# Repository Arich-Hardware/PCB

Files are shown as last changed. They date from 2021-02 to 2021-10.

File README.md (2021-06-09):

# PCB

Emphatic ARICH project PCB designs:

```backplane``` -- Backplane prototype and 9x9 version

```readout_trenz``` -- Prototype readout board using Trenz FPGA module

```siPM_Board``` -- SiPM board accommodating 2x2 SiPM arrays

```sipm-breakout``` -- SiPM board test breakout board

Any other designs in the repo are obsolete.

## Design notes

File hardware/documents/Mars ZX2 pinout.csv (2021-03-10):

Mars ZX2 | Pin Numbers |  | Mars ZX2
Xilinx |  |  | Xilinx
Zynq-7000 |  |  | Zynq-7000
CLG400 |  |  | CLG400
R2 |  |  | R2
18 Aug 2016 |  |  | 18 Aug 2016
Signal Name | Top | Bottom | Signal Name
VCC_MOD | 1 | 2 | GND
VCC_MOD | 3 | 4 | IO_B34_L12_MRCC_U18_P
VCC_MOD | 5 | 6 | IO_B34_L12_MRCC_U19_N
VCC_MOD | 7 | 8 | GND
VCC_MOD | 9 | 10 | IO_B34_L11_SRCC_U14_P
VCC_MOD | 11 | 12 | IO_B34_L11_SRCC_U15_N
PWR_EN | 13 | 14 | GND
GND | 15 | 16 | IO_B34_L21_V17_P
IO_B34_L20_T17_P | 17 | 18 | IO_B34_L21_V18_N
IO_B34_L20_R18_N | 19 | 20 | GND
GND | 21 | 22 | IO_B34_L3_PUDC#_U13_P
IO_B34_L2_T12_P | 23 | 24 | IO_B34_L3_V13_N
IO_B34_L2_U12_N | 25 | 26 | GND
GND | 27 | 28 | IO_B34_L1_T11_P
IO_B34_L18_V16_P | 29 | 30 | IO_B34_L1_T10_N
IO_B34_L18_W16_N | 31 | 32 | GND
GND | 33 | 34 | IO_B34_L4_V12_P
IO_B34_L19_R16_P | 35 | 36 | IO_B34_L4_W13_N
IO_B34_L19_VREF_R17_N | 37 | 38 | GND
GND | 39 | 40 | PWR_GOOD
1.8V Key |  |  | 1.8V Key
VCC_1V35 | 41 | 42 | VCC_1V0_PS
IO_B34_L13_MRCC_N18_P | 43 | 44 | IO_B34_L8_W14_P
IO_B34_L13_MRCC_P19_N | 45 | 46 | IO_B34_L8_Y14_N
GND | 47 | 48 | IO_B34_L6_P14_P
IO_B34_L14_SRCC_N20_P | 49 | 50 | IO_B34_L6_VREF_R14_N
IO_B34_L14_SRCC_P20_N | 51 | 52 | GND
VCC_IO_B34 | 53 | 54 | IO_B34_L5_T14_P
IO_B34_L10_V15_P | 55 | 56 | IO_B34_L5_T15_N
IO_B34_L10_W15_N | 57 | 58 | IO_B34_L9_T16_P
IO_B34_L7_Y16_P | 59 | 60 | IO_B34_L9_U17_N
IO_B34_L7_Y17_N | 61 | 62 | VCC_IO_B34
GND | 63 | 64 | IO_B34_L24_P15_P
IO_B34_L17_Y18_P | 65 | 66 | IO_B34_L24_P16_N
IO_B34_L17_Y19_N | 67 | 68 | IO_B34_L23_N17_P
IO_B34_L22_W18_P | 69 | 70 | IO_B34_L23_P18_N
IO_B34_L22_W19_N | 71 | 72 | GND
VCC_IO_B34 | 73 | 74 | IO_B34_L16_V20_P
IO_B35_L21_AD14_N15_P | 75 | 76 | IO_B34_L16_W20_N
IO_B35_L21_AD14_N16_N | 77 | 78 | IO_B34_L15_T20_P
IO_B35_L7_AD2_M19_P | 79 | 80 | IO_B34_L15_U20_N
IO_B35_L7_AD2_M20_N | 81 | 82 | VCC_IO_B35
GND | 83 | 84 | IO_B35_L23_M14_P
IO_B35_L13_MRCC_H16_P | 85 | 86 | IO_B35_L23_M15_N
IO_B35_L13_MRCC_H17_N | 87 | 88 | GND
VCC_1V8_PS | 89 | 90 | IO_B35_L22_AD7_L14_P
IO_B35_L9_AD3_L19_P | 91 | 92 | IO_B35_L22_AD7_L15_N
IO_B35_L9_AD3_L20_N | 93 | 94 | VCC_1V8_PS
GND | 95 | 96 | IO_B35_L20_AD6_K14_P
IO_B35_L10_AD11_K19_P | 97 | 98 | IO_B35_L20_AD6_J14_N
IO_B35_L10_AD11_J19_N | 99 | 100 | GND
VCC_1V8_PS | 101 | 102 | IO_B35_L19_H15_P
IO_B35_L14_AD4_SRCC_J18_P | 103 | 104 | IO_B35_L19_VREF_G15_N
IO_B35_L14_AD4_SRCC_H18_N | 105 | 106 | VCC_1V8_PS
GND | 107 | 108 | IO_B35_L8_AD10_M17_P
IO_B35_L17_AD5_J20_P | 109 | 110 | IO_B35_L8_AD10_M18_N
IO_B35_L17_AD5_H20_N | 111 | 112 | IO_B35_L12_MRCC_K17_P
IO_B35_L18_AD13_G19_P | 113 | 114 | IO_B35_L12_MRCC_K18_N
IO_B35_L18_AD13_G20_N | 115 | 116 | GND
VCC_IO_B35 | 117 | 118 | IO_B35_L24_AD15_K16_P
IO_B35_L15_AD12_F19_P | 119 | 120 | IO_B35_L24_AD15_J16_N
IO_B35_L15_AD12_F20_N | 121 | 122 | IO_B35_L16_G17_P
IO_B35_L4_D19_P | 123 | 124 | IO_B35_L16_G18_N
IO_B35_L4_D20_N | 125 | 126 | VCC_IO_B35
GND | 127 | 128 | IO_B35_L11_SRCC_L16_P
IO_B35_L1_AD0_C20_P | 129 | 130 | IO_B35_L11_SRCC_L17_N
IO_B35_L1_AD0_B20_N | 131 | 132 | IO_B35_L6_F16_P
IO_B35_L2_AD8_B19_P | 133 | 134 | IO_B35_L6_VREF_F17_N
IO_B35_L2_AD8_A20_N | 135 | 136 | GND
VCC_CFG_MIO_B13 | 137 | 138 | IO_B35_L5_AD9_E18_P
IO_MIO40_B13_L16_W10 | 139 | 140 | IO_B35_L5_AD9_E19_N
IO_MIO41_B13_L16_W9 | 141 | 142 | IO_B35_L3_AD1_E17_P
IO_MIO42_B13_L18_W11 | 143 | 144 | IO_B35_L3_AD1_D18_N
IO_MIO43_B13_L18_Y11 | 145 | 146 | VCC_CFG_MIO_B13
GND | 147 | 148 | IO_MIO48_B13_L11_SRCC_U7
IO_MIO44_B13_L14_SRCC_Y9 | 149 | 150 | IO_MIO49_B13_L11_V7
IO_MIO45_B13_L14_Y8 | 151 | 152 | IO_MIO50_B13_L12_MRCC_T9
IO_MIO46_B13_L19_T5 | 153 | 154 | IO_MIO51_B13_L12_U10
IO_MIO47_B13_L19_U5 | 155 | 156 | GND
GND | 157 | 158 | JTAG_TCK
USB_D_P | 159 | 160 | JTAG_TDI
USB_D_N | 161 | 162 | JTAG_TMS
USB_VBUS | 163 | 164 | JTAG_TDO
USB_ID | 165 | 166 | USB_CPEN
GND | 167 | 168 | - (*6)
ETH_A_N | 169 | 170 | -
ETH_A_P | 171 | 172 | GND
ETH_LED1# | 173 | 174 | I2C_INT#
ETH_LED2# | 175 | 176 | I2C_SDA
ETH_B_N | 177 | 178 | I2C_SCL
ETH_B_P | 179 | 180 | GND
ETH_CTREF | 181 | 182 | FLASH_CLK
ETH_C_N | 183 | 184 | FLASH_DO
ETH_C_P | 185 | 186 | FLASH_DI
- | 187 | 188 | FLASH_CS#
- | 189 | 190 | BOOT_MODE
ETH_D_N | 191 | 192 | PS_SRST#
ETH_D_P | 193 | 194 | FPGA_DONE
GND | 195 | 196 | PS_POR#
VCC_3V3 | 197 | 198 | VMON_1V2
VCC_3V3 | 199 | 200 | VCC_BAT

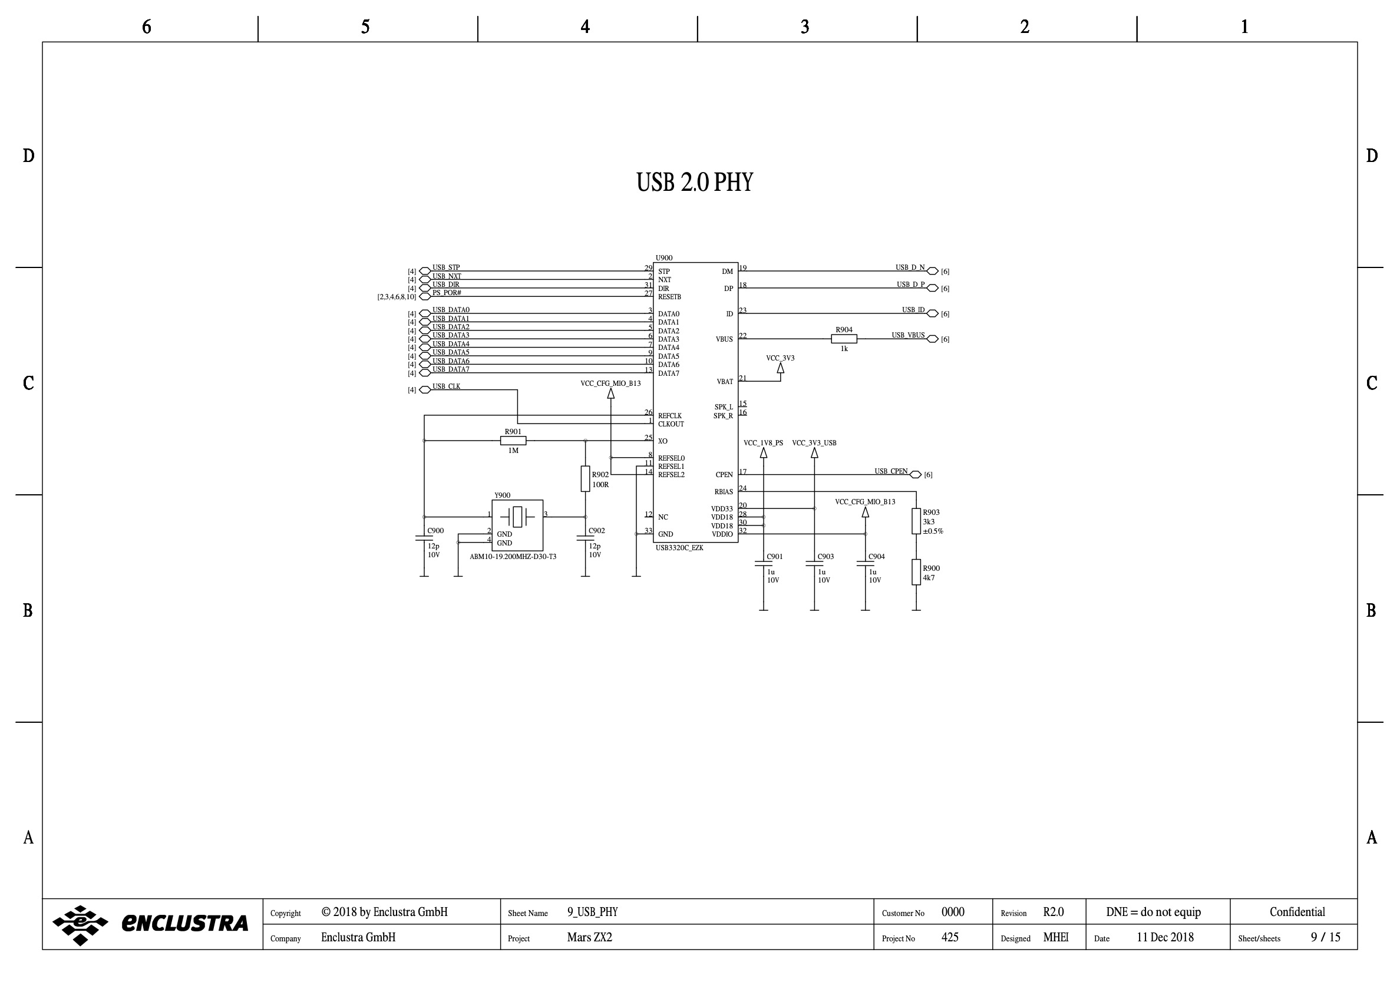
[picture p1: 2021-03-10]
hardware/documents/Mars_ZX2-R2-0_User_Schematics_V3.jpg

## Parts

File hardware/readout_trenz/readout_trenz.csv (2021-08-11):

Reference | Quantity | Value | Footprint | Datasheet | Item Cost | MFN | Manufacturer | Supplier | Supplier P/N
C101 | 1 | 47uF | Capacitor_SMD:C_0805_2012Metric_Pad1.15x1.40mm_HandSolder | https://www.we-online.de/katalog/datasheet/885012107006.pdf | $0.79 | 885012107006 | Würth Elektronik | Digi-Key | 732-7617-1-ND
C179 C181 C183 | 3 | 470uF | readout_trenz:EEE-0JA471UAP | https://industrial.panasonic.com/cdbs/www-data/pdf/RDE0000/ABA0000C1142.pdf | $0.74 | EEE-0JA471UAP | Panasonic Electronic Components | Digi-Key | PCE4564CT-ND
C180 C182 C184 | 3 | 100uF | readout_trenz:EEE-0JA101WR | https://media.digikey.com/pdf/Data%20Sheets/Panasonic%20Electronic%20Components/S_Series,Type_V_Rev2018.pdf | $0.35 | EEE-0JA101WR | Panasonic Electronic Components | Digi-Key | PCE3853CT-ND
C1 C2 C6 C20 C21 C22 C23 C24 C25 C26 C27 C28 C29 C30 C31 C32 C33 C34 C35 C36 C69 C70 C71 C72 C73 C74 C75 C76 C78 C81 C83 C84 C87 C88 C91 C92 C93 C94 C97 C98 C99 C100 C102 C106 C107 C108 C109 C110 C111 C112 C113 C114 C115 C116 C117 C118 C119 C120 C121 C122 C155 C156 C157 C158 C159 C160 C161 C162 C164 C167 C169 C170 C173 C174 C177 C178 | 76 | 0.1uF | Capacitor_SMD:C_0603_1608Metric_Pad1.05x0.95mm_HandSolder | https://www.we-online.de/katalog/datasheet/885012206046.pdf | $0.1 | 885012206046 | Würth Elektronik | Digi-Key | 732-7965-1-ND
C37 C38 C39 C40 C41 C42 C43 C44 C45 C46 C47 C48 C49 C50 C51 C52 C53 C54 C55 C56 C57 C58 C59 C60 C61 C62 C63 C64 C65 C66 C67 C68 C123 C124 C125 C126 C127 C128 C129 C130 C131 C132 C133 C134 C135 C136 C137 C138 C139 C140 C141 C142 C143 C144 C145 C146 C147 C148 C149 C150 C151 C152 C153 C154 | 64 | 0.1uF | Capacitor_SMD:C_0402_1005Metric | https://www.we-online.de/katalog/datasheet/885012205037.pdf | $0.1 | 885012205037 | Würth Elektronik | Digi-Key | 732-7532-1-ND
C4 | 1 | 10nF | Capacitor_SMD:C_0603_1608Metric_Pad1.05x0.95mm_HandSolder | https://www.we-online.de/katalog/datasheet/885342206006.pdf | $0.1 | 885342206006 | Würth Elektronik | Digi-Key | 732-12168-1-ND
C5 | 1 | 2.2uF | Capacitor_SMD:C_0603_1608Metric_Pad1.05x0.95mm_HandSolder | https://www.we-online.de/katalog/datasheet/885012106011.pdf | $0.16 | 885012106011 | Würth Elektronik | Digi-Key | 732-7908-1-ND
C3 C7 C8 C12 C13 C17 C18 C19 C103 C104 C105 | 11 | 1uF | Capacitor_SMD:C_0603_1608Metric_Pad1.05x0.95mm_HandSolder | https://www.we-online.de/katalog/datasheet/885012106010.pdf | $0.15 | 885012106010 | Würth Elektronik | Digi-Key | 732-7907-1-ND
C77 C79 C80 C82 C85 C86 C163 C165 C166 C168 C171 C172 | 12 | 150pF | Capacitor_SMD:C_0603_1608Metric_Pad1.05x0.95mm_HandSolder | https://www.we-online.de/katalog/datasheet/885012206103.pdf | $0.1 | 885012206103 | Würth Elektronik | Digi-Key | 732-12236-1-ND
C9 C10 C11 C14 C15 C16 C89 C90 C175 C176 | 10 | 10uF | Capacitor_SMD:C_0805_2012Metric_Pad1.15x1.40mm_HandSolder | https://www.we-online.de/katalog/datasheet/885012107010.pdf | $0.18 | 885012107010 | Würth Elektronik | Digi-Key | 732-7620-1-ND
C95 C96 | 2 | 22uF | Capacitor_SMD:C_0805_2012Metric_Pad1.15x1.40mm_HandSolder | https://www.we-online.de/katalog/datasheet/885012107011.pdf | $0.59 | 885012107011 | Würth Elektronik | Digi-Key | 732-7621-1-ND
D1 D2 D3 D4 D5 D6 D7 D8 D9 D12 | 10 | Red_LED | LED_THT:LED_D3.0mm | https://www.we-online.de/katalog/datasheet/151031SS06000.pdf | $0.17 | 151031SS06000 | Würth Elektronik | Digi-Key | 732-5006-ND
D10 | 1 | Yellow_LED | LED_THT:LED_D3.0mm | https://www.we-online.de/katalog/datasheet/151031YS05900.pdf | $0.17 | 151031YS05900 | Würth Elektronik | Digi-Key | 732-5009-ND
D11 | 1 | Blue_LED | LED_THT:LED_D3.0mm | https://www.ttelectronics.com/TTElectronics/media/ProductFiles/Optoelectronics/Datasheets/OVLBx4C7.pdf | $0.37 | OVLBB4C7 | TT Electronics/Optek Technology | Digi-Key | 365-1173-ND
D13 | 1 | Green_LED | LED_THT:LED_D3.0mm | https://www.we-online.de/katalog/datasheet/151031VS06000.pdf | $0.16 | 151031VS06000 | Würth Elektronik | Digi-Key | 732-5008-ND
GND1 GND2 GND3 GND4 GND5 GND6 GND7 GND8 | 8 | TestPoint | TestPoint:TestPoint_Keystone_5000-5004_Miniature | https://www.keyelco.com/userAssets/file/M65p56.pdf | $0.42 | 5001 | Keystone Electronics | Digi-Key | 36-5001-ND
H1 H2 | 2 | MountingHole | readout_trenz:MountingHole_0.11'' | ~
J7 J8 J9 J10 J11 J12 | 6 | ERM8-060-05.0-L-DV | readout_trenz:ERM8-060-XX-X-D-RA | http://suddendocs.samtec.com/prints/erm8-xxx-xx-x-d-ra-xx-footprint.pdf | $13.11 | ERM8-060-01-L-D-RA-K-TR | Samtec | Digi-Key | SAM13809CT-ND
J13 | 1 | Digilent JTAG header | readout_trenz:87832-1420 | https://media.digikey.com/pdf/Data%20Sheets/Molex%20PDFs/87832-300_Pkg_Spec.pdf | $2.04 | 0878321420 | Molex | Digi-Key | WM18641-ND
J14 | 1 | SparkfunFT232RL | readout_trenz:Sparkfun-FT232RL | https://cdn.sparkfun.com/datasheets/BreakoutBoards/DS_FT232R.pdf | $15.95 | BOB-12731 | SparkFun Electronics | Digi-Key | 1568-1195-ND
J15 | 1 | TrenzSFP+cage | Connector:Connector_SFP_and_Cage | https://www.te.com/commerce/DocumentDelivery/DDEController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 | $2.65 | 2227023-1, 1888247-1 | TE Connectivity AMP Connectors | Digi-Key | A120615-ND, A97943CT-ND
J16 | 1 | Conn_01x03 | Connector_PinHeader_2.54mm:PinHeader_1x03_P2.54mm_Vertical | https://app.adam-tech.com/products/download/data_sheet/201605/ph1-xx-ua-data-sheet.pdf | $0.1 | PH1-01-UA | Adam Tech | Digi-Key | 2057-PH1-01-UA-ND
J17 | 1 | Trenz_Module | readout_trenz:Trenz_Module | http://suddendocs.samtec.com/catalog_english/lshm_dv.pdf | $10.37 | LSHM-150-04.0-F-DV-A-S-K-TR | Samtec Inc. | Digi-Key | SAM14152CT-ND
J18 | 1 | Conn_02x05_Odd_Even | readout_trenz:10129383-910002ALF | https://cdn.amphenol-icc.com/media/wysiwyg/files/drawing/10129383.pdf | $0.26 | 10129383-910002ALF | Amphenol ICC (FCI) | Digi-Key | 609-10129383-910002ALFCT-ND
J1 J2 J6 J19 | 4 | DNP | readout_trenz:lemo-EPB.00.250.NTN | https://www.lemo.com/pdf/EPB.00.250.NTN.pdf | $20.34 | EPB.00.250.NTN | LEMO | Digi-Key | 1124-1424-ND
J3 | 1 | Conn_Coaxial_Power | Connector_BarrelJack:BarrelJack_Wuerth_6941xx301002 | https://www.we-online.de/katalog/datasheet/6941xx301002.pdf | $0.96 | 694106301002 | Würth Elektronik | Digi-Key | 732-5930-ND
J4 | 1 | Conn_02x05_Odd_Even | Connector_PinHeader_2.54mm:PinHeader_2x04_P2.54mm_Vertical | https://cdn.amphenol-icc.com/media/wysiwyg/files/drawing/10129383.pdf | $0.26 | 10129383-910002ALF | Amphenol ICC (FCI) | Digi-Key | 609-10129383-910002ALFCT-ND
J5 | 1 | DC_TO_DC | readout_trenz:DC_TO_DC | https://media.digikey.com/pdf/Data%20Sheets/Sullins%20PDFs/Female_Headers.100_DS.pdf | $0.71 | PPPC052LFBN-RC | Sullins Connector Solutions | Digi-Key | S7108-ND
JP1 JP2 | 2 | Jumper | Connector_PinHeader_2.54mm:PinHeader_1x02_P2.54mm_Vertical | https://cdn.harwin.com/pdfs/C001XX_M20_Series_Connectors.pdf | $0.19 | M20-9990345 | Harwin Inc. | Digi-Key | 952-2263-ND
L1 L2 | 2 | 4.7uH | readout_trenz:A914BYW-4R7M=P3 | https://search.murata.co.jp/Ceramy/image/img/P02/J(E)TE243B-0045_D52LC_reference.pdf | $0.98 | #A914BYW-4R7M=P3 | Murata Electronics | Digi-Key | 490-#A914BYW-4R7M=P3CT-ND
Q1 Q2 Q3 Q4 Q5 Q6 Q7 | 7 | N-MOSFET | Package_TO_SOT_SMD:SOT-416 | https://fscdn.rohm.com/en/products/databook/datasheet/discrete/transistor/mosfet/re1c002untcl-e.pdf | $0.21 | RE1C002UNTCL | Rohm Semiconductor | Digi-Key | RE1C002UNTCLCT-ND
R11 R58 R59 R60 R66 R67 R68 R69 R70 R119 R120 R121 | 12 | 4.7k | Resistor_SMD:R_1206_3216Metric_Pad1.42x1.75mm_HandSolder | http://www.passivecomponent.com/wp-content/uploads/chipR/ASC_WR.pdf | $0.1 | WR12X4701FTL | Walsin Technology Corporation | Digi-Key | 1292-WR12X4701FTLCT-ND
R12 R13 R14 R71 R72 R74 R75 | 7 | 56 | Resistor_SMD:R_0603_1608Metric_Pad1.05x0.95mm_HandSolder | https://www.yageo.com/upload/media/product/productsearch/datasheet/rchip/PYu-RT_1-to-0.01_RoHS_L_12.pdf | $0.1 | RT0603FRE0756RL | Yageo | Digi-Key | 13-RT0603FRE0756RLCT-ND
R10 R15 R16 | 3 | 80 | Resistor_SMD:R_0603_1608Metric_Pad1.05x0.95mm_HandSolder | https://industrial.panasonic.com/cdbs/www-data/pdf/RDA0000/AOA0000C304.pdf | $0.1 | ERJ-3EKF82R0V | Panasonic Electronic Components | Digi-Key | P82.0HCT-ND
R1 R2 R17 R18 R19 R20 R21 R22 R23 R24 R25 R26 R27 R28 R29 R30 R31 R32 R33 R34 R35 R36 R37 R38 R39 R40 R41 R42 R43 R44 R45 R46 R47 R48 R78 R79 R80 R81 R82 R83 R84 R85 R86 R87 R88 R89 R90 R91 R92 R93 R94 R95 R96 R97 R98 R99 R100 R101 R102 R103 R104 R105 R106 R107 R108 R109 | 66 | 49.9 | Resistor_SMD:R_0402_1005Metric | https://www.yageo.com/upload/media/product/productsearch/datasheet/rchip/PYu-AF_51_RoHS_L_6.pdf | $0.1 | AF0402FR-0749R9L | Yageo | Digi-Key | 13-AF0402FR-0749R9LCT-ND
R3 R4 R56 R57 R117 R118 | 6 | 100 | Resistor_SMD:R_0603_1608Metric_Pad1.05x0.95mm_HandSolder | https://www.bourns.com/docs/product-datasheets/crxxxxa.pdf | $0.01 | CR0603AFX-1000ELF | Bourns Inc. | Digi-Key | 118-CR0603AFX-1000ELFCT-ND
R49 R50 R51 R52 R53 R54 R55 R110 R111 R112 R113 R114 R115 R116 | 14 | 1k | Resistor_SMD:R_0603_1608Metric_Pad1.05x0.95mm_HandSolder | https://www.yageo.com/upload/media/product/productsearch/datasheet/rchip/PYu-RC_Group_51_RoHS_L_11.pdf | $0.1 | RC0603JR-071KL | Yageo | Digi-Key | 311-1.0KGRCT-ND
R5 | 1 | 470 | Resistor_SMD:R_0805_2012Metric_Pad1.15x1.40mm_HandSolder | https://industrial.panasonic.com/cdbs/www-data/pdf/RDM0000/AOA0000C307.pdf | $0.1 | ERA-6AED471V | Panasonic Electronic Components | Digi-Key | P123851CT-ND
R6 | 1 | 140 | Resistor_SMD:R_0603_1608Metric_Pad1.05x0.95mm_HandSolder | https://www.yageo.com/upload/media/product/productsearch/datasheet/rchip/PYu-RC_Group_51_RoHS_L_11.pdf | $0.1 | RC0603FR-07140RL | Yageo | Digi-Key | 311-140HRCT-ND
R61 R62 | 2 | 10k | Resistor_SMD:R_1206_3216Metric_Pad1.42x1.75mm_HandSolder | https://www.vishay.com/docs/28773/crcwce3.pdf | $0.1 | CRCW120610K0FKEAC | Vishay Dale | Digi-Key | 541-3983-1-ND
R63 | 1 | 0.1 | Resistor_SMD:R_0603_1608Metric_Pad1.05x0.95mm_HandSolder | https://industrial.panasonic.com/cdbs/www-data/pdf/RDN0000/AOA0000C313.pdf | $0.23 | ERJ-3RSJR10V | Panasonic Electronic Components | Digi-Key | P.10AHCT-ND
R64 R65 | 2 | 0.5 | Resistor_SMD:R_0603_1608Metric_Pad1.05x0.95mm_HandSolder | https://www.yageo.com/upload/media/product/productsearch/datasheet/rchip/PYu-RL_Group_521_RoHS_L_2.pdf | $0.25 | RL0603JR-070R5L | Yageo | Digi-Key | 13-RL0603JR-070R5LCT-ND
R7 | 1 | 470k | Resistor_SMD:R_1206_3216Metric_Pad1.42x1.75mm_HandSolder | https://www.yageo.com/upload/media/product/productsearch/datasheet/rchip/PYu-RC_Group_51_RoHS_L_11.pdf | $0.1 | RC1206FR-07470KL | Yageo | Digi-Key | 311-470KFRCT-ND
R73 | 1 | 33 | Resistor_SMD:R_0603_1608Metric_Pad1.05x0.95mm_HandSolder | https://www.vishay.com/docs/20035/dcrcwe3.pdf | $0.1 | CRCW060333R0JNEA | Vishay Dale | Digi-Key | 541-33GCT-ND
R76 | 1 | DNP | Resistor_SMD:R_0603_1608Metric_Pad1.05x0.95mm_HandSolder | ~
R77 | 1 | 0 | Resistor_SMD:R_0603_1608Metric_Pad1.05x0.95mm_HandSolder | https://www.yageo.com/upload/media/product/productsearch/datasheet/rchip/PYu-RC_Group_51_RoHS_L_11.pdf | $0.1 | AC0603JR-130RL | Yageo | Digi-Key | 13-AC0603JR-130RLCT-ND
R8 | 1 | 1k | Resistor_SMD:R_0805_2012Metric_Pad1.15x1.40mm_HandSolder | https://www.yageo.com/upload/media/product/productsearch/datasheet/rchip/PYu-RC_Group_51_RoHS_L_11.pdf | $0.1 | RC0805FR-071KL | Yageo | Digi-Key | 311-1.00KCRCT-ND
R9 | 1 | 900 | Resistor_SMD:R_1206_3216Metric_Pad1.42x1.75mm_HandSolder | https://www.vishay.com/docs/60024/pat.pdf | $0.94 | PAT1206E9000BST1 | Vishay Dale Thin Film | Digi-Key | PAT900CCT-ND
RV1 | 1 | 10k | Potentiometer_THT:Potentiometer_ACP_CA6-H2,5_Horizontal | https://www.bourns.com/docs/product-datasheets/3296.pdf | $2.41 | 3296Z-1-103LF | Bourns Inc. | Digi-Key | 3296Z-103LF-ND
TP1 TP2 TP3 TP4 TP5 TP6 TP7 TP8 TP9 TP10 TP11 TP12 TP14 TP15 TP16 TP17 TP18 TP19 TP20 TP21 TP22 TP23 TP24 TP25 | 24 | TestPoint | readout_trenz:TestPoint_Pad_30x30mils | ~
TP13 TP26 | 2 | probe | TestPoint:TestPoint_2Pads_Pitch2.54mm_Drill0.8mm | ~
U1 U10 U15 U18 U23 | 5 | SN74AXC2T45DCTR | Package_SO:SSOP-8_2.95x2.8mm_P0.65mm | https://www.ti.com/lit/ds/symlink/sn74axc2t45.pdf?ts=1624298260694 | $0.66 | SN74AXC2T45DCTR | Texas Instruments | Digi-Key | 296-SN74AXC2T45DCCT-ND
U11 U12 U19 U20 | 4 | NLSV8T244 | Package_SO:TSSOP-20_4.4x6.5mm_P0.65mm | https://www.onsemi.com/pdf/datasheet/nlsv8t244-d.pdf | $1.52 | NLSV8T244DTR2G | ON Semiconductors | Digi-Key | NLSV8T244DTR2GOSCT-ND
U13 U21 | 2 | DS90LV027A | Package_SO:SOIC-8_3.9x4.9mm_P1.27mm | https://www.ti.com/lit/ds/symlink/ds90lv027a.pdf?ts=1624298607733 | $1.92 | DS90LV027ATM/NOPB | Texas Instruments | Digi-Key | DS90LV027ATM/NOPB-ND
U14 U22 | 2 | ADS7955 | Package_SO:TSSOP-30_4.4x7.8mm_P0.5mm | https://www.ti.com/lit/ds/symlink/ads7950.pdf?HQS=dis-dk-null-digikeymode-dsf-pf-null-wwe&ts=1617477435304 | $6.74 | ADS7955SDBT | Texas Instruments | Digi-Key | 296-23507-5-ND
U16 | 1 | NTB0102-Q100 | Package_SO:TSSOP-8_3x3mm_P0.65mm | https://www.nxp.com/docs/en/data-sheet/NTB0102_Q100.pdf | $1.04 | NTB0102DP-Q100H | NXP USA Inc. | Digi-Key | 568-12374-1-ND
U2 | 1 | LP2985-5.0 | Package_TO_SOT_SMD:SOT-23-5_HandSoldering | http://www.ti.com/lit/ds/symlink/lp2985.pdf | $0.66 | LP2985A-50DBVT | Texas Instruments | Digi-Key | 296-32159-1-ND
U3 | 1 | REF5025 | Package_SO:SOIC-8_3.9x4.9mm_P1.27mm | https://www.ti.com/lit/ds/symlink/ref5025-ep.pdf?HQS=dis-dk-null-digikeymode-dsf-pf-null-wwe&ts=1617653432745 | $4.05 | REF5025AID | Texas Instruments | Digi-Key | 296-22203-5-ND
U4 U5 | 2 | NCP718xSN180 | Package_TO_SOT_SMD:TSOT-23-5_HandSoldering | https://www.onsemi.com/pub/Collateral/NCP718-D.PDF | $0.53 | NCP718ASN180T1G | ON Semiconductor | Digi-Key | NCP718ASN180T1GOSCT-ND
U6 U7 U8 | 3 | LT1963AxQ-3.3 | Package_TO_SOT_SMD:TO-263-5_TabPin3 | https://www.analog.com/media/en/technical-documentation/data-sheets/1963aff.pdf | $6.69 | LT1963AEQ-3.3#PBF | Analog Devices Inc. | Digi-Key | LT1963AEQ-3.3#PBF-ND
U9 U17 | 2 | CITIROC1A | readout_trenz:QFP-160_26x26_Pitch0.65mm | http://gauss.bu.edu/svn/emphatic-doco/Docs/CITIROC1A%20-%20Datasheet%20V2.5.pdf |  |  | Weeroc
X1 | 1 | ASA2-25.000MHZ | readout_trenz:ASA2-25.000MHZ | https://abracon.com/Oscillators/ASCO.pdf | $2.27 | ASA2-25.000MHZ-L-T | Abracon LLC | Digi-Key | 535-11704-1-ND

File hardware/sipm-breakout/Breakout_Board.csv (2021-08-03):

Reference | Quantity | Value | Footprint | Datasheet | Item Cost | MFN | Supplier | Supplier P/N | CatNo
H1 H2 H3 H4 | 4 | MountingHole_Pad | MountingHole:MountingHole_4.3mm_M4_Pad | ~ |  |  |  |  | DNP
J1 J2 | 2 | Conn_02x34_Odd_Even | Readout_Board_Parts:SAMTEC_CLM-134-02-F-D | http://suddendocs.samtec.com/catalog_english/clm_sm.pdf | $9.02 | CLM-134-02-F-D | Digi-Key | CLM-134-02-F-D-ND
J14 | 1 | DNP | Breakout_Board_Parts:lemo-EPB.00.250.NTN | ~
J15 J16 | 2 | Conn_01x01_Female | generic-test-pcb:Banana_Pomona_73099 | ~ |  | 73099-0 | Digi-Key | 501-73099-0-ND
J3 J4 | 2 | Conn_02x32_Odd_Even | Connector_PinHeader_2.00mm:PinHeader_2x32_P2.00mm_Vertical_SMD | ~ |  | TMM-132-01-T-D-SM | Digi-Key | SAM1171-32-ND
J5 | 1 | Conn_02x04_Odd_Even | Connector_PinSocket_2.54mm:PinSocket_2x04_P2.54mm_Vertical | ~ |  | PH2-08-UA | Digi-Key | 2057-PH2-08-UA-ND
J6 | 1 | Conn_01x04 | Connector_PinHeader_2.54mm:PinHeader_1x04_P2.54mm_Vertical |  | $0.10 | PH1-04-UA | Digi-Key | 2057-PH1-04-UA-ND
J7 J8 J9 J10 J11 J12 J13 J17 J18 J19 J20 J21 J22 J23 J24 | 15 | DNP | Readout_Board_Parts:lemo-EPB.00.250.NTN | ~
RN1 RN2 RN3 RN4 RN5 RN6 RN7 RN8 | 8 | R_Network08_US | Breakout_Board_Parts:RPKG-9 | http://www.vishay.com/docs/31509/csc.pdf |  |  | Digi_key | 752091103GP-ND

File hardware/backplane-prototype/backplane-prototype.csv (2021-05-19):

Source: | /Users/tejasva/PCB/hardware/backplane-prototype/backplane-prototype.sch
Date: | Wednesday, May 12, 2021 at 02:38:03 PM
Tool: | Eeschema (5.1.9-0-10_14)
Component Count: | 3
Ref | Value | Manufacturer | MFN | Supplier | Supplier P/N | Quantity | Unit Price
J1 | Conn_02x34_Odd_Even | Samtec | CLM-134-02-F-D | Samtec | CLM-134-02-F-D | 5 | $8.49
J2 | ERF8-060-05.0-L-DV | Samtec | ERF8-060-05.0-L-DV-L-K-TR | Samtec | ERF8-060-05.0-L-DV-L-K-TR | 5 | $8.16
J3 | Conn_02x34_Odd_Even | Samtec | CLM-134-02-F-D | Samtec | CLM-134-02-F-D | 5 | $8.49

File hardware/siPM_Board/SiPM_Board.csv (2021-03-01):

Source | /home/hazen/work/ARICH/PCB/hardware/siPM_Board/trunk/SiPM_Board.sch
Kicad Rev | Eeschema 5.1.9-73d0e3b20d~88~ubuntu20.04.1
Generated Date | Mon 01 Mar 2021 10:09:39 AM EST
Title | SiPM Schematic
Company | Electronics Design Facility
Revision | Not Set
Date Issue | 2021-02-24
Comment | Final Draft
Reference | Value | Item Cost | MFN | Supplier | Supplier P/N | Library | Library Ref
J1 | Conn_02x34_Odd_Even | $0 | MW-34-03-G-D-245-065-ES | Samtec | MW-34-03-G-D-245-065-ES | Connector_Generic | Conn_02x34_Odd_Even
U5 | S14161-6050HS-04 | Arich_SiPM_Board_Parts | S14161-6050HS-04
J2 | Conn_02x34_Odd_Even | $0 | MW-34-03-G-D-245-065-ES | Samtec | MW-34-03-G-D-245-065-ES | Connector_Generic | Conn_02x34_Odd_Even
U2 | S14161-6050HS-04 | Arich_SiPM_Board_Parts | S14161-6050HS-04
U3 | S14161-6050HS-04 | Arich_SiPM_Board_Parts | S14161-6050HS-04
C16 | 100nF | $0.12 | 0603B104K101CT | Digi-Key | 1292-1392-1-ND | Device | C
C14 | 100nF | $0.12 | 0603B104K101CT | Digi-Key | 1292-1392-1-ND | Device | C
U4 | S14161-6050HS-04 | Arich_SiPM_Board_Parts | S14161-6050HS-04
C8 | 100nF | $0.12 | 0603B104K101CT | Digi-Key | 1292-1392-1-ND | Device | C
C6 | 100nF | $0.12 | 0603B104K101CT | Digi-Key | 1292-1392-1-ND | Device | C
C17 | 100nF | $0.12 | 0603B104K101CT | Digi-Key | 1292-1392-1-ND | Device | C
C15 | 100nF | $0.12 | 0603B104K101CT | Digi-Key | 1292-1392-1-ND | Device | C
C9 | 100nF | $0.12 | 0603B104K101CT | Digi-Key | 1292-1392-1-ND | Device | C
U1 | LM94021 | $1.28 | LM94021BIMG/NOPB | Digi-Key | LM94021BIMG/NOPBCT-ND | Arich_SiPM_Board_Parts | LM94021
C3 | 100nF | $0.12 | 0603B104K101CT | Digi-Key | 1292-1392-1-ND | Device | C
C1 | 100nF | $0.12 | 0603B104K101CT | Digi-Key | 1292-1392-1-ND | Device | C
C4 | 100nF | $0.12 | 0603B104K101CT | Digi-Key | 1292-1392-1-ND | Device | C
C2 | 100nF | $0.12 | 0603B104K101CT | Digi-Key | 1292-1392-1-ND | Device | C
C13 | 100nF | $0.12 | 0603B104K101CT | Digi-Key | 1292-1392-1-ND | Device | C
C11 | 100nF | $0.12 | 0603B104K101CT | Digi-Key | 1292-1392-1-ND | Device | C
C12 | 100nF | $0.12 | 0603B104K101CT | Digi-Key | 1292-1392-1-ND | Device | C
C10 | 100nF | $0.12 | 0603B104K101CT | Digi-Key | 1292-1392-1-ND | Device | C
C5 | 100nF | $0.12 | 0603B104K101CT | Digi-Key | 1292-1392-1-ND | Device | C
C7 | 100nF | $0.12 | 0603B104K101CT | Digi-Key | 1292-1392-1-ND | Device | C

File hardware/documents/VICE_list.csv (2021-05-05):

Reference | Value | Footprint | Datasheet | Supplier | Supplier P/N | notes | Supplier Part | Supplier S/N
U3 | SI590B | mod:Si590
C6 | 10nF | mod:C_0402
R8 | DNP | mod:C_0603_HandSoldering
R9 | DNP | mod:C_0603_HandSoldering
R2 | DNP | mod:C_0805_HandSoldering
R3 | DNP | mod:C_0805_HandSoldering
P2 | CONN_01X02
P1 | PINS_1x4 | mod:Molex-1723102204
R34 | 0 | mod:SMD-1210_Pol |  | Digikey | RMCF1210ZT0R00CT-ND
J2 | ERNI-154765 | mod:ERNI-154765
R11 | DNP | mod:C_0603_HandSoldering
R10 | DNP | mod:C_0603_HandSoldering
J1 | ERNI-154742 | mod:ERNI-154742
R31 | DNP | mod:C_0805_HandSoldering
R26 | DNP | mod:C_0603_HandSoldering
J3 | ERNI-154742 | mod:ERNI-154742
J4 | ERNI-154765 | mod:ERNI-154765
U1 | XC7A50T-FGH484 | mod:XC7A-FGG484
U6 | SI590B | mod:Si590
C11 | 10nF | mod:C_0201
R13 | DNP | mod:C_0603_HandSoldering
R14 | DNP | mod:C_0603_HandSoldering
R12 | 100 | mod:C_0201 |  | 1%
C8 | 0.1uF | mod:C_0402
C9 | 0.1uF | mod:C_0402
U20 | Stitch | mod:Stitch
U21 | Stitch | mod:Stitch
U22 | Stitch | mod:Stitch
U23 | Stitch | mod:Stitch
U24 | Stitch | mod:Stitch
U25 | Stitch | mod:Stitch
C14 | 47uF | mod:SM1210 |  | Digi-key | 490-6542-1-ND
C32 | 0.47uF | mod:C_0603_HandSoldering |  | Digi-key | 490-6416-1-ND
C17 | 4.7uF | mod:C_0805_HandSoldering |  | Digi-key | 490-6479-1-ND
C20 | 4.7uF | mod:C_0805_HandSoldering |  | Digi-key | 490-6479-1-ND
C23 | 0.47uF | mod:C_0603_HandSoldering |  | Digi-key | 490-6416-1-ND
C26 | 0.47uF | mod:C_0603_HandSoldering |  | Digi-key | 490-6416-1-ND
C29 | 0.47uF | mod:C_0603_HandSoldering |  | Digi-key | 490-6416-1-ND
C12 | 47uF | mod:SM1210 |  | Digi-key | 490-6542-1-ND
C30 | 0.47uF | mod:C_0603_HandSoldering |  | Digi-key | 490-6416-1-ND
C15 | 4.7uF | mod:C_0805_HandSoldering |  | Digi-key | 490-6479-1-ND
C18 | 4.7uF | mod:C_0805_HandSoldering |  | Digi-key | 490-6479-1-ND
C21 | 0.47uF | mod:C_0603_HandSoldering |  | Digi-key | 490-6416-1-ND
C24 | 0.47uF | mod:C_0603_HandSoldering |  | Digi-key | 490-6416-1-ND
C27 | 0.47uF | mod:C_0603_HandSoldering |  | Digi-key | 490-6416-1-ND
C33 | 47uF | mod:C_0805_HandSoldering |  | Digi-key | 490-6542-1-ND
C45 | 0.47uF | mod:C_0805_HandSoldering |  | Digi-key | 490-6416-1-ND
C35 | 4.7uF | mod:C_0805_HandSoldering |  | Digi-key | 490-6479-1-ND
C37 | 4.7uF | mod:C_0805_HandSoldering |  | Digi-key | 490-6479-1-ND
C39 | 0.47uF | mod:C_0805_HandSoldering |  | Digi-key | 490-6416-1-ND
C41 | 0.47uF | mod:C_0805_HandSoldering |  | Digi-key | 490-6416-1-ND
C43 | 0.47uF | mod:C_0805_HandSoldering |  | Digi-key | 490-6416-1-ND
C13 | 47uF | mod:SM1210 |  | Digi-key | 490-6542-1-ND
C31 | 0.47uF | mod:C_0603_HandSoldering |  | Digi-key | 490-6416-1-ND
C16 | 4.7uF | mod:C_0805_HandSoldering |  | Digi-key | 490-6479-1-ND
C19 | 4.7uF | mod:C_0805_HandSoldering |  | Digi-key | 490-6479-1-ND
C22 | 0.47uF | mod:C_0603_HandSoldering |  | Digi-key | 490-6416-1-ND
C25 | 0.47uF | mod:C_0603_HandSoldering |  | Digi-key | 490-6416-1-ND
C28 | 0.47uF | mod:C_0603_HandSoldering |  | Digi-key | 490-6416-1-ND
C34 | 47uF | mod:C_0805_HandSoldering |  | Digi-key | 490-6542-1-ND
C46 | 0.47uF | mod:C_0805_HandSoldering |  | Digi-key | 490-6416-1-ND
C36 | 4.7uF | mod:C_0805_HandSoldering |  | Digi-key | 490-6479-1-ND
C38 | 4.7uF | mod:C_0805_HandSoldering |  | Digi-key | 490-6479-1-ND
C40 | 0.47uF | mod:C_0805_HandSoldering |  | Digi-key | 490-6416-1-ND
C42 | 0.47uF | mod:C_0805_HandSoldering |  | Digi-key | 490-6416-1-ND
C44 | 0.47uF | mod:C_0805_HandSoldering |  | Digi-key | 490-6416-1-ND
U2 | SFP+ | mod:A97943DKR-ND
J5 | SFP_CAGE | mod:SFP_CAGE
C2 | 0.1uF | mod:C_0402
C3 | 10uF | mod:C_0402
C1 | 0.1uF | mod:C_0402
L1 | 1uH | mod:C_0402
L2 | 1uH | mod:C_0402
C4 | 0.1uF | mod:C_0402
C5 | 10uF | mod:C_0402
R15 | 4.7k | mod:C_0402
R16 | 4.7k | mod:C_0402
R17 | 4.7k | mod:C_0402
R35 | 4.7k | mod:C_0402
R36 | 4.7k | mod:C_0402
U5 | PINS_14X2 | mod:87832-1420
R4 | 4.7k | mod:C_0201
R6 | 2.4k | mod:C_0201
R5 | 330 | mod:C_0201
R7 | 4.7k | mod:C_0201
U8 | M25P32 | mod:SO8W
C48 | 0.1uF | mod:C_0402
R19 | 10k | mod:C_0402
R20 | 8k | mod:C_0402
C47 | 0.47uF | mod:C_0402
U7 | ST715MR | mod:SOT-223-5 |  | Digikey | 497-6832-1-ND
C49 | 47uF | mod:SM1210 |  | Digi-key | 490-6542-1-ND
R21 | 0 | mod:C_0201
C50 | 330uF |  |  | Digi-key | 399-4105-1-ND
C51 | 4.7uF | mod:C_0805_HandSoldering |  | Digi-key | 490-6479-1-ND
C54 | 0.47uF | mod:C_0603_HandSoldering |  | Digi-key | 490-6416-1-ND
C52 | 4.7uF | mod:C_0805_HandSoldering |  | Digi-key | 490-6479-1-ND
C53 | 4.7uF | mod:C_0805_HandSoldering |  | Digi-key | 490-6479-1-ND
C55 | 0.47uF | mod:C_0603_HandSoldering |  | Digi-key | 490-6416-1-ND
C56 | 0.47uF | mod:C_0603_HandSoldering |  | Digi-key | 490-6416-1-ND
C57 | 0.47uF | mod:C_0603_HandSoldering |  | Digi-key | 490-6416-1-ND
C58 | 0.47uF | mod:C_0603_HandSoldering |  | Digi-key | 490-6416-1-ND
C59 | 100uF | mod:SM1210 |  | Digi-key | 490-3390-1-ND
C60 | 0.47uF | mod:C_0603_HandSoldering |  | Digi-key | 490-6416-1-ND
C61 | 47uF | mod:SM1210 |  | Digi-key | 490-6542-1-ND
C63 | 0.47uF | mod:C_0603_HandSoldering |  | Digi-key | 490-6416-1-ND
C62 | 4.7uF | mod:C_0805_HandSoldering |  | Digi-key | 490-6479-1-ND
C64 | 4.7uF | mod:C_0805_HandSoldering
C65 | 0.1uF | mod:C_0201
C66 | 0.1uF | mod:C_0201
C67 | 4.7uF | mod:C_0805_HandSoldering
C68 | 0.1uF | mod:C_0201
C69 | 0.1uF | mod:C_0201
U9 | TPS72010DRVT | mod:TPS720 |  | Digi-key | 296-25806-1-ND
U14 | TPS72012DRVT | mod:TPS720 |  | Digi-key | 296-25807-1-ND
U10 | BD10KA5WF | mod:SOP8 |  | Digi-key | BD10KA5WF-E2CT-ND
U17 | MCP1825T-3302E | mod:MCP1825 |  | Digi-key | MCP1825T-3302E/DCCT-ND
C76 | 1uF | mod:C_0402
C74 | 1uF | mod:C_0402 |  | Digikey | 445-5138-1-ND
C70 | 0.1uF | mod:C_0402
C77 | 1uF | mod:C_0603_HandSoldering |  | Digikey | 445-4835-1-ND
C75 | 2.2uF | mod:C_0402
C82 | 1uF | mod:C_0402
C84 | 1uF | mod:C_0402
C79 | 1uF | mod:C_0402
C85 | 2.2uF | mod:C_0402
C89 | 68uF | mod:SMD-1206_Pol |  | Digikey | 445-14746-1-ND
C87 | 4.7uF | mod:C_0603_HandSoldering
C83 | 2.2uF | mod:C_0402
R27 | 10k | mod:C_0201
U15 | LM3880 | mod:SOT-23-6 |  | Digi-key | 296-43886-1-ND
R28 | 10k | mod:C_0201
R29 | 10k | mod:C_0201
C88 | 33uF | mod:SMD-1210_Pol |  | Digikey | 478-1692-1-ND
U16 | LP3962 | mod:TO-263-5 |  | Digikey | LP3962ES-2.5/NOPB-ND
C86 | 1uF | mod:C_0603_HandSoldering
R30 | 10k | mod:C_0402
U13 | LD39080 | mod:TO-252-5 |  | Digi-key | 497-6016-1-ND
R24 | 250k | mod:C_0201
R22 | 10K | mod:C_0201
C72 | 10uF | mod:C_0402
C73 | 47uF | mod:C_0805_HandSoldering |  | Digi-key | 587-1779-1-ND
C71 | 330uF | mod:SM1210 |  | Digi-key | 399-4105-1-ND
U11 | LTM4622 | mod:LGA25
R18 | 22k | mod:C_0201
R25 | 12k | mod:C_0201
C7 | 47uF | mod:C_0805_HandSoldering |  | Digi-key | 587-1779-1-ND
C78 | 0.1uF | mod:C_0201
C10 | 0.1uF | mod:C_0201
D1 | LED | mod:LED_402 |  | Digkey | 1497-1174-1-ND
R1 | 20 | mod:C_0402
D2 | LED | mod:LED_402 |  | Digkey | 1497-1174-1-ND
R23 | 20 | mod:C_0402
D3 | LED | mod:LED_402 |  | Digkey | 1497-1174-1-ND
R32 | 20 | mod:C_0402
D4 | LED | mod:LED_402 |  | Digkey | 1497-1174-1-ND
R33 | 20 | mod:C_0402
P3 | CONN_01X06 | mod:WM17449-ND |  | Digikey | WM17449-ND

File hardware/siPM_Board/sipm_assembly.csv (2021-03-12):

Source | /home/hazen/work/ARICH/PCB/hardware/siPM_Board/trunk/SiPM_Board.sch
Kicad Rev | Eeschema 5.1.9-73d0e3b20d~88~ubuntu20.04.1
Generated Date | Mon 01 Mar 2021 10:09:39 AM EST
Title | SiPM Schematic
Company | Electronics Design Facility
Revision | Not Set
Date Issue | 2021-02-24
Comment | Final Draft
Reference | Value | Manufacturer | MFN | Supplier | Supplier P/N | Qty
J1 | Conn_02x34_Odd_Even | Samtec | MW-34-03-G-D-245-065-ES | Samtec | MW-34-03-G-D-245-065-ES | 1
U5 | S14161-6050HS-04 | Hamamatsu | S14161-6050HS-04 | Hamamatsu | S14161-6050HS-04 | 1
J2 | Conn_02x34_Odd_Even | Samtec | MW-34-03-G-D-245-065-ES | Samtec | MW-34-03-G-D-245-065-ES | 1
U2 | S14161-6050HS-04 | Hamamatsu | S14161-6050HS-04 | Hamamatsu | S14161-6050HS-04 | 1
U3 | S14161-6050HS-04 | Hamamatsu | S14161-6050HS-04 | Hamamatsu | S14161-6050HS-04 | 1
C16 | 100nF | Walsin Technology Corporation | 0603B104K101CT | Digi-Key | 1292-1392-1-ND | 1
C14 | 100nF | Walsin Technology Corporation | 0603B104K101CT | Digi-Key | 1292-1392-1-ND | 1
U4 | S14161-6050HS-04 | Hamamatsu | S14161-6050HS-04 | Hamamatsu | S14161-6050HS-04 | 1
C8 | 100nF | Walsin Technology Corporation | 0603B104K101CT | Digi-Key | 1292-1392-1-ND | 1
C6 | 100nF | Walsin Technology Corporation | 0603B104K101CT | Digi-Key | 1292-1392-1-ND | 1
C17 | 100nF | Walsin Technology Corporation | 0603B104K101CT | Digi-Key | 1292-1392-1-ND | 1
C15 | 100nF | Walsin Technology Corporation | 0603B104K101CT | Digi-Key | 1292-1392-1-ND | 1
C9 | 100nF | Walsin Technology Corporation | 0603B104K101CT | Digi-Key | 1292-1392-1-ND | 1
U1 | LM94021 | Texas Instruments | LM94021BIMG/NOPB | Digi-Key | LM94021BIMG/NOPBCT-ND | 1
C3 | 100nF | Walsin Technology Corporation | 0603B104K101CT | Digi-Key | 1292-1392-1-ND | 1
C1 | 100nF | Walsin Technology Corporation | 0603B104K101CT | Digi-Key | 1292-1392-1-ND | 1
C4 | 100nF | Walsin Technology Corporation | 0603B104K101CT | Digi-Key | 1292-1392-1-ND | 1
C2 | 100nF | Walsin Technology Corporation | 0603B104K101CT | Digi-Key | 1292-1392-1-ND | 1
C13 | 100nF | Walsin Technology Corporation | 0603B104K101CT | Digi-Key | 1292-1392-1-ND | 1
C11 | 100nF | Walsin Technology Corporation | 0603B104K101CT | Digi-Key | 1292-1392-1-ND | 1
C12 | 100nF | Walsin Technology Corporation | 0603B104K101CT | Digi-Key | 1292-1392-1-ND | 1
C10 | 100nF | Walsin Technology Corporation | 0603B104K101CT | Digi-Key | 1292-1392-1-ND | 1
C5 | 100nF | Walsin Technology Corporation | 0603B104K101CT | Digi-Key | 1292-1392-1-ND | 1
C7 | 100nF | Walsin Technology Corporation | 0603B104K101CT | Digi-Key | 1292-1392-1-ND | 1

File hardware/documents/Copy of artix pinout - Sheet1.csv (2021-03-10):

#Top: ios Floorplan: io_1 Part: xc7a35tfgg484-1
#Generated by: kremerme on: Mon Mar 8 10:36:28 2021
#Build: Vivado v2020.2 by: xbuild on: Wed Nov 18 09:12:47 MST 2020
#Package Version: FINAL 2013-11-27
#Package Pin Delay Version: VERS. 2.0 2013-11-27 |  |  |  |  | down 100
 |  |  |  | maybe | maybe
IO Bank | LEAD | Pin Name | Pin Number | X, pos | Y, Pos | const | U,D,L,R | const | const | sheet? | const | type
0 | X | VN_0 | M9 | 500 | 0 | 100 | D | 50 | 50 | 2 | 0 | W
0 | X | VP_0 | L10 | 500 | -100 | 100 | D | 50 | 50 | 2 | 0 | W
0 | X | DONE_0 | G11 | 500 | -200 | 100 | L | 50 | 50 | 2 | 0 | O
0 | X | DXP_0 | N10 | 500 | -300 | 100 | L | 50 | 50 | 2 | 0 | I
0 | X | GNDADC_0 | K9 | 500 | -400 | 100 | U | 50 | 50 | 2 | 0 | W
0 | X | VCCADC_0 | K10 | 500 | -500 | 100 | D | 50 | 50 | 2 | 0 | W
0 | X | VREFP_0 | M10 | 500 | -600 | 100 | L | 50 | 50 | 2 | 0 | I
0 | X | VCCBATT_0 | E12 | 500 | -700 | 100 | D | 50 | 50 | 2 | 0 | W
0 | X | TCK_0 | V12 | 500 | -800 | 100 | L | 50 | 50 | 2 | 0 | I
0 | X | DXN_0 | N9 | 500 | -900 | 100 | L | 50 | 50 | 2 | 0 | I
0 | X | VREFN_0 | L9 | 500 | -1000 | 100 | D | 50 | 50 | 2 | 0 | W
0 | X | CCLK_0 | L12 | 500 | -1100 | 100 | L | 50 | 50 | 2 | 0 | I
0 | X | 0 | U11 | 500 | -1200 | 100 | L | 50 | 50 | 2 | 0 | I
0 | X | M1_0 | U10 | 500 | -1300 | 100 | L | 50 | 50 | 2 | 0 | I
0 | X | INIT_B_0 | U12 | 500 | -1400 | 100 | L | 50 | 50 | 2 | 0 | I
0 | X | TDI_0 | R13 | 500 | -1500 | 100 | L | 50 | 50 | 2 | 0 | I
0 | X | TDO_0 | U13 | 500 | -1600 | 100 | L | 50 | 50 | 2 | 0 | I
0 | X | M2_0 | U9 | 500 | -1700 | 100 | L | 50 | 50 | 2 | 0 | I
0 | X | CFGBVS_0 | U8 | 500 | -1800 | 100 | L | 50 | 50 | 2 | 0 | I
0 | X | PROGRAM_B_0 | N12 | 500 | -1900 | 100 | L | 50 | 50 | 2 | 0 | I
0 | X | TMS_0 | T13 | 500 | -2000 | 100 | L | 50 | 50 | 2 | 0 | I
0 | X | VCCO_0 | F12 | 500 | -2100 | 100 | D | 50 | 50 | 2 | 0 | W
0 | X | VCCO_0 | T12 | 500 | -2200 | 100 | D | 50 | 50 | 2 | 0 | W
13 | X | VCCO_13 | AA17 | 500 | 0 | 100 | D | 50 | 50 | 3 | 0 | W
13 | X | VCCO_13 | AB14 | 500 | -100 | 100 | D | 50 | 50 | 3 | 0 | W
13 | X | VCCO_13 | V16 | 500 | -200 | 100 | D | 50 | 50 | 3 | 0 | W
13 | X | VCCO_13 | W13 | 500 | -300 | 100 | D | 50 | 50 | 3 | 0 | W
13 | X | VCCO_13 | Y10 | 500 | -400 | 100 | D | 50 | 50 | 3 | 0 | W
14 | X | IO_0_14 | P20 | 500 | 0 | 100 | L | 50 | 50 | 4 | 0 | I
14 | X | IO_L1P_T0_D00_MOSI_14 | P22 | 500 | -100 | 100 | L | 50 | 50 | 4 | 0 | I
14 | X | IO_L1N_T0_D01_DIN_14 | R22 | 500 | -200 | 100 | L | 50 | 50 | 4 | 0 | I
14 | X | IO_L2P_T0_D02_14 | P21 | 500 | -300 | 100 | L | 50 | 50 | 4 | 0 | I
14 | X | IO_L2N_T0_D03_14 | R21 | 500 | -400 | 100 | L | 50 | 50 | 4 | 0 | I
14 | X | IO_L3P_T0_DQS_PUDC_B_14 | U22 | 500 | -500 | 100 | L | 50 | 50 | 4 | 0 | I
14 | X | IO_L3N_T0_DQS_EMCCLK_14 | V22 | 500 | -600 | 100 | L | 50 | 50 | 4 | 0 | I
14 | X | IO_L4P_T0_D04_14 | T21 | 500 | -700 | 100 | L | 50 | 50 | 4 | 0 | I
14 | X | IO_L4N_T0_D05_14 | U21 | 500 | -800 | 100 | L | 50 | 50 | 4 | 0 | I
14 | X | IO_L5P_T0_D06_14 | P19 | 500 | -900 | 100 | L | 50 | 50 | 4 | 0 | I
14 | X | IO_L5N_T0_D07_14 | R19 | 500 | -1000 | 100 | L | 50 | 50 | 4 | 0 | I
14 | X | IO_L6P_T0_FCS_B_14 | T19 | 500 | -1100 | 100 | L | 50 | 50 | 4 | 0 | I
14 | X | IO_L6N_T0_D08_VREF_14 | T20 | 500 | -1200 | 100 | L | 50 | 50 | 4 | 0 | I
14 | X | IO_L7P_T1_D09_14 | W21 | 500 | -1300 | 100 | L | 50 | 50 | 4 | 0 | I
14 | X | IO_L7N_T1_D10_14 | W22 | 500 | -1400 | 100 | L | 50 | 50 | 4 | 0 | I
14 | X | IO_L8P_T1_D11_14 | AA20 | 500 | -1500 | 100 | L | 50 | 50 | 4 | 0 | I
14 | X | IO_L8N_T1_D12_14 | AA21 | 500 | -1600 | 100 | L | 50 | 50 | 4 | 0 | I
14 | X | IO_L9P_T1_DQS_14 | Y21 | 500 | -1700 | 100 | L | 50 | 50 | 4 | 0 | I
14 | X | IO_L9N_T1_DQS_D13_14 | Y22 | 500 | -1800 | 100 | L | 50 | 50 | 4 | 0 | I
14 | X | IO_L10P_T1_D14_14 | AB21 | 500 | -1900 | 100 | L | 50 | 50 | 4 | 0 | I
14 | X | IO_L10N_T1_D15_14 | AB22 | 500 | -2000 | 100 | L | 50 | 50 | 4 | 0 | I
14 | X | IO_L11P_T1_SRCC_14 | U20 | 500 | -2100 | 100 | L | 50 | 50 | 4 | 0 | I
14 | X | IO_L11N_T1_SRCC_14 | V20 | 500 | -2200 | 100 | L | 50 | 50 | 4 | 0 | I
14 | X | IO_L12P_T1_MRCC_14 | W19 | 500 | -2300 | 100 | L | 50 | 50 | 4 | 0 | I
14 | X | IO_L12N_T1_MRCC_14 | W20 | 500 | -2400 | 100 | L | 50 | 50 | 4 | 0 | I
14 | X | IO_L13P_T2_MRCC_14 | Y18 | 500 | -2500 | 100 | L | 50 | 50 | 4 | 0 | I
14 | X | IO_L13N_T2_MRCC_14 | Y19 | 500 | -2600 | 100 | L | 50 | 50 | 4 | 0 | I
14 | X | IO_L14P_T2_SRCC_14 | V18 | 500 | -2700 | 100 | L | 50 | 50 | 4 | 0 | I
14 | X | IO_L14N_T2_SRCC_14 | V19 | 500 | -2800 | 100 | L | 50 | 50 | 4 | 0 | I
14 | X | IO_L15P_T2_DQS_RDWR_B_14 | AA19 | 500 | -2900 | 100 | L | 50 | 50 | 4 | 0 | I
14 | X | IO_L15N_T2_DQS_DOUT_CSO_B_14 | AB20 | 500 | -3000 | 100 | L | 50 | 50 | 4 | 0 | I
14 | X | IO_L16P_T2_CSI_B_14 | V17 | 500 | -3100 | 100 | L | 50 | 50 | 4 | 0 | I
14 | X | IO_L16N_T2_A15_D31_14 | W17 | 500 | -3200 | 100 | L | 50 | 50 | 4 | 0 | I
14 | X | IO_L17P_T2_A14_D30_14 | AA18 | 500 | -3300 | 100 | L | 50 | 50 | 4 | 0 | I
14 | X | IO_L17N_T2_A13_D29_14 | AB18 | 500 | -3400 | 100 | L | 50 | 50 | 4 | 0 | I
14 | X | IO_L18P_T2_A12_D28_14 | U17 | 500 | -3500 | 100 | L | 50 | 50 | 4 | 0 | I
14 | X | IO_L18N_T2_A11_D27_14 | U18 | 500 | -3600 | 100 | L | 50 | 50 | 4 | 0 | I
14 | X | IO_L19P_T3_A10_D26_14 | P14 | 500 | -3700 | 100 | L | 50 | 50 | 4 | 0 | I
14 | X | IO_L19N_T3_A09_D25_VREF_14 | R14 | 500 | -3800 | 100 | L | 50 | 50 | 4 | 0 | I
14 | X | IO_L20P_T3_A08_D24_14 | R18 | 500 | -3900 | 100 | L | 50 | 50 | 4 | 0 | I
14 | X | IO_L20N_T3_A07_D23_14 | T18 | 500 | -4000 | 100 | L | 50 | 50 | 4 | 0 | I
14 | X | IO_L21P_T3_DQS_14 | N17 | 500 | -4100 | 100 | L | 50 | 50 | 4 | 0 | I
14 | X | IO_L21N_T3_DQS_A06_D22_14 | P17 | 500 | -4200 | 100 | L | 50 | 50 | 4 | 0 | I
14 | X | IO_L22P_T3_A05_D21_14 | P15 | 500 | -4300 | 100 | L | 50 | 50 | 4 | 0 | I
14 | X | IO_L22N_T3_A04_D20_14 | R16 | 500 | -4400 | 100 | L | 50 | 50 | 4 | 0 | I
14 | X | IO_L23P_T3_A03_D19_14 | N13 | 500 | -4500 | 100 | L | 50 | 50 | 4 | 0 | I
14 | X | IO_L23N_T3_A02_D18_14 | N14 | 500 | -4600 | 100 | L | 50 | 50 | 4 | 0 | I
14 | X | IO_L24P_T3_A01_D17_14 | P16 | 500 | -4700 | 100 | L | 50 | 50 | 4 | 0 | I
14 | X | IO_L24N_T3_A00_D16_14 | R17 | 500 | -4800 | 100 | L | 50 | 50 | 4 | 0 | I
14 | X | IO_25_14 | N15 | 500 | -4900 | 100 | L | 50 | 50 | 4 | 0 | I
14 | X | VCCO_14 | M14 | 500 | -5000 | 100 | D | 50 | 50 | 4 | 0 | W
14 | X | VCCO_14 | P18 | 500 | -5100 | 100 | D | 50 | 50 | 4 | 0 | W
14 | X | VCCO_14 | R15 | 500 | -5200 | 100 | D | 50 | 50 | 4 | 0 | W
14 | X | VCCO_14 | T22 | 500 | -5300 | 100 | D | 50 | 50 | 4 | 0 | W
14 | X | VCCO_14 | U19 | 500 | -5400 | 100 | D | 50 | 50 | 4 | 0 | W
14 | X | VCCO_14 | Y20 | 500 | -5500 | 100 | D | 50 | 50 | 4 | 0 | W
15 | X | IO_0_15 | J16 | 500 | 0 | 100 | L | 50 | 50 | 5 | 0 | I
15 | X | IO_L1P_T0_AD0P_15 | H13 | 500 | -100 | 100 | L | 50 | 50 | 5 | 0 | I
15 | X | IO_L1N_T0_AD0N_15 | G13 | 500 | -200 | 100 | L | 50 | 50 | 5 | 0 | I
15 | X | IO_L2P_T0_AD8P_15 | G15 | 500 | -300 | 100 | L | 50 | 50 | 5 | 0 | I
15 | X | IO_L2N_T0_AD8N_15 | G16 | 500 | -400 | 100 | L | 50 | 50 | 5 | 0 | I
15 | X | IO_L3P_T0_DQS_AD1P_15 | J14 | 500 | -500 | 100 | L | 50 | 50 | 5 | 0 | I
15 | X | IO_L3N_T0_DQS_AD1N_15 | H14 | 500 | -600 | 100 | L | 50 | 50 | 5 | 0 | I
15 | X | IO_L4P_T0_15 | G17 | 500 | -700 | 100 | L | 50 | 50 | 5 | 0 | I
15 | X | IO_L4N_T0_15 | G18 | 500 | -800 | 100 | L | 50 | 50 | 5 | 0 | I
15 | X | IO_L5P_T0_AD9P_15 | J15 | 500 | -900 | 100 | L | 50 | 50 | 5 | 0 | I
15 | X | IO_L5N_T0_AD9N_15 | H15 | 500 | -1000 | 100 | L | 50 | 50 | 5 | 0 | I
15 | X | IO_L6P_T0_15 | H17 | 500 | -1100 | 100 | L | 50 | 50 | 5 | 0 | I
15 | X | IO_L6N_T0_VREF_15 | H18 | 500 | -1200 | 100 | L | 50 | 50 | 5 | 0 | I
15 | X | IO_L7P_T1_AD2P_15 | J22 | 500 | -1300 | 100 | L | 50 | 50 | 5 | 0 | I
15 | X | IO_L7N_T1_AD2N_15 | H22 | 500 | -1400 | 100 | L | 50 | 50 | 5 | 0 | I
15 | X | IO_L8P_T1_AD10P_15 | H20 | 500 | -1500 | 100 | L | 50 | 50 | 5 | 0 | I
15 | X | IO_L8N_T1_AD10N_15 | G20 | 500 | -1600 | 100 | L | 50 | 50 | 5 | 0 | I
15 | X | IO_L9P_T1_DQS_AD3P_15 | K21 | 500 | -1700 | 100 | L | 50 | 50 | 5 | 0 | I
15 | X | IO_L9N_T1_DQS_AD3N_15 | K22 | 500 | -1800 | 100 | L | 50 | 50 | 5 | 0 | I
15 | X | IO_L10P_T1_AD11P_15 | M21 | 500 | -1900 | 100 | L | 50 | 50 | 5 | 0 | I
15 | X | IO_L10N_T1_AD11N_15 | L21 | 500 | -2000 | 100 | L | 50 | 50 | 5 | 0 | I
15 | X | IO_L11P_T1_SRCC_15 | J20 | 500 | -2100 | 100 | L | 50 | 50 | 5 | 0 | I
15 | X | IO_L11N_T1_SRCC_15 | J21 | 500 | -2200 | 100 | L | 50 | 50 | 5 | 0 | I
15 | X | IO_L12P_T1_MRCC_15 | J19 | 500 | -2300 | 100 | L | 50 | 50 | 5 | 0 | I
15 | X | IO_L12N_T1_MRCC_15 | H19 | 500 | -2400 | 100 | L | 50 | 50 | 5 | 0 | I
15 | X | IO_L13P_T2_MRCC_15 | K18 | 500 | -2500 | 100 | L | 50 | 50 | 5 | 0 | I
15 | X | IO_L13N_T2_MRCC_15 | K19 | 500 | -2600 | 100 | L | 50 | 50 | 5 | 0 | I
15 | X | IO_L14P_T2_SRCC_15 | L19 | 500 | -2700 | 100 | L | 50 | 50 | 5 | 0 | I
15 | X | IO_L14N_T2_SRCC_15 | L20 | 500 | -2800 | 100 | L | 50 | 50 | 5 | 0 | I
15 | X | IO_L15P_T2_DQS_15 | N22 | 500 | -2900 | 100 | L | 50 | 50 | 5 | 0 | I
15 | X | IO_L15N_T2_DQS_ADV_B_15 | M22 | 500 | -3000 | 100 | L | 50 | 50 | 5 | 0 | I
15 | X | IO_L16P_T2_A28_15 | M18 | 500 | -3100 | 100 | L | 50 | 50 | 5 | 0 | I
15 | X | IO_L16N_T2_A27_15 | L18 | 500 | -3200 | 100 | L | 50 | 50 | 5 | 0 | I
15 | X | IO_L17P_T2_A26_15 | N18 | 500 | -3300 | 100 | L | 50 | 50 | 5 | 0 | I
15 | X | IO_L17N_T2_A25_15 | N19 | 500 | -3400 | 100 | L | 50 | 50 | 5 | 0 | I
15 | X | IO_L18P_T2_A24_15 | N20 | 500 | -3500 | 100 | L | 50 | 50 | 5 | 0 | I
15 | X | IO_L18N_T2_A23_15 | M20 | 500 | -3600 | 100 | L | 50 | 50 | 5 | 0 | I
15 | X | IO_L19P_T3_A22_15 | K13 | 500 | -3700 | 100 | L | 50 | 50 | 5 | 0 | I
15 | X | IO_L19N_T3_A21_VREF_15 | K14 | 500 | -3800 | 100 | L | 50 | 50 | 5 | 0 | I
15 | X | IO_L20P_T3_A20_15 | M13 | 500 | -3900 | 100 | L | 50 | 50 | 5 | 0 | I
15 | X | IO_L20N_T3_A19_15 | L13 | 500 | -4000 | 100 | L | 50 | 50 | 5 | 0 | I
15 | X | IO_L21P_T3_DQS_15 | K17 | 500 | -4100 | 100 | L | 50 | 50 | 5 | 0 | I
15 | X | IO_L21N_T3_DQS_A18_15 | J17 | 500 | -4200 | 100 | L | 50 | 50 | 5 | 0 | I
15 | X | IO_L22P_T3_A17_15 | L14 | 500 | -4300 | 100 | L | 50 | 50 | 5 | 0 | I
15 | X | IO_L22N_T3_A16_15 | L15 | 500 | -4400 | 100 | L | 50 | 50 | 5 | 0 | I
15 | X | IO_L23P_T3_FOE_B_15 | L16 | 500 | -4500 | 100 | L | 50 | 50 | 5 | 0 | I
15 | X | IO_L23N_T3_FWE_B_15 | K16 | 500 | -4600 | 100 | L | 50 | 50 | 5 | 0 | I
15 | X | IO_L24P_T3_RS1_15 | M15 | 500 | -4700 | 100 | L | 50 | 50 | 5 | 0 | I
15 | X | IO_L24N_T3_RS0_15 | M16 | 500 | -4800 | 100 | L | 50 | 50 | 5 | 0 | I
15 | X | IO_25_15 | M17 | 500 | -4900 | 100 | L | 50 | 50 | 5 | 0 | I
15 | X | VCCO_15 | G19 | 500 | -5000 | 100 | D | 50 | 50 | 5 | 0 | W
15 | X | VCCO_15 | H16 | 500 | -5100 | 100 | D | 50 | 50 | 5 | 0 | W
15 | X | VCCO_15 | J13 | 500 | -5200 | 100 | D | 50 | 50 | 5 | 0 | W
15 | X | VCCO_15 | K20 | 500 | -5300 | 100 | D | 50 | 50 | 5 | 0 | W
15 | X | VCCO_15 | L17 | 500 | -5400 | 100 | D | 50 | 50 | 5 | 0 | W
15 | X | VCCO_15 | N21 | 500 | -5500 | 100 | D | 50 | 50 | 5 | 0 | W
16 | X | IO_0_16 | F15 | 500 | 0 | 100 | L | 50 | 50 | 6 | 0 | I
16 | X | IO_L1P_T0_16 | F13 | 500 | -100 | 100 | L | 50 | 50 | 6 | 0 | I
16 | X | IO_L1N_T0_16 | F14 | 500 | -200 | 100 | L | 50 | 50 | 6 | 0 | I
16 | X | IO_L2P_T0_16 | F16 | 500 | -300 | 100 | L | 50 | 50 | 6 | 0 | I
16 | X | IO_L2N_T0_16 | E17 | 500 | -400 | 100 | L | 50 | 50 | 6 | 0 | I
16 | X | IO_L3P_T0_DQS_16 | C14 | 500 | -500 | 100 | L | 50 | 50 | 6 | 0 | I
16 | X | IO_L3N_T0_DQS_16 | C15 | 500 | -600 | 100 | L | 50 | 50 | 6 | 0 | I
16 | X | IO_L4P_T0_16 | E13 | 500 | -700 | 100 | L | 50 | 50 | 6 | 0 | I
16 | X | IO_L4N_T0_16 | E14 | 500 | -800 | 100 | L | 50 | 50 | 6 | 0 | I
16 | X | IO_L5P_T0_16 | E16 | 500 | -900 | 100 | L | 50 | 50 | 6 | 0 | I
16 | X | IO_L5N_T0_16 | D16 | 500 | -1000 | 100 | L | 50 | 50 | 6 | 0 | I
16 | X | IO_L6P_T0_16 | D14 | 500 | -1100 | 100 | L | 50 | 50 | 6 | 0 | I
16 | X | IO_L6N_T0_VREF_16 | D15 | 500 | -1200 | 100 | L | 50 | 50 | 6 | 0 | I
16 | X | IO_L7P_T1_16 | B15 | 500 | -1300 | 100 | L | 50 | 50 | 6 | 0 | I
16 | X | IO_L7N_T1_16 | B16 | 500 | -1400 | 100 | L | 50 | 50 | 6 | 0 | I
16 | X | IO_L8P_T1_16 | C13 | 500 | -1500 | 100 | L | 50 | 50 | 6 | 0 | I
16 | X | IO_L8N_T1_16 | B13 | 500 | -1600 | 100 | L | 50 | 50 | 6 | 0 | I
16 | X | IO_L9P_T1_DQS_16 | A15 | 500 | -1700 | 100 | L | 50 | 50 | 6 | 0 | I
16 | X | IO_L9N_T1_DQS_16 | A16 | 500 | -1800 | 100 | L | 50 | 50 | 6 | 0 | I
16 | X | IO_L10P_T1_16 | A13 | 500 | -1900 | 100 | L | 50 | 50 | 6 | 0 | I
16 | X | IO_L10N_T1_16 | A14 | 500 | -2000 | 100 | L | 50 | 50 | 6 | 0 | I
16 | X | IO_L11P_T1_SRCC_16 | B17 | 500 | -2100 | 100 | L | 50 | 50 | 6 | 0 | I
16 | X | IO_L11N_T1_SRCC_16 | B18 | 500 | -2200 | 100 | L | 50 | 50 | 6 | 0 | I
16 | X | IO_L12P_T1_MRCC_16 | D17 | 500 | -2300 | 100 | L | 50 | 50 | 6 | 0 | I
16 | X | IO_L12N_T1_MRCC_16 | C17 | 500 | -2400 | 100 | L | 50 | 50 | 6 | 0 | I
16 | X | IO_L13P_T2_MRCC_16 | C18 | 500 | -2500 | 100 | L | 50 | 50 | 6 | 0 | I
16 | X | IO_L13N_T2_MRCC_16 | C19 | 500 | -2600 | 100 | L | 50 | 50 | 6 | 0 | I
16 | X | IO_L14P_T2_SRCC_16 | E19 | 500 | -2700 | 100 | L | 50 | 50 | 6 | 0 | I
16 | X | IO_L14N_T2_SRCC_16 | D19 | 500 | -2800 | 100 | L | 50 | 50 | 6 | 0 | I
16 | X | IO_L15P_T2_DQS_16 | F18 | 500 | -2900 | 100 | L | 50 | 50 | 6 | 0 | I
16 | X | IO_L15N_T2_DQS_16 | E18 | 500 | -3000 | 100 | L | 50 | 50 | 6 | 0 | I
16 | X | IO_L16P_T2_16 | B20 | 500 | -3100 | 100 | L | 50 | 50 | 6 | 0 | I
16 | X | IO_L16N_T2_16 | A20 | 500 | -3200 | 100 | L | 50 | 50 | 6 | 0 | I
16 | X | IO_L17P_T2_16 | A18 | 500 | -3300 | 100 | L | 50 | 50 | 6 | 0 | I
16 | X | IO_L17N_T2_16 | A19 | 500 | -3400 | 100 | L | 50 | 50 | 6 | 0 | I
16 | X | IO_L18P_T2_16 | F19 | 500 | -3500 | 100 | L | 50 | 50 | 6 | 0 | I
16 | X | IO_L18N_T2_16 | F20 | 500 | -3600 | 100 | L | 50 | 50 | 6 | 0 | I
16 | X | IO_L19P_T3_16 | D20 | 500 | -3700 | 100 | L | 50 | 50 | 6 | 0 | I
16 | X | IO_L19N_T3_VREF_16 | C20 | 500 | -3800 | 100 | L | 50 | 50 | 6 | 0 | I
16 | X | IO_L20P_T3_16 | C22 | 500 | -3900 | 100 | L | 50 | 50 | 6 | 0 | I
16 | X | IO_L20N_T3_16 | B22 | 500 | -4000 | 100 | L | 50 | 50 | 6 | 0 | I
16 | X | IO_L21P_T3_DQS_16 | B21 | 500 | -4100 | 100 | L | 50 | 50 | 6 | 0 | I
16 | X | IO_L21N_T3_DQS_16 | A21 | 500 | -4200 | 100 | L | 50 | 50 | 6 | 0 | I
16 | X | IO_L22P_T3_16 | E22 | 500 | -4300 | 100 | L | 50 | 50 | 6 | 0 | I
16 | X | IO_L22N_T3_16 | D22 | 500 | -4400 | 100 | L | 50 | 50 | 6 | 0 | I
16 | X | IO_L23P_T3_16 | E21 | 500 | -4500 | 100 | L | 50 | 50 | 6 | 0 | I
16 | X | IO_L23N_T3_16 | D21 | 500 | -4600 | 100 | L | 50 | 50 | 6 | 0 | I
16 | X | IO_L24P_T3_16 | G21 | 500 | -4700 | 100 | L | 50 | 50 | 6 | 0 | I
16 | X | IO_L24N_T3_16 | G22 | 500 | -4800 | 100 | L | 50 | 50 | 6 | 0 | I
16 | X | IO_25_16 | F21 | 500 | -4900 | 100 | L | 50 | 50 | 6 | 0 | I
16 | X | VCCO_16 | A17 | 500 | -5000 | 100 | D | 50 | 50 | 6 | 0 | W
16 | X | VCCO_16 | B14 | 500 | -5100 | 100 | D | 50 | 50 | 6 | 0 | W
16 | X | VCCO_16 | C21 | 500 | -5200 | 100 | D | 50 | 50 | 6 | 0 | W
16 | X | VCCO_16 | D18 | 500 | -5300 | 100 | D | 50 | 50 | 6 | 0 | W
16 | X | VCCO_16 | E15 | 500 | -5400 | 100 | D | 50 | 50 | 6 | 0 | W
16 | X | VCCO_16 | F22 | 500 | -5500 | 100 | D | 50 | 50 | 6 | 0 | W
34 | X | IO_0_34 | T3 | 500 | 0 | 100 | L | 50 | 50 | 7 | 0 | I
34 | X | IO_L1P_T0_34 | T1 | 500 | -100 | 100 | L | 50 | 50 | 7 | 0 | I
34 | X | IO_L1N_T0_34 | U1 | 500 | -200 | 100 | L | 50 | 50 | 7 | 0 | I
34 | X | IO_L2P_T0_34 | U2 | 500 | -300 | 100 | L | 50 | 50 | 7 | 0 | I
34 | X | IO_L2N_T0_34 | V2 | 500 | -400 | 100 | L | 50 | 50 | 7 | 0 | I
34 | X | IO_L3P_T0_DQS_34 | R3 | 500 | -500 | 100 | L | 50 | 50 | 7 | 0 | I
34 | X | IO_L3N_T0_DQS_34 | R2 | 500 | -600 | 100 | L | 50 | 50 | 7 | 0 | I
34 | X | IO_L4P_T0_34 | W2 | 500 | -700 | 100 | L | 50 | 50 | 7 | 0 | I
34 | X | IO_L4N_T0_34 | Y2 | 500 | -800 | 100 | L | 50 | 50 | 7 | 0 | I
34 | X | IO_L5P_T0_34 | W1 | 500 | -900 | 100 | L | 50 | 50 | 7 | 0 | I
34 | X | IO_L5N_T0_34 | Y1 | 500 | -1000 | 100 | L | 50 | 50 | 7 | 0 | I
34 | X | IO_L6P_T0_34 | U3 | 500 | -1100 | 100 | L | 50 | 50 | 7 | 0 | I
34 | X | IO_L6N_T0_VREF_34 | V3 | 500 | -1200 | 100 | L | 50 | 50 | 7 | 0 | I
34 | X | IO_L7P_T1_34 | AA1 | 500 | -1300 | 100 | L | 50 | 50 | 7 | 0 | I
34 | X | IO_L7N_T1_34 | AB1 | 500 | -1400 | 100 | L | 50 | 50 | 7 | 0 | I
34 | X | IO_L8P_T1_34 | AB3 | 500 | -1500 | 100 | L | 50 | 50 | 7 | 0 | I
34 | X | IO_L8N_T1_34 | AB2 | 500 | -1600 | 100 | L | 50 | 50 | 7 | 0 | I
34 | X | IO_L9P_T1_DQS_34 | Y3 | 500 | -1700 | 100 | L | 50 | 50 | 7 | 0 | I
34 | X | IO_L9N_T1_DQS_34 | AA3 | 500 | -1800 | 100 | L | 50 | 50 | 7 | 0 | I
34 | X | IO_L10P_T1_34 | AA5 | 500 | -1900 | 100 | L | 50 | 50 | 7 | 0 | I
34 | X | IO_L10N_T1_34 | AB5 | 500 | -2000 | 100 | L | 50 | 50 | 7 | 0 | I
34 | X | IO_L11P_T1_SRCC_34 | Y4 | 500 | -2100 | 100 | L | 50 | 50 | 7 | 0 | I
34 | X | IO_L11N_T1_SRCC_34 | AA4 | 500 | -2200 | 100 | L | 50 | 50 | 7 | 0 | I
34 | X | IO_L12P_T1_MRCC_34 | V4 | 500 | -2300 | 100 | L | 50 | 50 | 7 | 0 | I
34 | X | IO_L12N_T1_MRCC_34 | W4 | 500 | -2400 | 100 | L | 50 | 50 | 7 | 0 | I
34 | X | IO_L13P_T2_MRCC_34 | R4 | 500 | -2500 | 100 | L | 50 | 50 | 7 | 0 | I
34 | X | IO_L13N_T2_MRCC_34 | T4 | 500 | -2600 | 100 | L | 50 | 50 | 7 | 0 | I
34 | X | IO_L14P_T2_SRCC_34 | T5 | 500 | -2700 | 100 | L | 50 | 50 | 7 | 0 | I
34 | X | IO_L14N_T2_SRCC_34 | U5 | 500 | -2800 | 100 | L | 50 | 50 | 7 | 0 | I
34 | X | IO_L15P_T2_DQS_34 | W6 | 500 | -2900 | 100 | L | 50 | 50 | 7 | 0 | I
34 | X | IO_L15N_T2_DQS_34 | W5 | 500 | -3000 | 100 | L | 50 | 50 | 7 | 0 | I
34 | X | IO_L16P_T2_34 | U6 | 500 | -3100 | 100 | L | 50 | 50 | 7 | 0 | I
34 | X | IO_L16N_T2_34 | V5 | 500 | -3200 | 100 | L | 50 | 50 | 7 | 0 | I
34 | X | IO_L17P_T2_34 | R6 | 500 | -3300 | 100 | L | 50 | 50 | 7 | 0 | I
34 | X | IO_L17N_T2_34 | T6 | 500 | -3400 | 100 | L | 50 | 50 | 7 | 0 | I
34 | X | IO_L18P_T2_34 | Y6 | 500 | -3500 | 100 | L | 50 | 50 | 7 | 0 | I
34 | X | IO_L18N_T2_34 | AA6 | 500 | -3600 | 100 | L | 50 | 50 | 7 | 0 | I
34 | X | IO_L19P_T3_34 | V7 | 500 | -3700 | 100 | L | 50 | 50 | 7 | 0 | I
34 | X | IO_L19N_T3_VREF_34 | W7 | 500 | -3800 | 100 | L | 50 | 50 | 7 | 0 | I
34 | X | IO_L20P_T3_34 | AB7 | 500 | -3900 | 100 | L | 50 | 50 | 7 | 0 | I
34 | X | IO_L20N_T3_34 | AB6 | 500 | -4000 | 100 | L | 50 | 50 | 7 | 0 | I
34 | X | IO_L21P_T3_DQS_34 | V9 | 500 | -4100 | 100 | L | 50 | 50 | 7 | 0 | I
34 | X | IO_L21N_T3_DQS_34 | V8 | 500 | -4200 | 100 | L | 50 | 50 | 7 | 0 | I
34 | X | IO_L22P_T3_34 | AA8 | 500 | -4300 | 100 | L | 50 | 50 | 7 | 0 | I
34 | X | IO_L22N_T3_34 | AB8 | 500 | -4400 | 100 | L | 50 | 50 | 7 | 0 | I
34 | X | IO_L23P_T3_34 | Y8 | 500 | -4500 | 100 | L | 50 | 50 | 7 | 0 | I
34 | X | IO_L23N_T3_34 | Y7 | 500 | -4600 | 100 | L | 50 | 50 | 7 | 0 | I
34 | X | IO_L24P_T3_34 | W9 | 500 | -4700 | 100 | L | 50 | 50 | 7 | 0 | I
34 | X | IO_L24N_T3_34 | Y9 | 500 | -4800 | 100 | L | 50 | 50 | 7 | 0 | I
34 | X | IO_25_34 | U7 | 500 | -4900 | 100 | L | 50 | 50 | 7 | 0 | I
34 | X | VCCO_34 | AA7 | 500 | -5000 | 100 | D | 50 | 50 | 7 | 0 | W
34 | X | VCCO_34 | AB4 | 500 | -5100 | 100 | D | 50 | 50 | 7 | 0 | W
34 | X | VCCO_34 | R5 | 500 | -5200 | 100 | D | 50 | 50 | 7 | 0 | W
34 | X | VCCO_34 | T2 | 500 | -5300 | 100 | D | 50 | 50 | 7 | 0 | W
34 | X | VCCO_34 | V6 | 500 | -5400 | 100 | D | 50 | 50 | 7 | 0 | W
34 | X | VCCO_34 | W3 | 500 | -5500 | 100 | D | 50 | 50 | 7 | 0 | W
35 | X | IO_0_35 | F4 | 500 | 0 | 100 | L | 50 | 50 | 8 | 0 | I
35 | X | IO_L1P_T0_AD4P_35 | B1 | 500 | -100 | 100 | L | 50 | 50 | 8 | 0 | I
35 | X | IO_L1N_T0_AD4N_35 | A1 | 500 | -200 | 100 | L | 50 | 50 | 8 | 0 | I
35 | X | IO_L2P_T0_AD12P_35 | C2 | 500 | -300 | 100 | L | 50 | 50 | 8 | 0 | I
35 | X | IO_L2N_T0_AD12N_35 | B2 | 500 | -400 | 100 | L | 50 | 50 | 8 | 0 | I
35 | X | IO_L3P_T0_DQS_AD5P_35 | E1 | 500 | -500 | 100 | L | 50 | 50 | 8 | 0 | I
35 | X | IO_L3N_T0_DQS_AD5N_35 | D1 | 500 | -600 | 100 | L | 50 | 50 | 8 | 0 | I
35 | X | IO_L4P_T0_35 | E2 | 500 | -700 | 100 | L | 50 | 50 | 8 | 0 | I
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

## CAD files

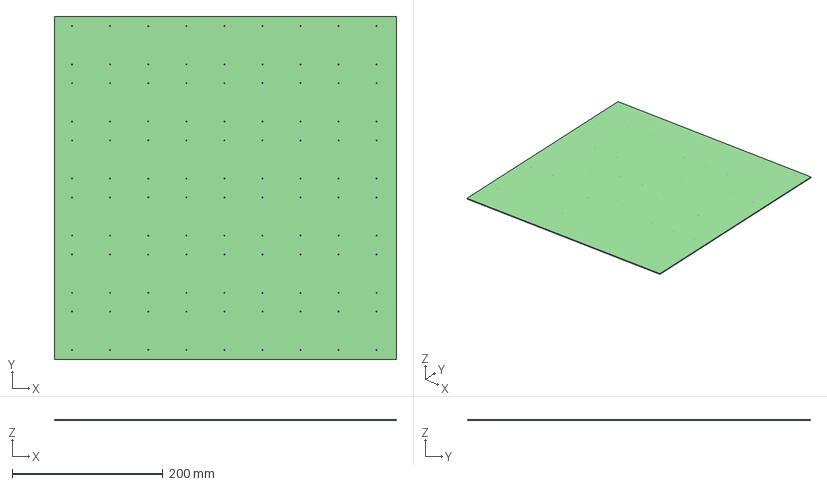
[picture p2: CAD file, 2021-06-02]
hardware/backplane/9x9backplane.step
454.0 x 455.0 x 1.60 mm

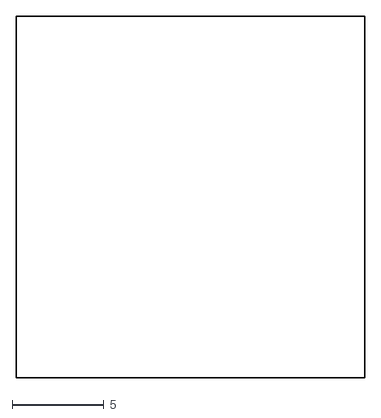
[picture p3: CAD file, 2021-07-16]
hardware/backplane/DXF/9x9backplane-Edge_Cuts.dxf
19.0 x 19.7

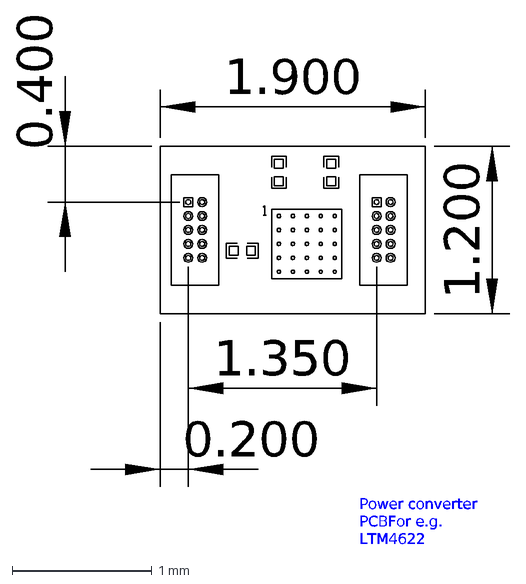
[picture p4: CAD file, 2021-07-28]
hardware/PowerConverter/Example_4622.dxf
1.900
1.200
1.350
0.400
0.200
Power converter PCB For e.g. LTM4622

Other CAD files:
hardware/backplane/DXF/9x9backplane-F_Mask.dxf

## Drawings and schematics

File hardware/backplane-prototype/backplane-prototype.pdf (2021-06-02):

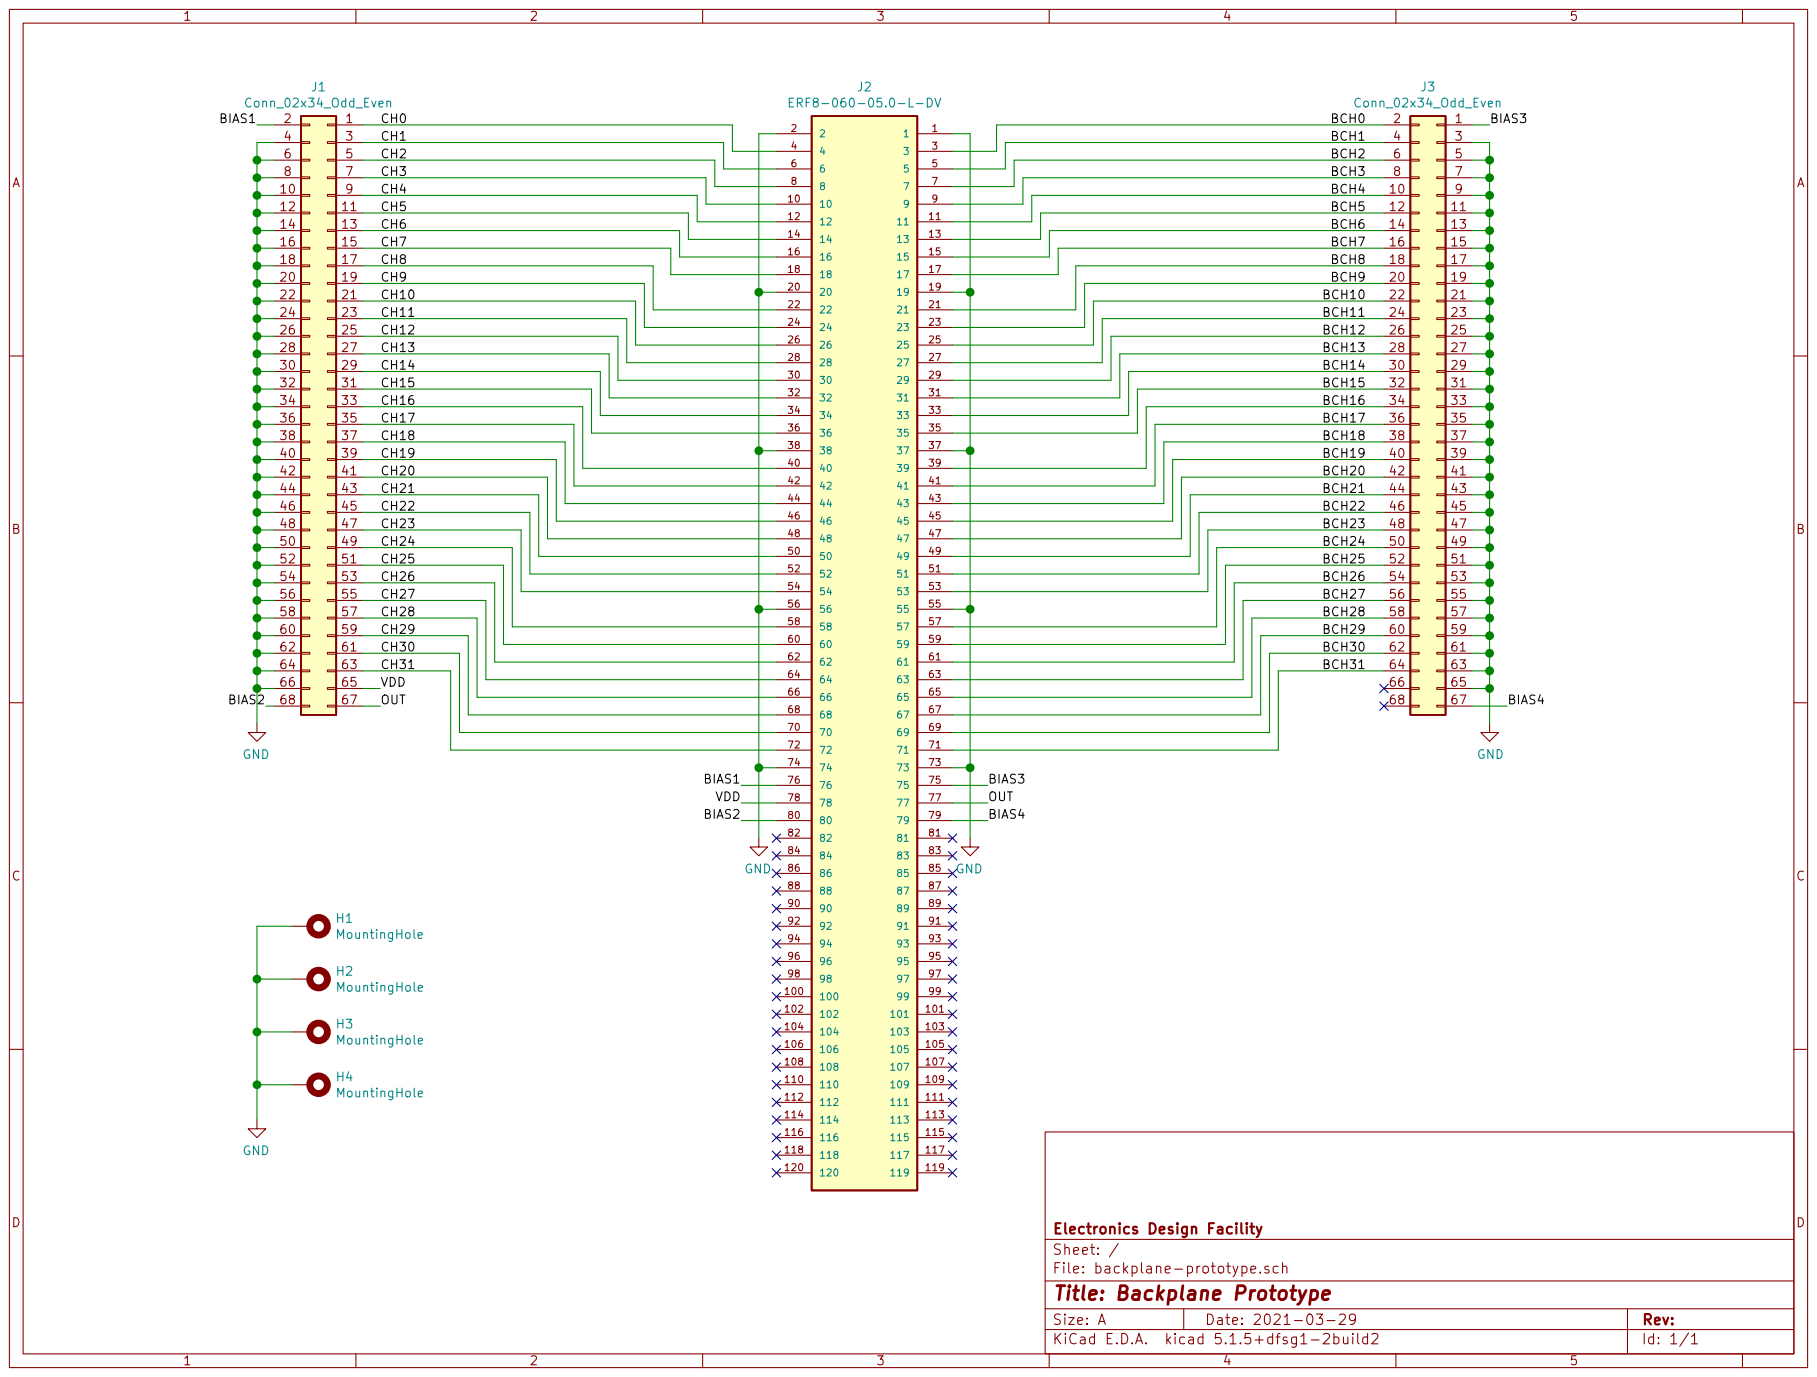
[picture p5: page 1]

30 | | 30
32 | 31 | 32 | 31

50 | | 50
52 | 51 | 52 | 51

Id: 1/1 Title: Backplane Prototype

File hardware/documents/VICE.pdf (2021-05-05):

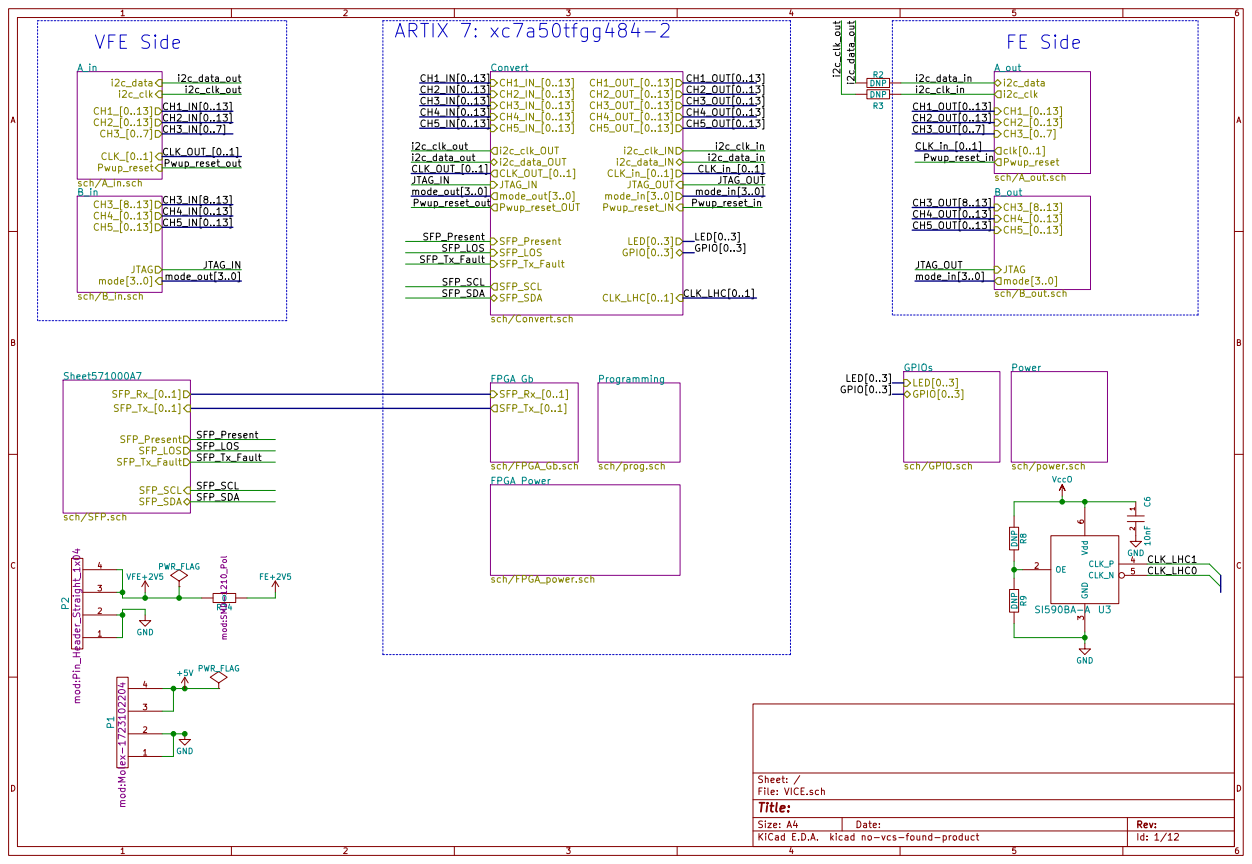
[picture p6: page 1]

1 2 C6 10nF GND GND R8 DNP R9 DNP Power sch/power.sch

SFP_Present
SFP_LOS
SFP_Tx_Fault

Id: 1/12 Title: File: VICE.sch Sheet: /

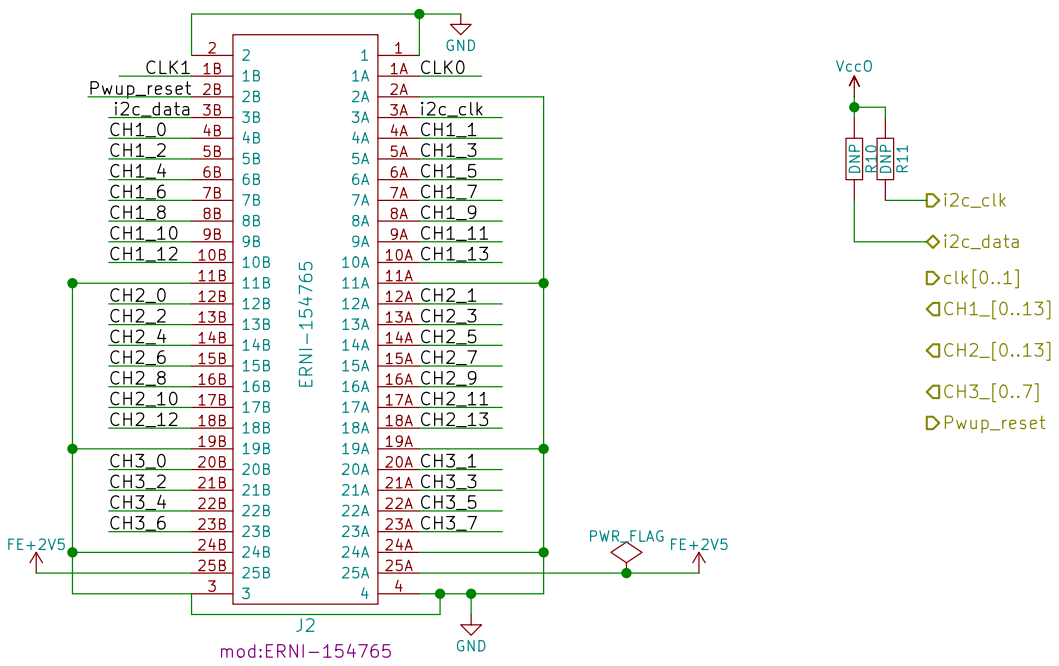
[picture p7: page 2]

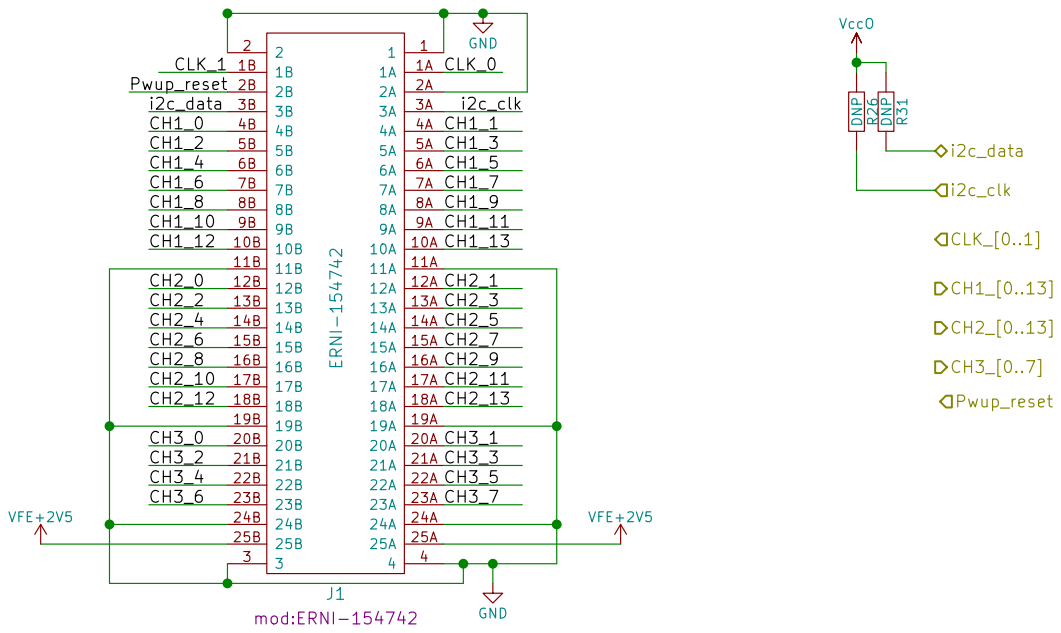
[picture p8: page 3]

4B 4B | CH1_1
5B 5B | CH1_3
6B 6B | CH1_5
7B 7B | CH1_7

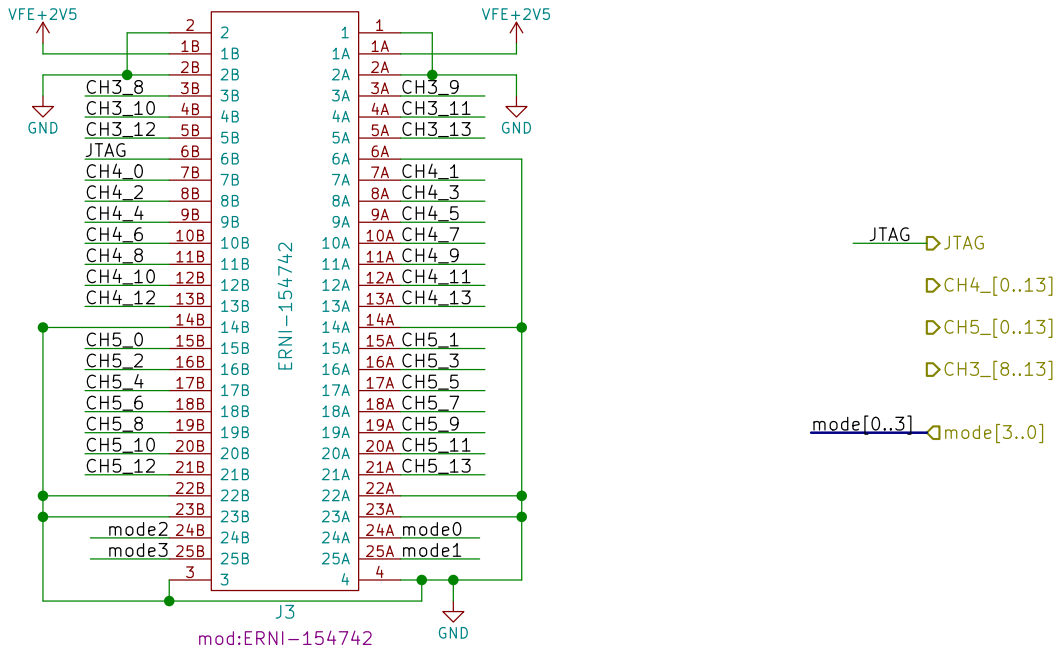
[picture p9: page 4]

7B 7B | CH4_1
8B 8B | CH4_3
9B 9B | CH4_5
10B | CH4_7
11B | CH4_9
12B | CH4_11
13B | CH4_13

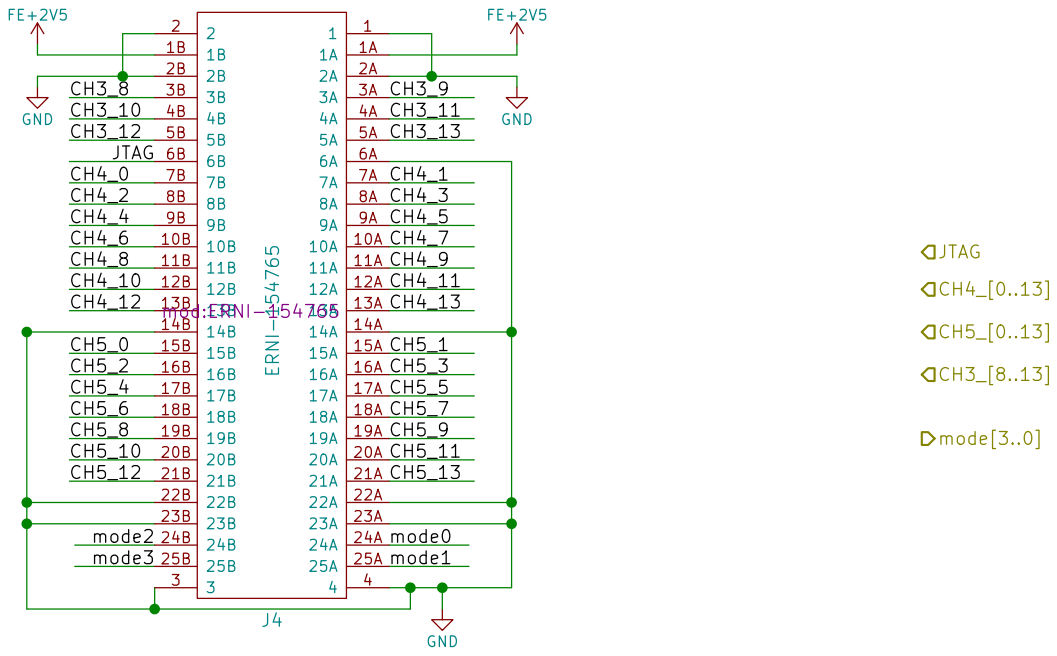
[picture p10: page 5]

7B 7B | CH4_1
8B 8B | CH4_3
9B 9B | CH4_5
10B | CH4_7
11B | CH4_9
12B | CH4_11

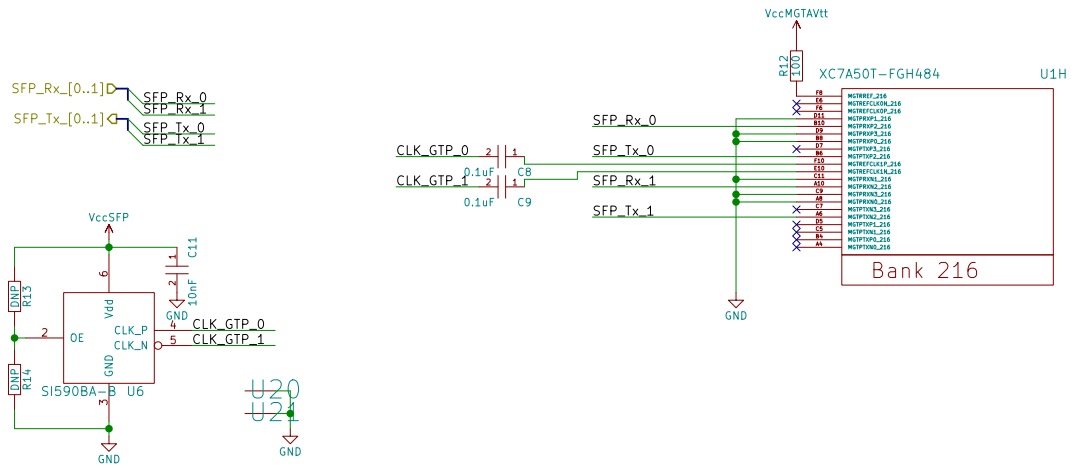
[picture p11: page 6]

1 2 C11 10nF GND GND DNP R13 DNP R14 VccSFP R12 100 VccMGTAVtt GND

File: FPGA_Gb.sch Sheet: /FPGA Gb/
Id: 6/12 Title:

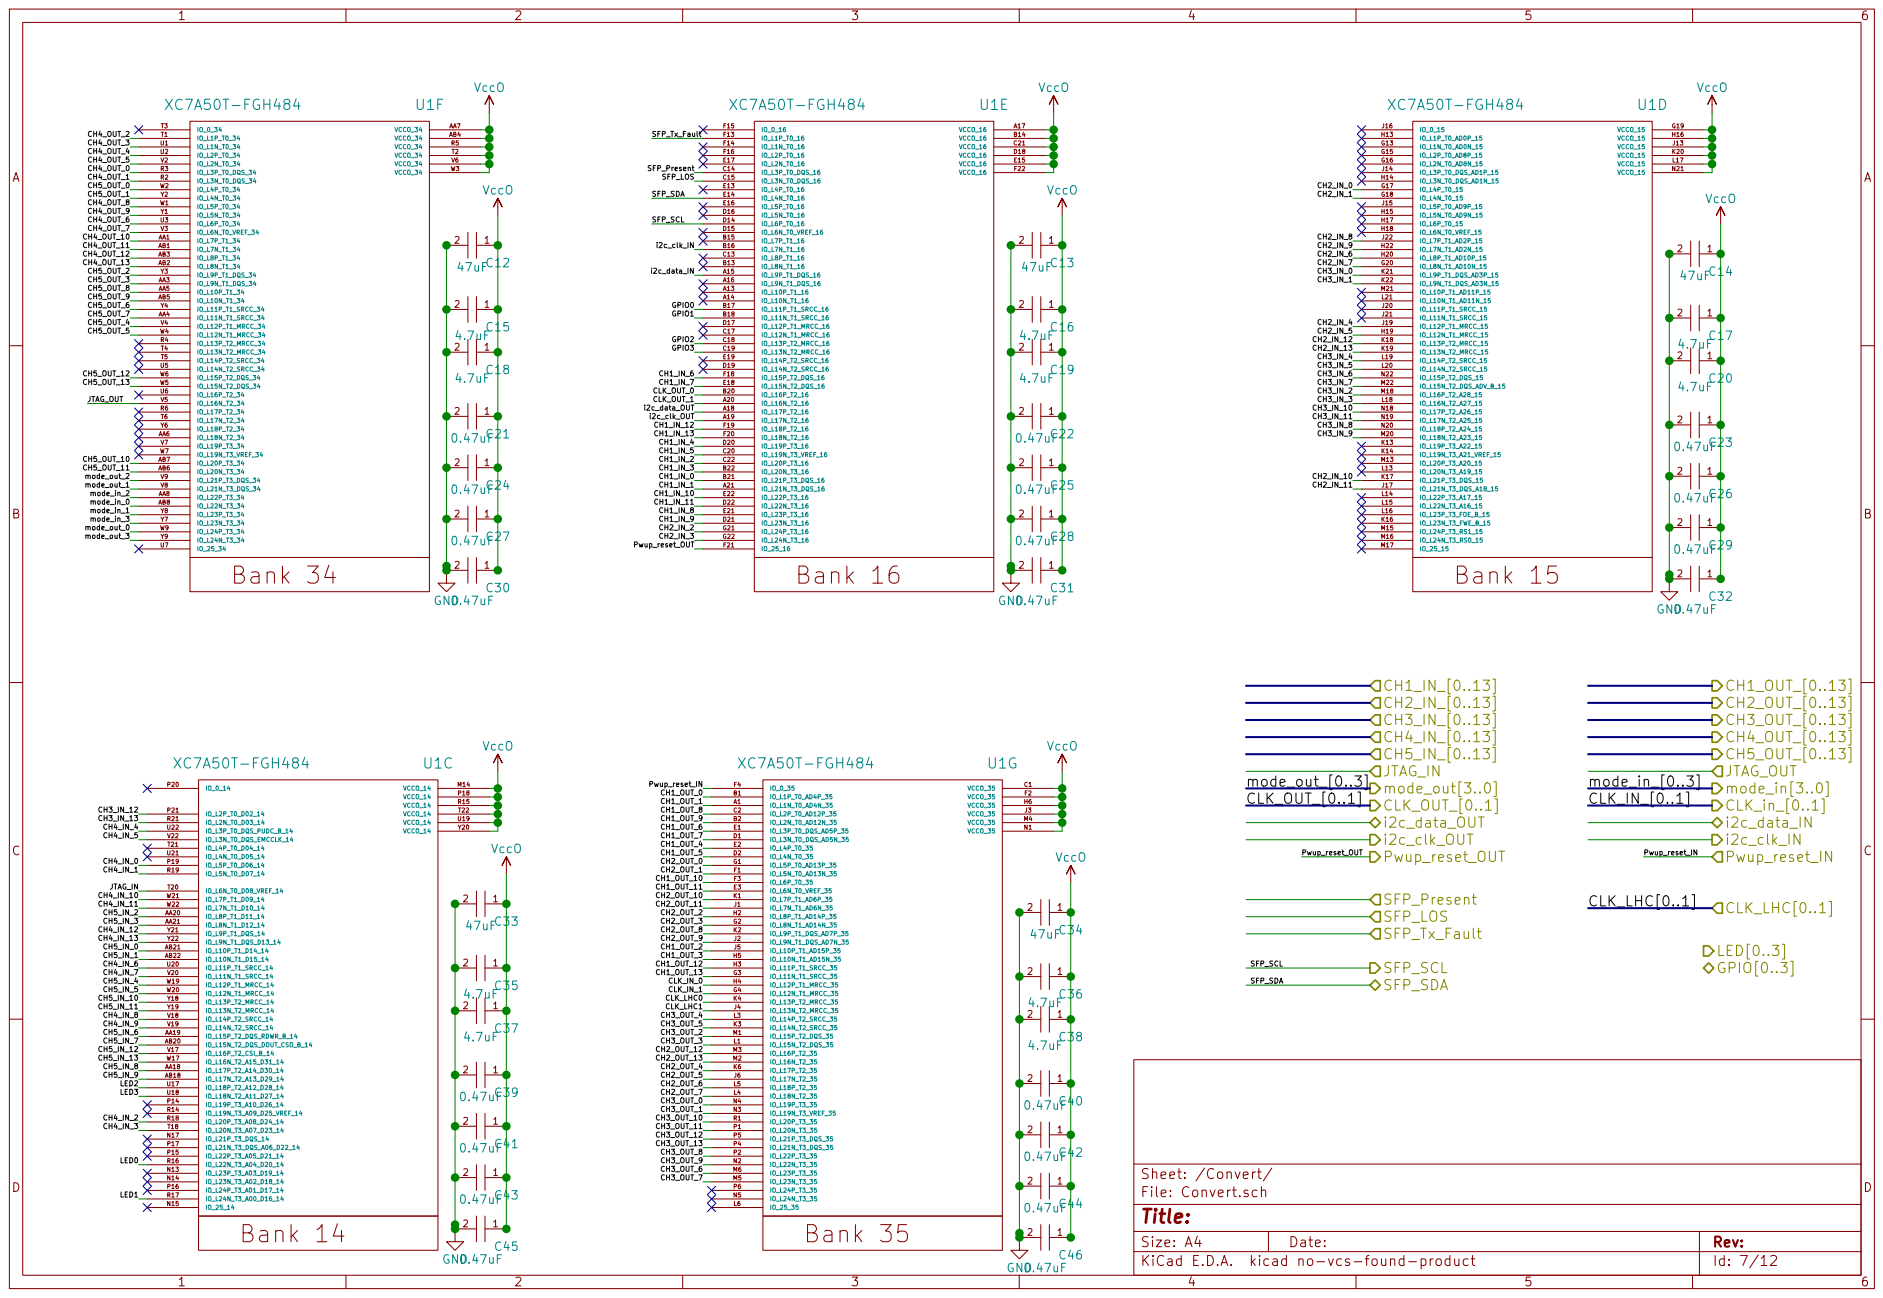
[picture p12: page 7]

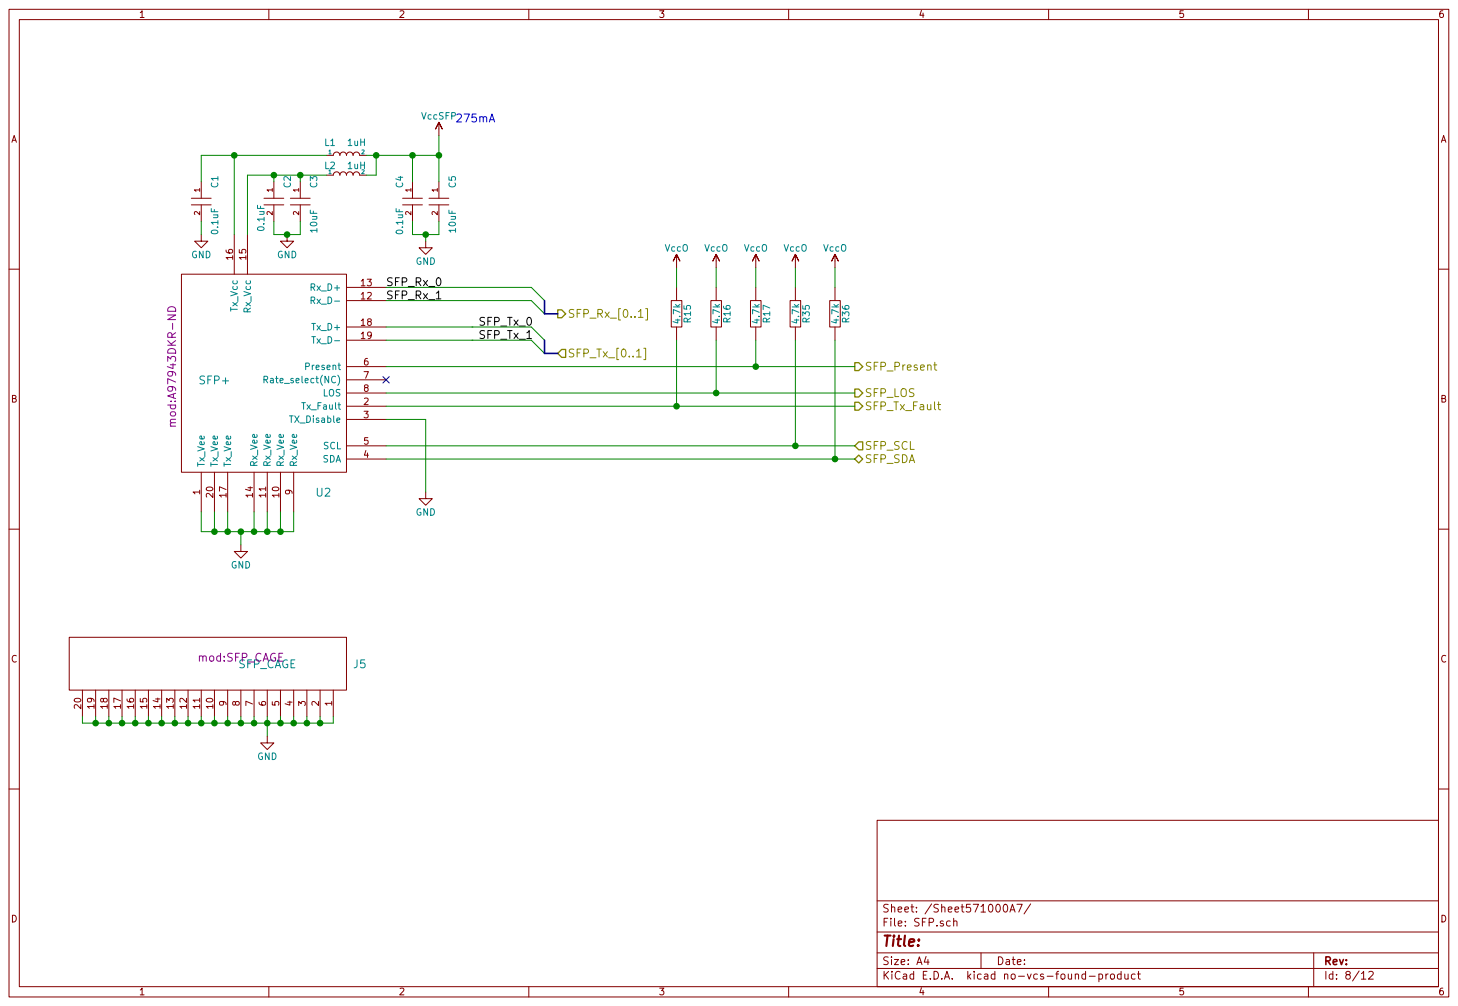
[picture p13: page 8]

1 Tx_Fault 2 TX_Disable 3 SDA 4 SCL 5 Present 6 Rate_select(NC) 7

Id: 8/12 Title: File: SFP.sch Sheet: /Sheet571000A7/ Tx_Vee

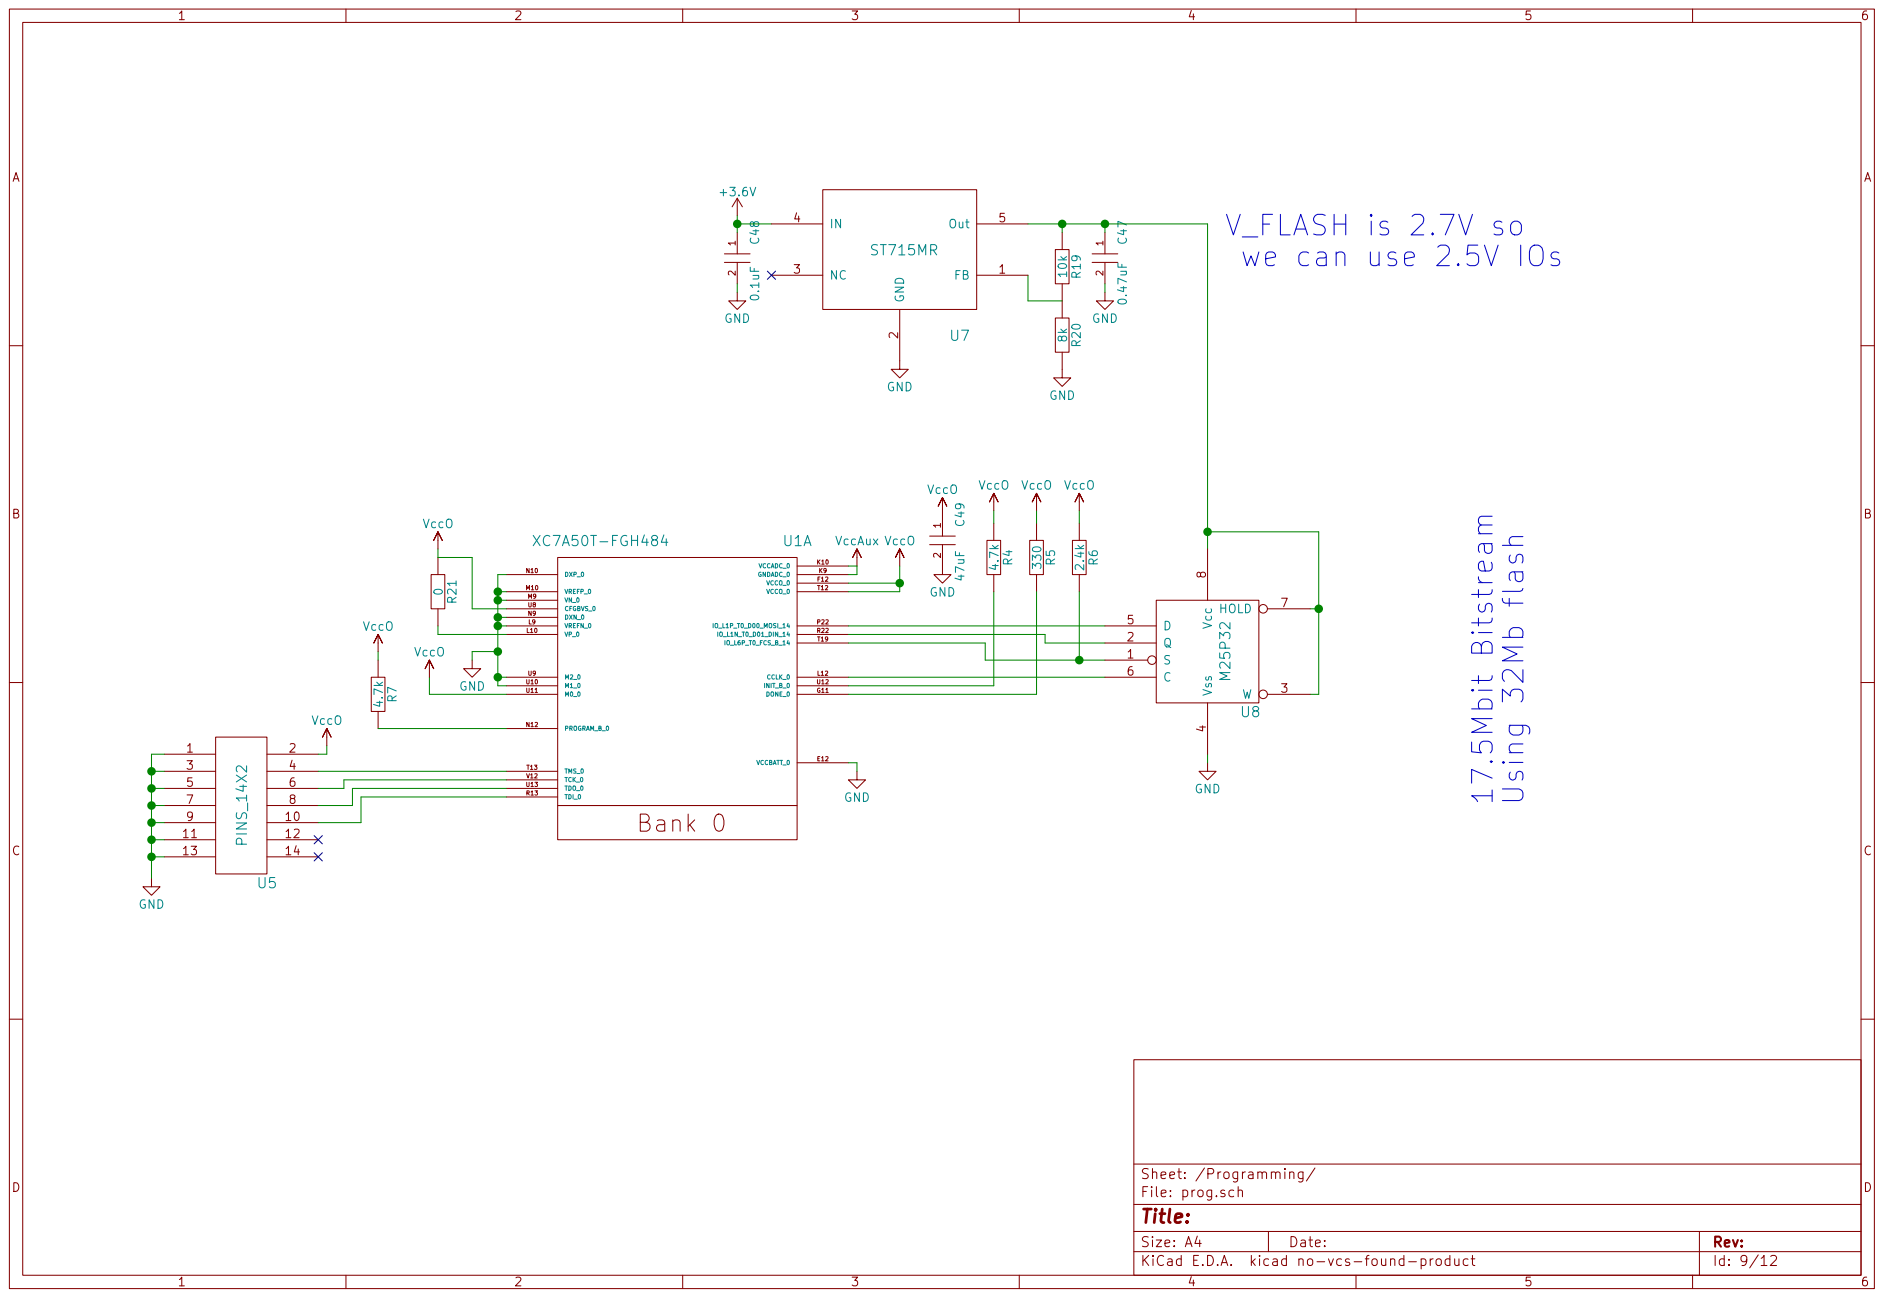
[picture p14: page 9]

V_FLASH is 2.7V so
we can use 2.5V IOs

9 | 10 | Bank 0

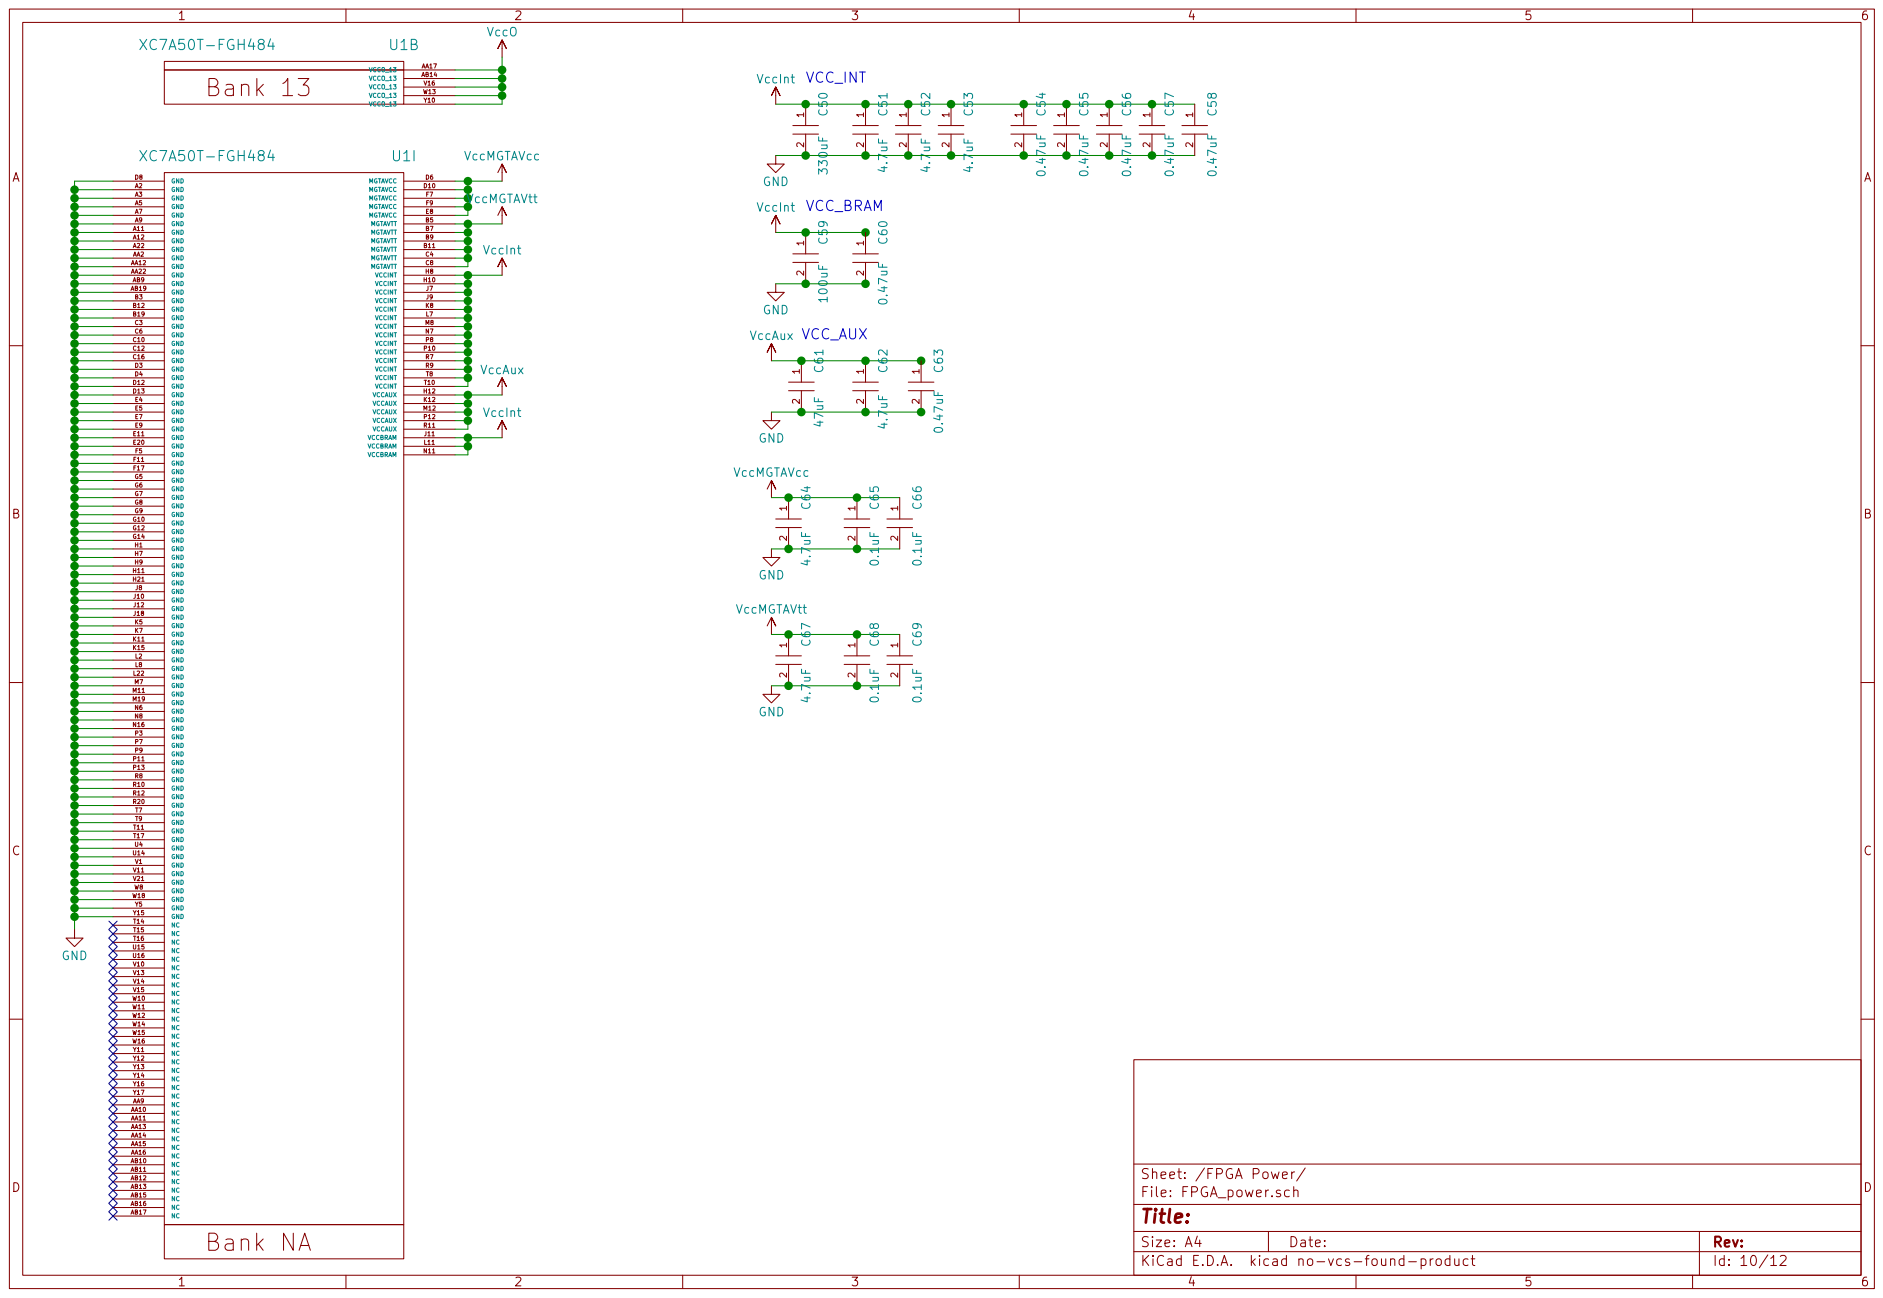
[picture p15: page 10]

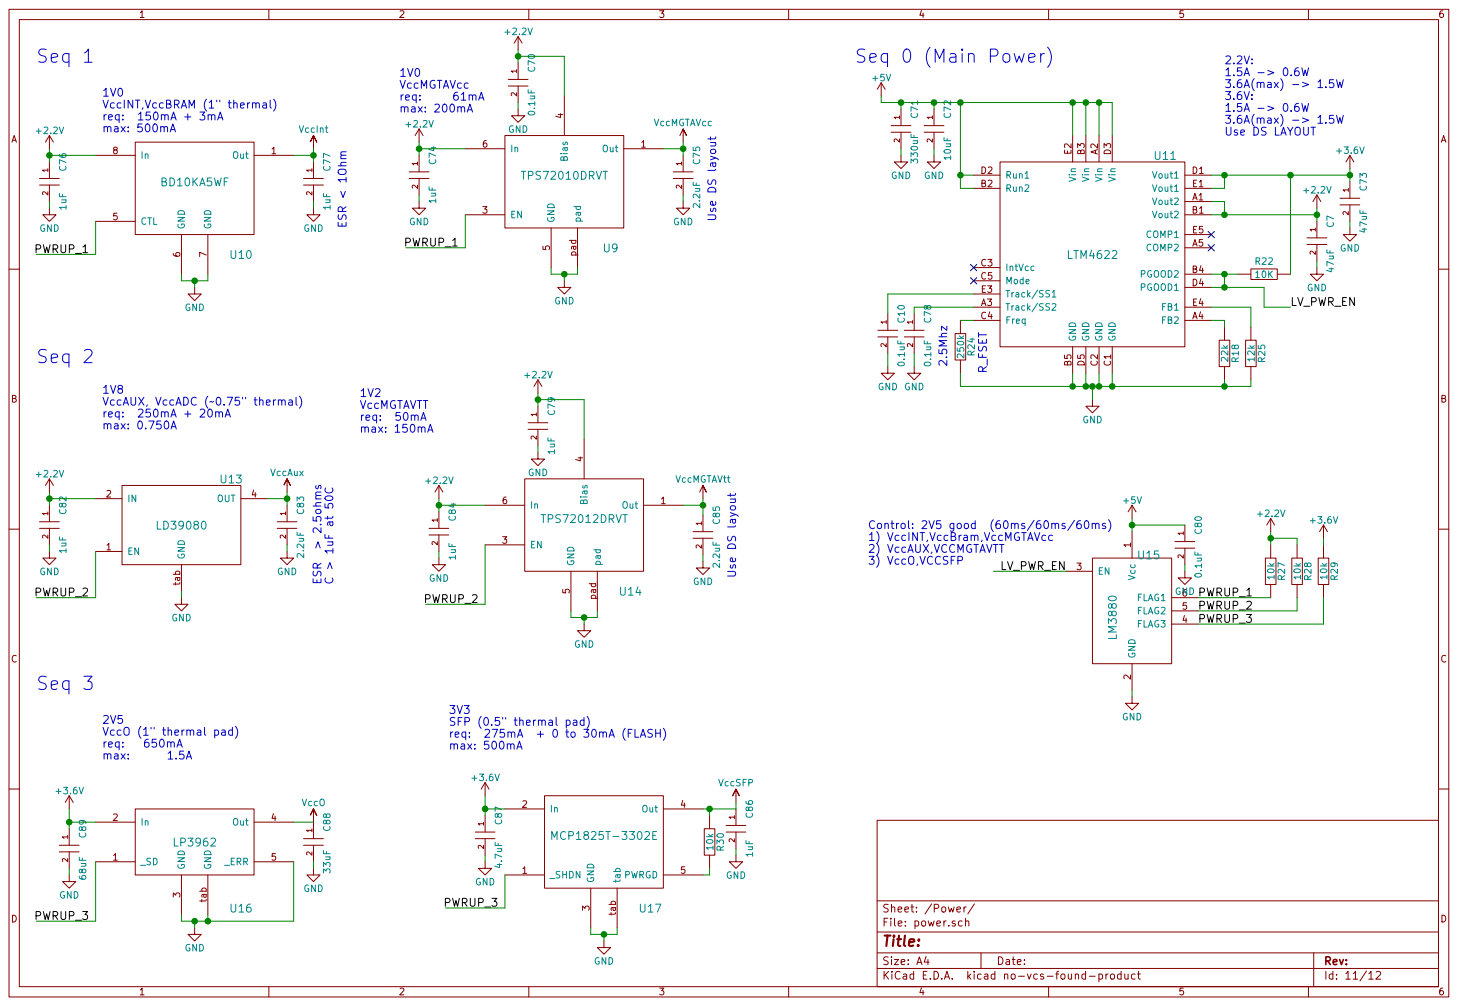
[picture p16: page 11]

1 2 C73 47uF GND
File: power.sch Sheet: /Power/ Control: 2V5 good (60ms/60ms/60ms)
1) VccINT,VccBram,VccMGTAVcc

3V3 SFP (0.5" thermal pad)
req: 275mA + 0 to 30mA (FLASH) max: 500mA


Id: 12/12 Title: File: GPIO.sch Sheet: /GPIOs/










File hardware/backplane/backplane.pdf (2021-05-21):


File: backplane.sch Sheet: / BU EDF


63 | 64
61 | 62

10 | | | 60
12 | 11 | 57 | 58

30 | | | 40
32 | 31 | 37 | 38

50 | | | 20
52 | 51 | 17 | 18

62 | 61
64 | 63

52 | J201 Conn_02x34_Odd_Even-Connector_Generic | 51 | | 1 17 | 18

10 | | | 100 | | | 60
12 | 11 CH37 | | | | 57 | 58
14 | 13 CH38 | | | | 55 | 56
16 | 15 | | | | 53 | 54
18 | 17 | | | | 51 | 52
20 | | | 110 | | | 50
22 | 21 | | | | 47 | 48
24 | 23 | | | | 45 | 46
26 | 25 | | | | 43 | 44
28 | 27 | | | | 41 | 42
30 | | | 120 | | | 40
32 | 31 | | | | 37 | 38
34 | 33 | J302 ERF8-060-05.0-L-DV | | 35 | 36

42 | | 41 | | 27 | 28
44 | | 43 | | 25 | 26
46 | | 45 | | 23 | 24
48 | | 47 | 10 10 | 21 | 22
50 | | | 12 12 | | 20

58 | 57 | 20 20 | 11 | 12
60 | | | | 10

20 | | | 50
22 | 21 | 47 | 48

40 | | | 30
42 | 41 | 27 | 28

60 | | 10


63 | 64
61 | 62

10 | | | 60
12 | 11 | 57 | 58

30 | | | 40
32 | 31 | 37 | 38

50 | | | 20
52 | 51 | 17 | 18

62 | 61
64 | 63

52 | J501 Conn_02x34_Odd_Even-Connector_Generic | 51 | | 1 17 | 18

10 | | | 100 | | | 60
12 | 11 CH37 | | | | 57 | 58
14 | 13 CH38 | | | | 55 | 56
16 | 15 | | | | 53 | 54
18 | 17 | | | | 51 | 52
20 | | | 110 | | | 50
22 | 21 | | | | 47 | 48
24 | 23 | | | | 45 | 46
26 | 25 | | | | 43 | 44
28 | 27 | | | | 41 | 42
30 | | | 120 | | | 40
32 | 31 | | | | 37 | 38
34 | 33 | J602 ERF8-060-05.0-L-DV | | 35 | 36

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

58 | 57 | 20 20 | 11 | 12
60 | | | | 10

20 | | | 50
22 | 21 | 47 | 48

40 | | | 30
42 | 41 | 27 | 28

60 | | 10


63 | 64
61 | 62

10 | | | 60
12 | 11 | 57 | 58

30 | | | 40
32 | 31 | 37 | 38

50 | | | 20
52 | 51 | 17 | 18

62 | 61
64 | 63

52 | J801 Conn_02x34_Odd_Even-Connector_Generic | 51 | | 1 17 | 18

10 | | | 100 | | | 60
12 | 11 CH37 | | | | 57 | 58
14 | 13 CH38 | | | | 55 | 56
16 | 15 | | | | 53 | 54
18 | 17 | | | | 51 | 52
20 | | | 110 | | | 50
22 | 21 | | | | 47 | 48
24 | 23 | | | | 45 | 46
26 | 25 | | | | 43 | 44
28 | 27 | | | | 41 | 42
30 | | | 120 | | | 40
32 | 31 | | | | 37 | 38
34 | 33 | J902 ERF8-060-05.0-L-DV | | 35 | 36

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

58 | 57 | 20 20 | 11 | 12
60 | | | | 10

20 | | | 50
22 | 21 | 47 | 48

40 | | | 30
42 | 41 | 27 | 28

60 | | 10

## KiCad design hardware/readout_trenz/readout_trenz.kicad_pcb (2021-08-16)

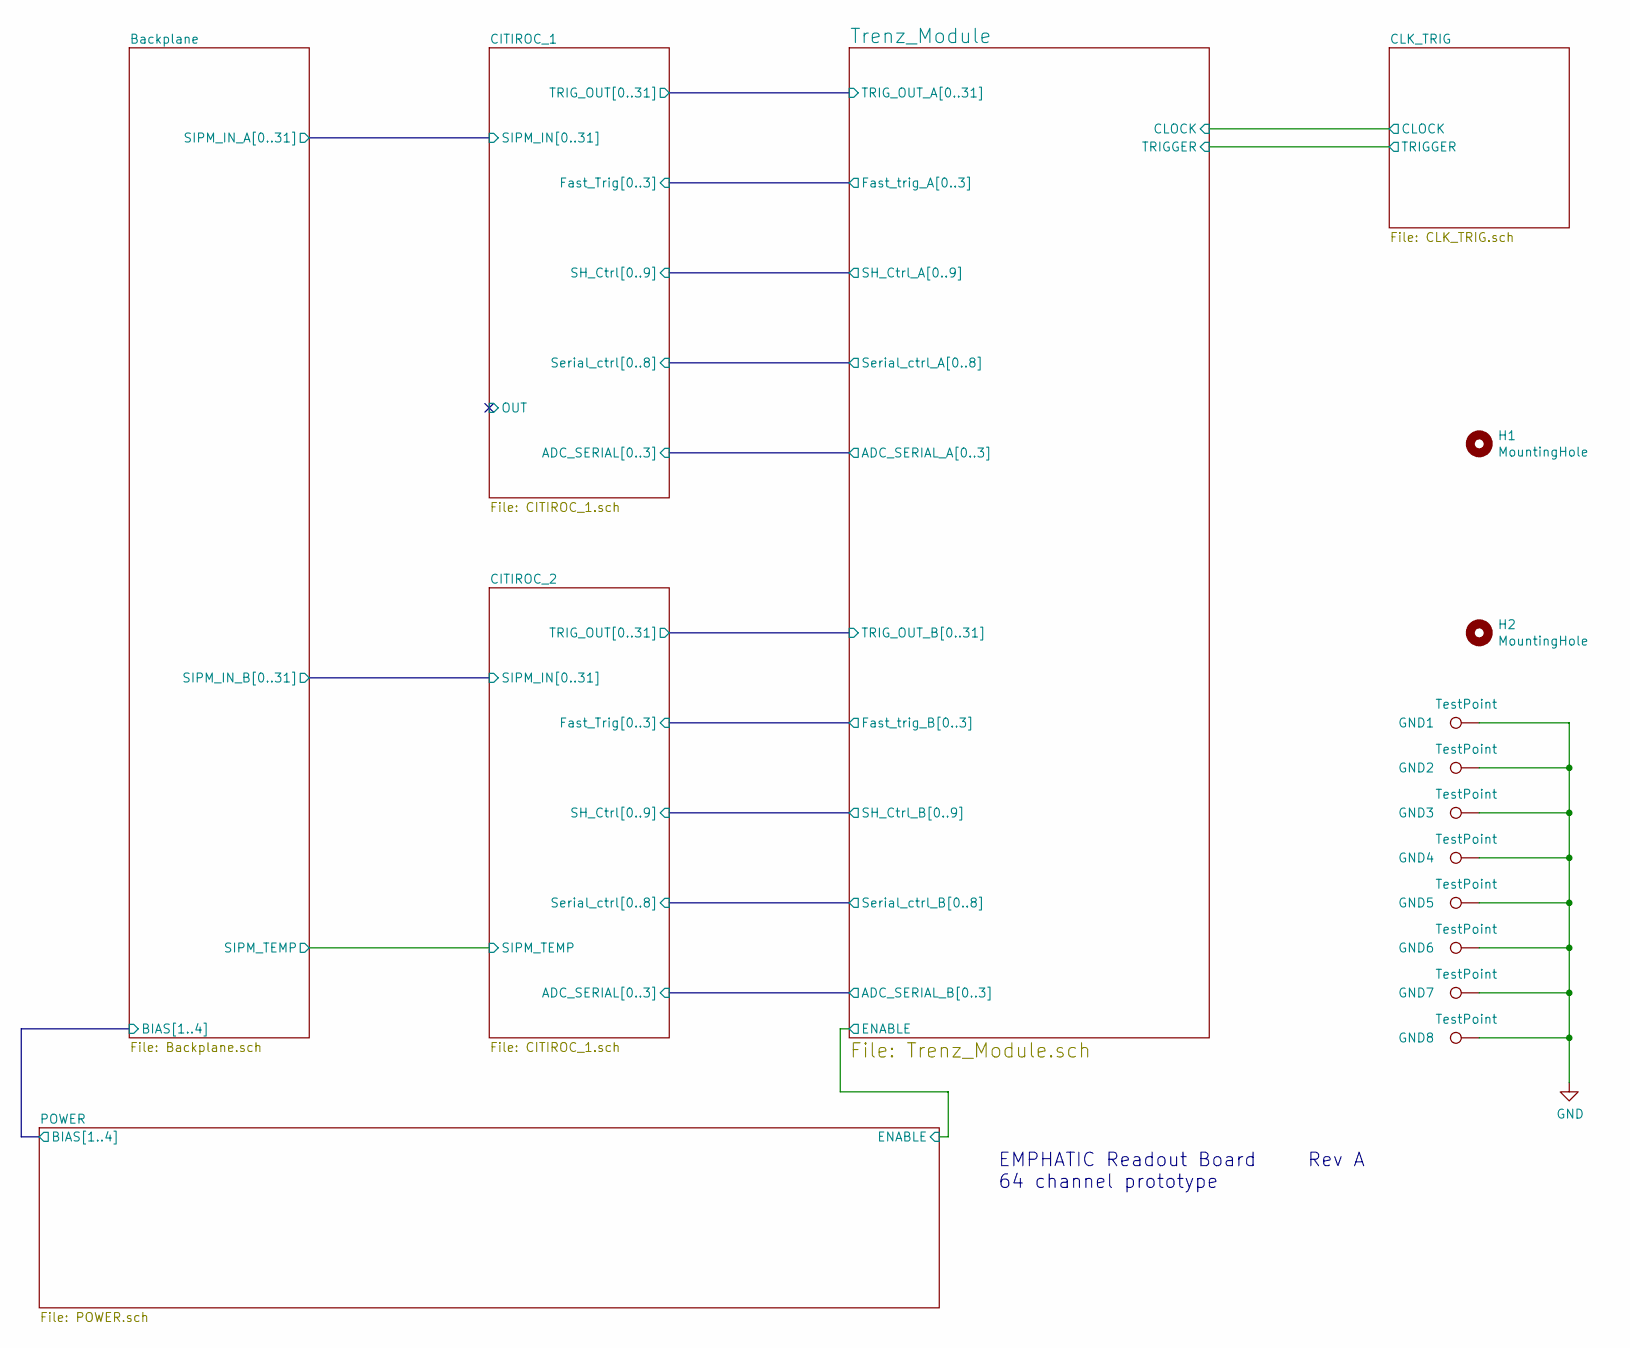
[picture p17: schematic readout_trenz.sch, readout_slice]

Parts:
GND1, GND2, GND3, GND4, GND5, GND6, GND7, GND8: TestPoint; TestPoint_Keystone_5000-5004_Miniature
H1, H2: MountingHole; MountingHole_0.11''

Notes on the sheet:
EMPHATIC Readout Board Rev A 64 channel prototype

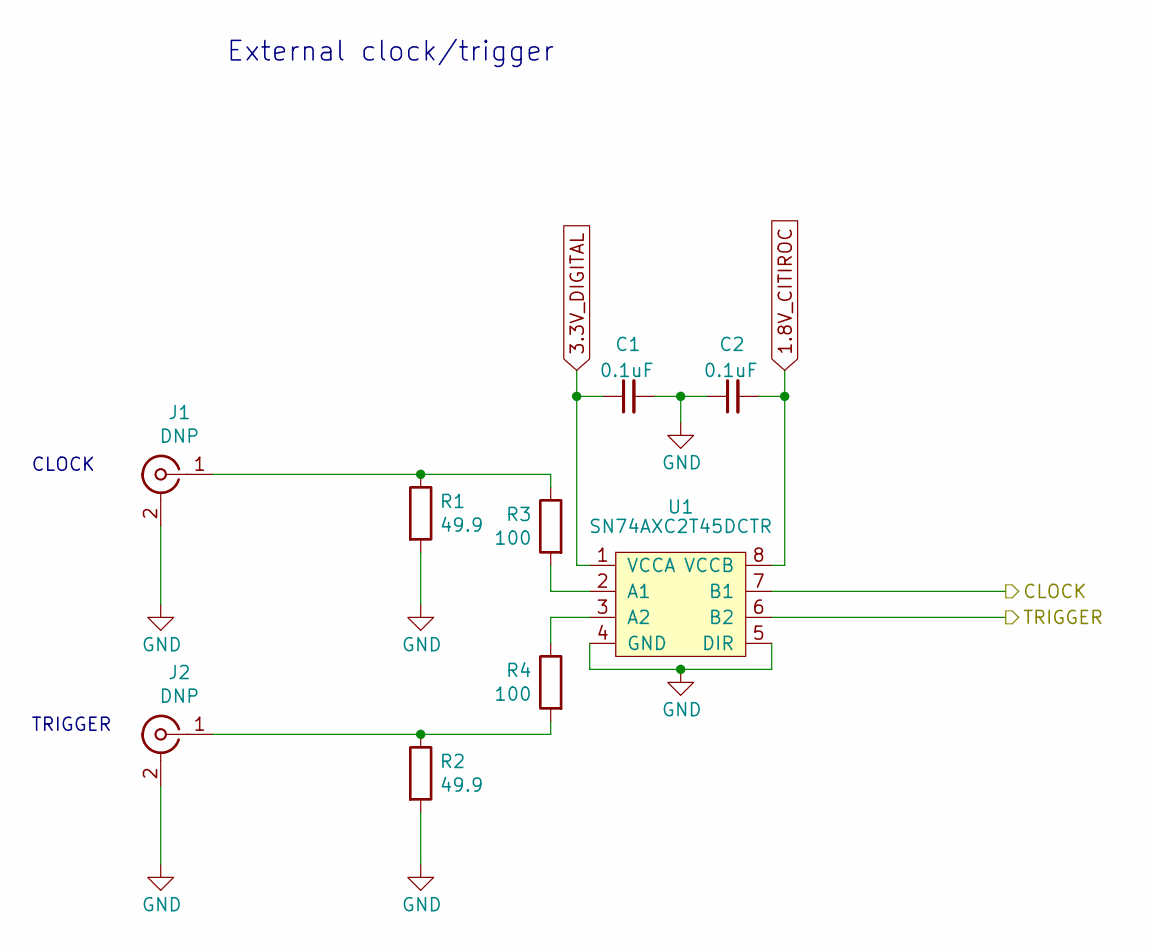
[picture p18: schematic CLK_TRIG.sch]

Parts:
C1, C2: 0.1uF; C_0603_1608Metric_Pad1.05x0.95mm_HandSolder
J1, J2: DNP; lemo-EPB.00.250.NTN
R1, R2: 49.9; R_0402_1005Metric
R3, R4: 100; R_0603_1608Metric_Pad1.05x0.95mm_HandSolder
U1: SN74AXC2T45DCTR; SSOP-8_2.95x2.8mm_P0.65mm

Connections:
1.8V_CITIROC: C2.2, U1.8 (VCCB); also elsewhere on the board
3.3V_DIGITAL: C1.1, U1.1 (VCCA); also elsewhere on the board
/CLK_TRIG/CLOCK: U1.7 (B1); also elsewhere on the board
/CLK_TRIG/TRIGGER: U1.6 (B2); also elsewhere on the board
unnamed: J1.1 (In), R1.1, R3.1
unnamed: J2.1 (In), R2.1, R4.2
unnamed: R3.2, U1.2 (A1)
unnamed: R4.1, U1.3 (A2)

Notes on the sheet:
CLOCK
TRIGGER
External clock/trigger

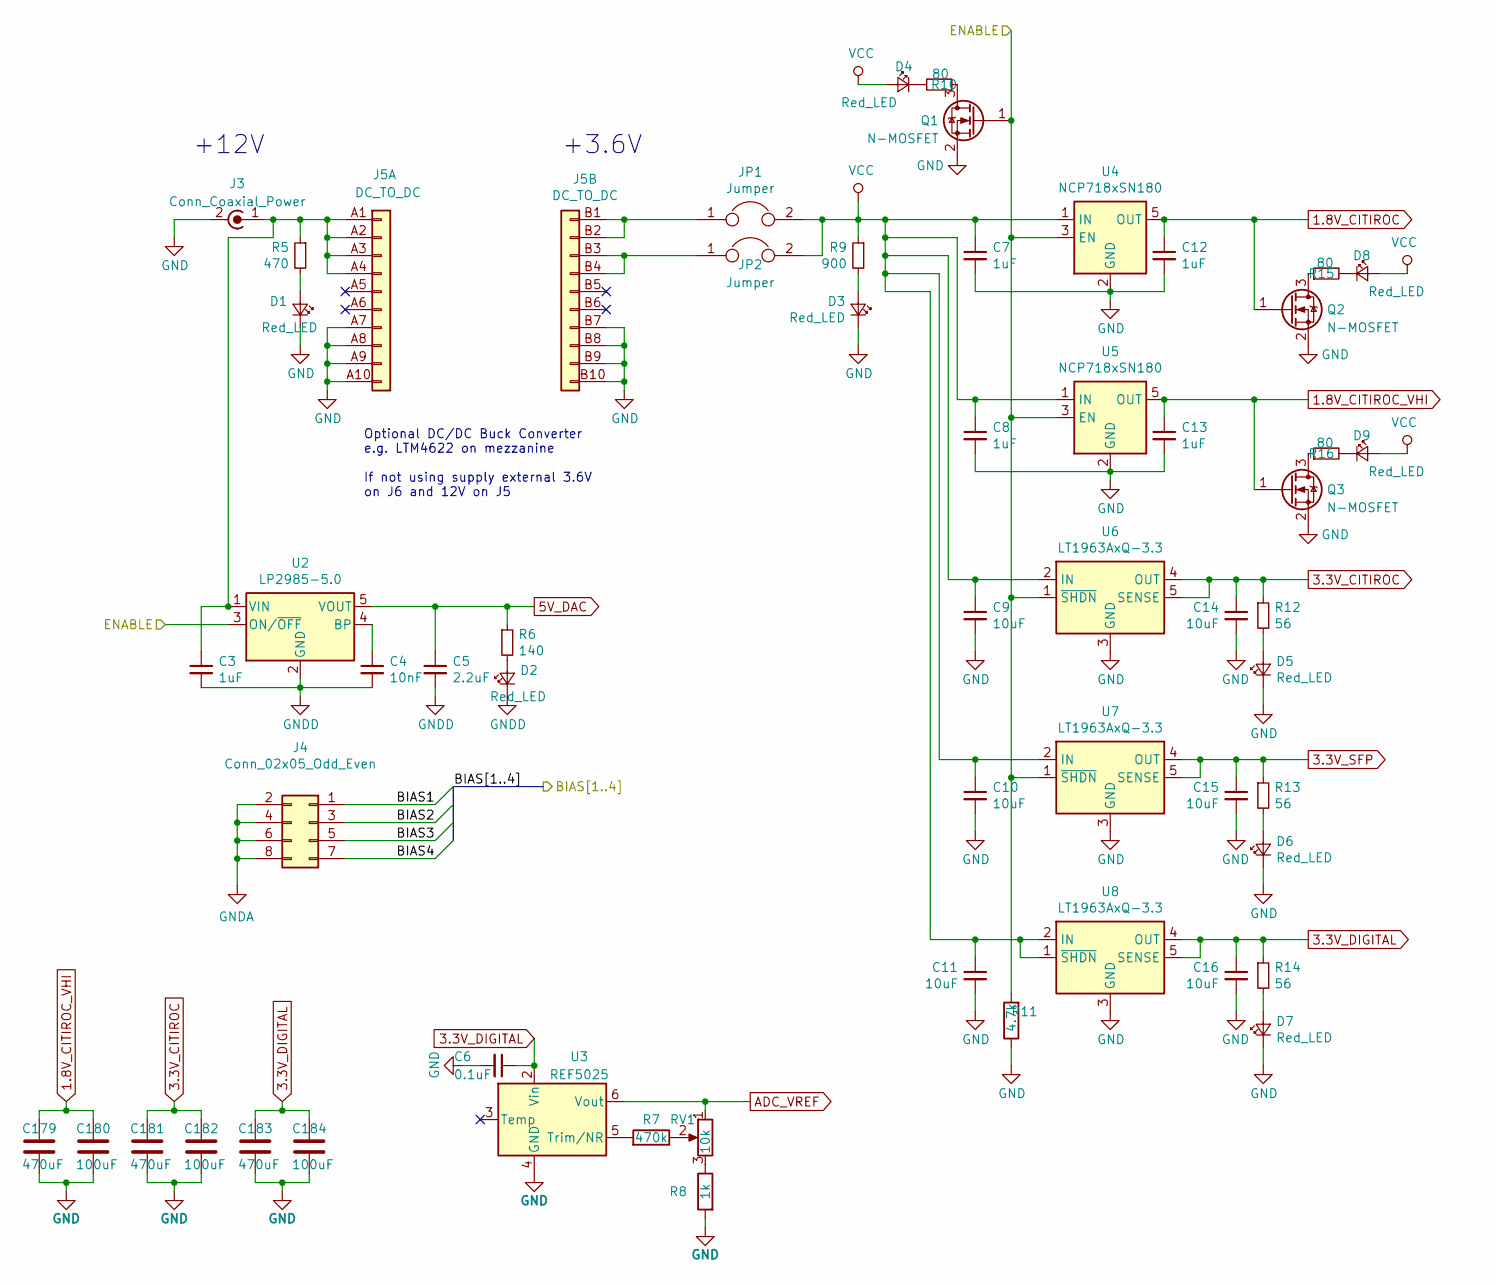
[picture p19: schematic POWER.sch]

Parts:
C3, C7, C8, C12, C13: 1uF; C_0603_1608Metric_Pad1.05x0.95mm_HandSolder
C4: 10nF; C_0603_1608Metric_Pad1.05x0.95mm_HandSolder
C5: 2.2uF; C_0603_1608Metric_Pad1.05x0.95mm_HandSolder
C6: 0.1uF; C_0603_1608Metric_Pad1.05x0.95mm_HandSolder
C9, C10, C11, C14, C15, C16: 10uF; C_0805_2012Metric_Pad1.15x1.40mm_HandSolder
C179, C181, C183: 470uF; EEE-0JA471UAP
C180, C182, C184: 100uF; EEE-0JA101WR
D1, D2, D3, D4, D5, D6, D7, D8, D9: Red_LED; LED_D3.0mm
J3: Conn_Coaxial_Power; BarrelJack_Wuerth_6941xx301002
J4: Conn_02x05_Odd_Even; PinHeader_2x04_P2.54mm_Vertical
J5: DC_TO_DC
JP1, JP2: Jumper; PinHeader_1x02_P2.54mm_Vertical
Q1, Q2, Q3: N-MOSFET; SOT-416
R5: 470; R_0805_2012Metric_Pad1.15x1.40mm_HandSolder
R6: 140; R_0603_1608Metric_Pad1.05x0.95mm_HandSolder
R7: 470k; R_1206_3216Metric_Pad1.42x1.75mm_HandSolder
R8: 1k; R_0805_2012Metric_Pad1.15x1.40mm_HandSolder
R9: 900; R_1206_3216Metric_Pad1.42x1.75mm_HandSolder
R10, R15, R16: 80; R_0603_1608Metric_Pad1.05x0.95mm_HandSolder
R11: 4.7k; R_1206_3216Metric_Pad1.42x1.75mm_HandSolder
R12, R13, R14: 56; R_0603_1608Metric_Pad1.05x0.95mm_HandSolder
RV1: 10k; Potentiometer_ACP_CA6-H2,5_Horizontal
U2: LP2985-5.0; SOT-23-5_HandSoldering
U3: REF5025; SOIC-8_3.9x4.9mm_P1.27mm
U4, U5: NCP718xSN180; TSOT-23-5_HandSoldering
U6, U7, U8: LT1963AxQ-3.3; TO-263-5_TabPin3

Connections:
1.8V_CITIROC: C12.1, Q2.1 (G), U4.5 (OUT); also elsewhere on the board
1.8V_CITIROC_VHI: C13.1, C179.1, C180.1, Q3.1 (G), U5.5 (OUT); also elsewhere on the board
3.3V_CITIROC: C14.1, C181.1, C182.1, R12.1, U6.4 (OUT), U6.5 (SENSE); also elsewhere on the board
3.3V_DIGITAL: C6.1, C16.1, C183.1, C184.1, R14.1, U3.2 (Vin), U8.4 (OUT), U8.5 (SENSE); also elsewhere on the board
3.3V_SFP: C15.1, R13.1, U7.4 (OUT), U7.5 (SENSE); also elsewhere on the board
5V_DAC: C5.1, R6.1, U2.5 (VOUT); also elsewhere on the board
/Backplane/BIAS1: J4.1; also elsewhere on the board
/Backplane/BIAS2: J4.3; also elsewhere on the board
/Backplane/BIAS3: J4.5; also elsewhere on the board
/Backplane/BIAS4: J4.7; also elsewhere on the board
/POWER/ENABLE: Q1.1 (G), R11.2, U2.3 (ON/~OFF~), U4.3 (EN), U5.3 (EN), U6.1 (~SHDN), U7.1 (~SHDN); also elsewhere on the board
ADC_VREF: RV1.1, U3.6 (Vout); also elsewhere on the board
unnamed: C3.1, J3.1 (In), J5.A1, J5.A2, J5.A3, J5.A4, R5.1, U2.1 (VIN)
unnamed: C4.1, U2.4 (BP)
unnamed: D1.2 (A), R5.2
unnamed: D2.2 (A), R6.2
unnamed: D3.2 (A), R9.2
unnamed: D4.1 (K), R10.2
unnamed: D5.2 (A), R12.2
unnamed: D6.2 (A), R13.2
unnamed: D7.2 (A), R14.2
unnamed: D8.1 (K), R15.2
unnamed: D9.1 (K), R16.2
unnamed: J5.B1, J5.B2, JP1.1
unnamed: J5.B3, J5.B4, JP2.1
unnamed: Q1.3 (D), R10.1
unnamed: Q2.3 (D), R15.1
unnamed: Q3.3 (D), R16.1
unnamed: R7.1, RV1.2
unnamed: R7.2, U3.5 (Trim/NR)
unnamed: R8.1, RV1.3
VCC: C7.1, C8.1, C9.1, C10.1, C11.1, D4.2 (A), D8.2 (A), D9.2 (A), JP1.2, JP2.2, R9.1, U4.1 (IN), U5.1 (IN), U6.2 (IN), U7.2 (IN), U8.1 (~SHDN), U8.2 (IN)

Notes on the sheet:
+12V
+3.6V
Optional DC/DC Buck Converter e.g. LTM4622 on mezzanine If not using supply external 3.6V on J6 and 12V on J5

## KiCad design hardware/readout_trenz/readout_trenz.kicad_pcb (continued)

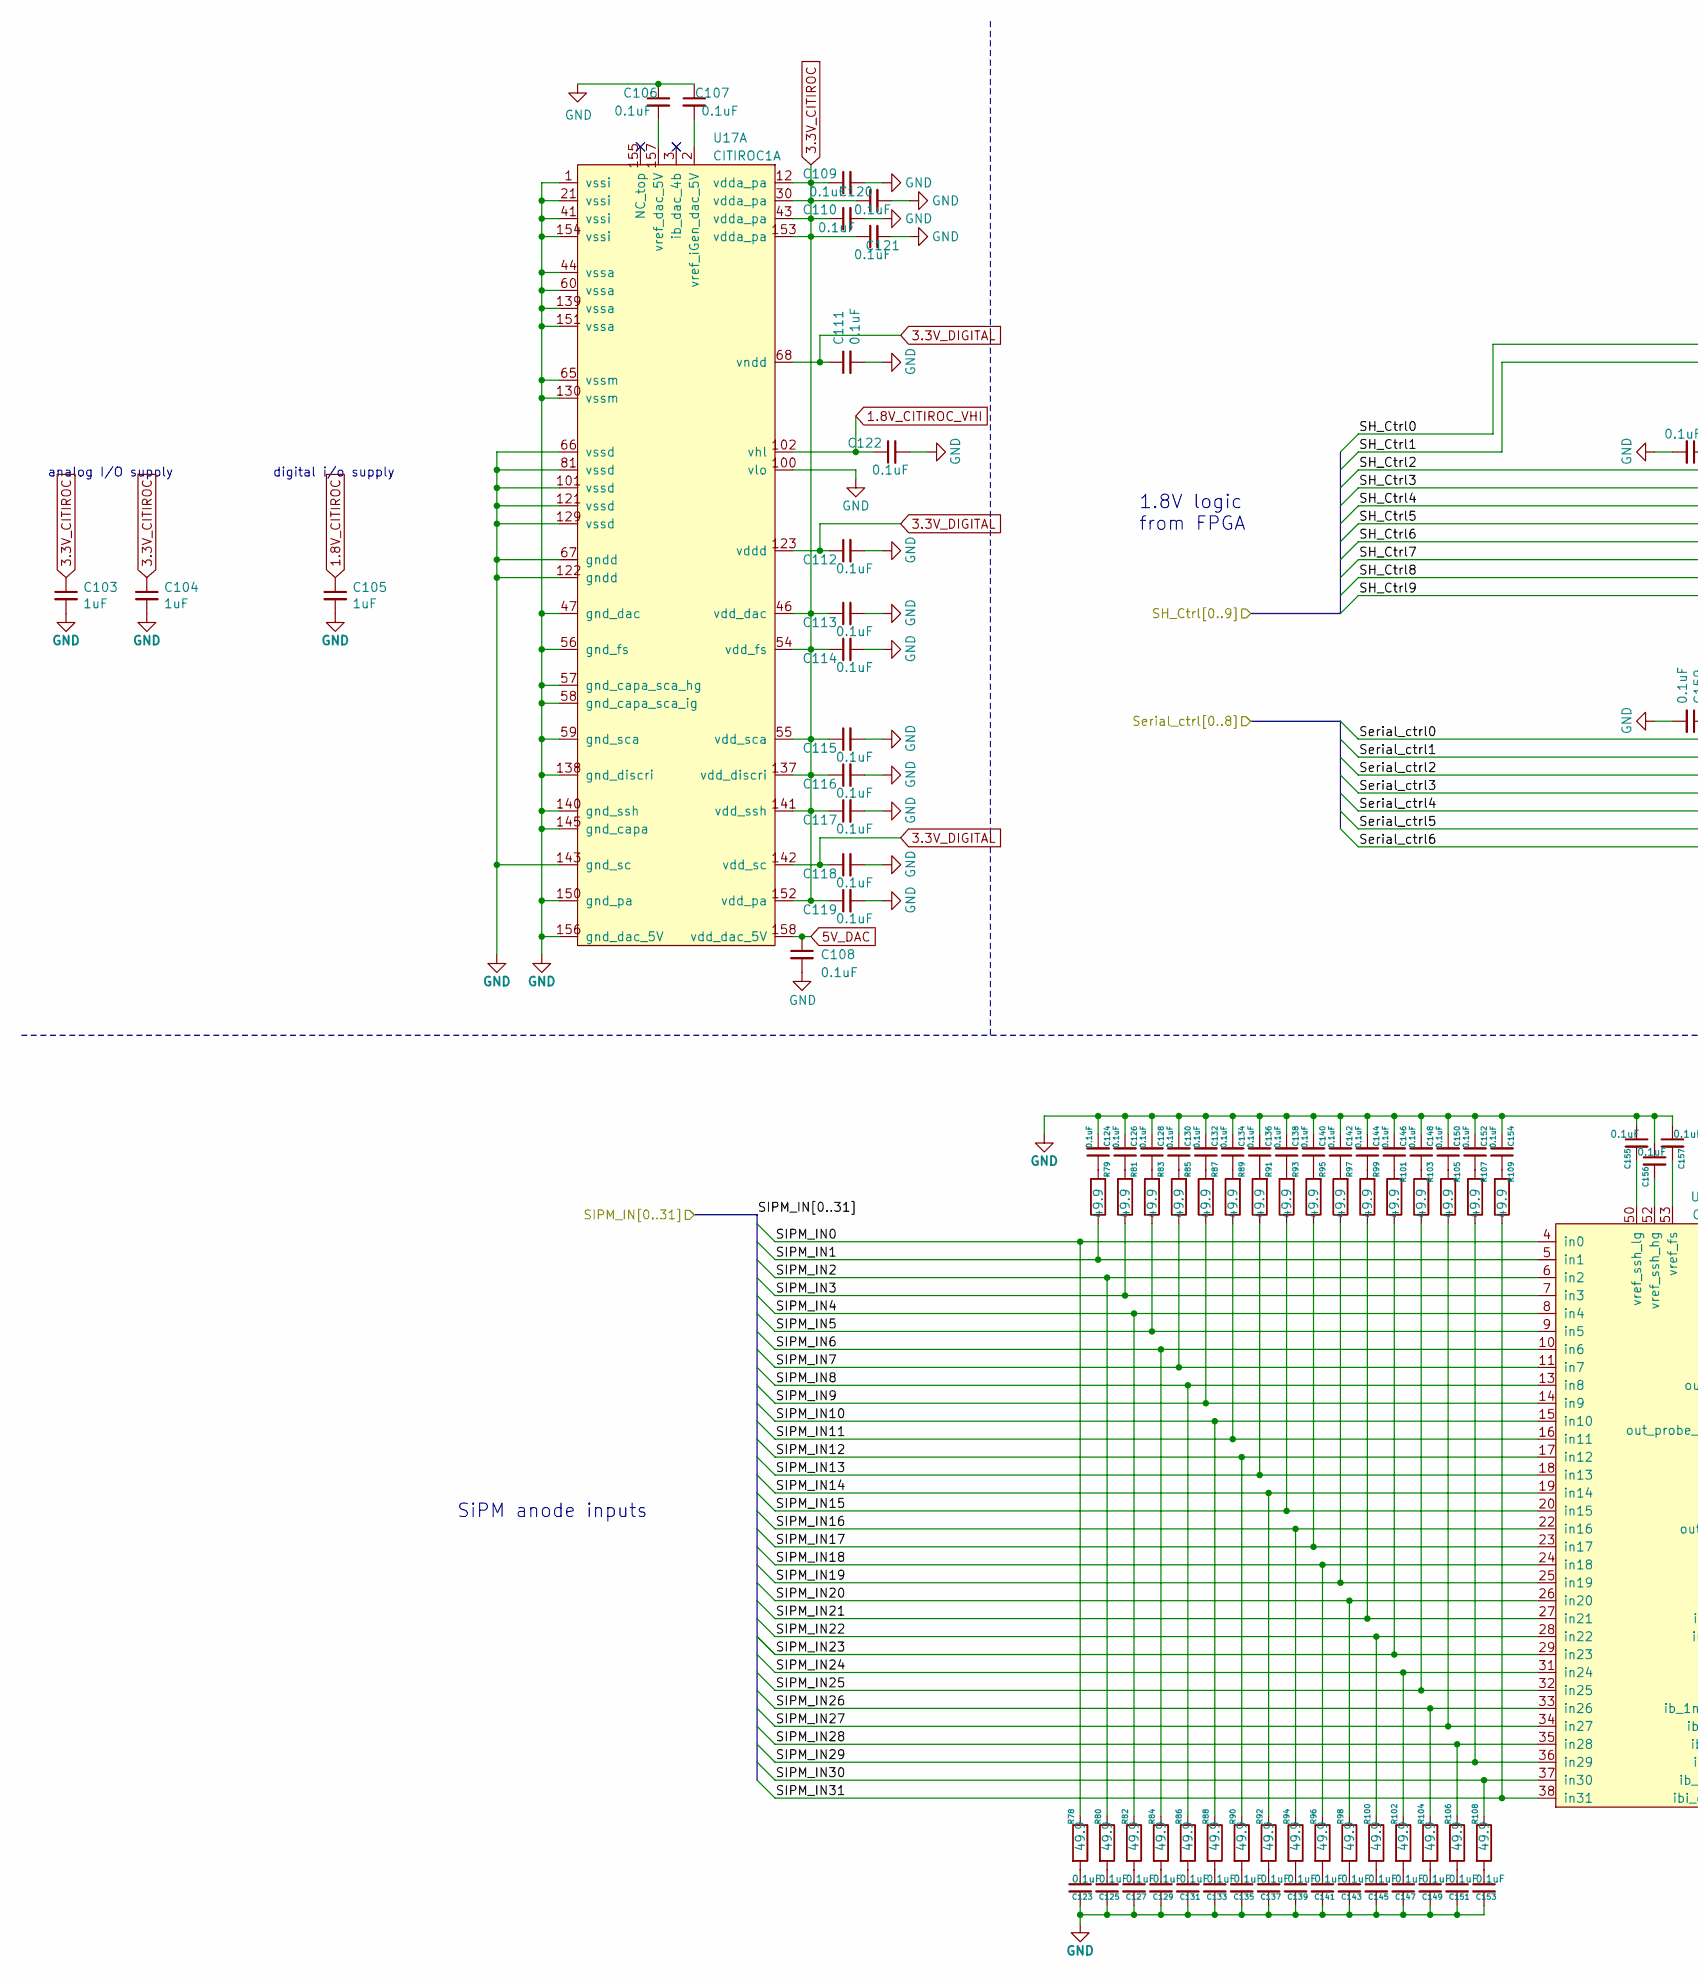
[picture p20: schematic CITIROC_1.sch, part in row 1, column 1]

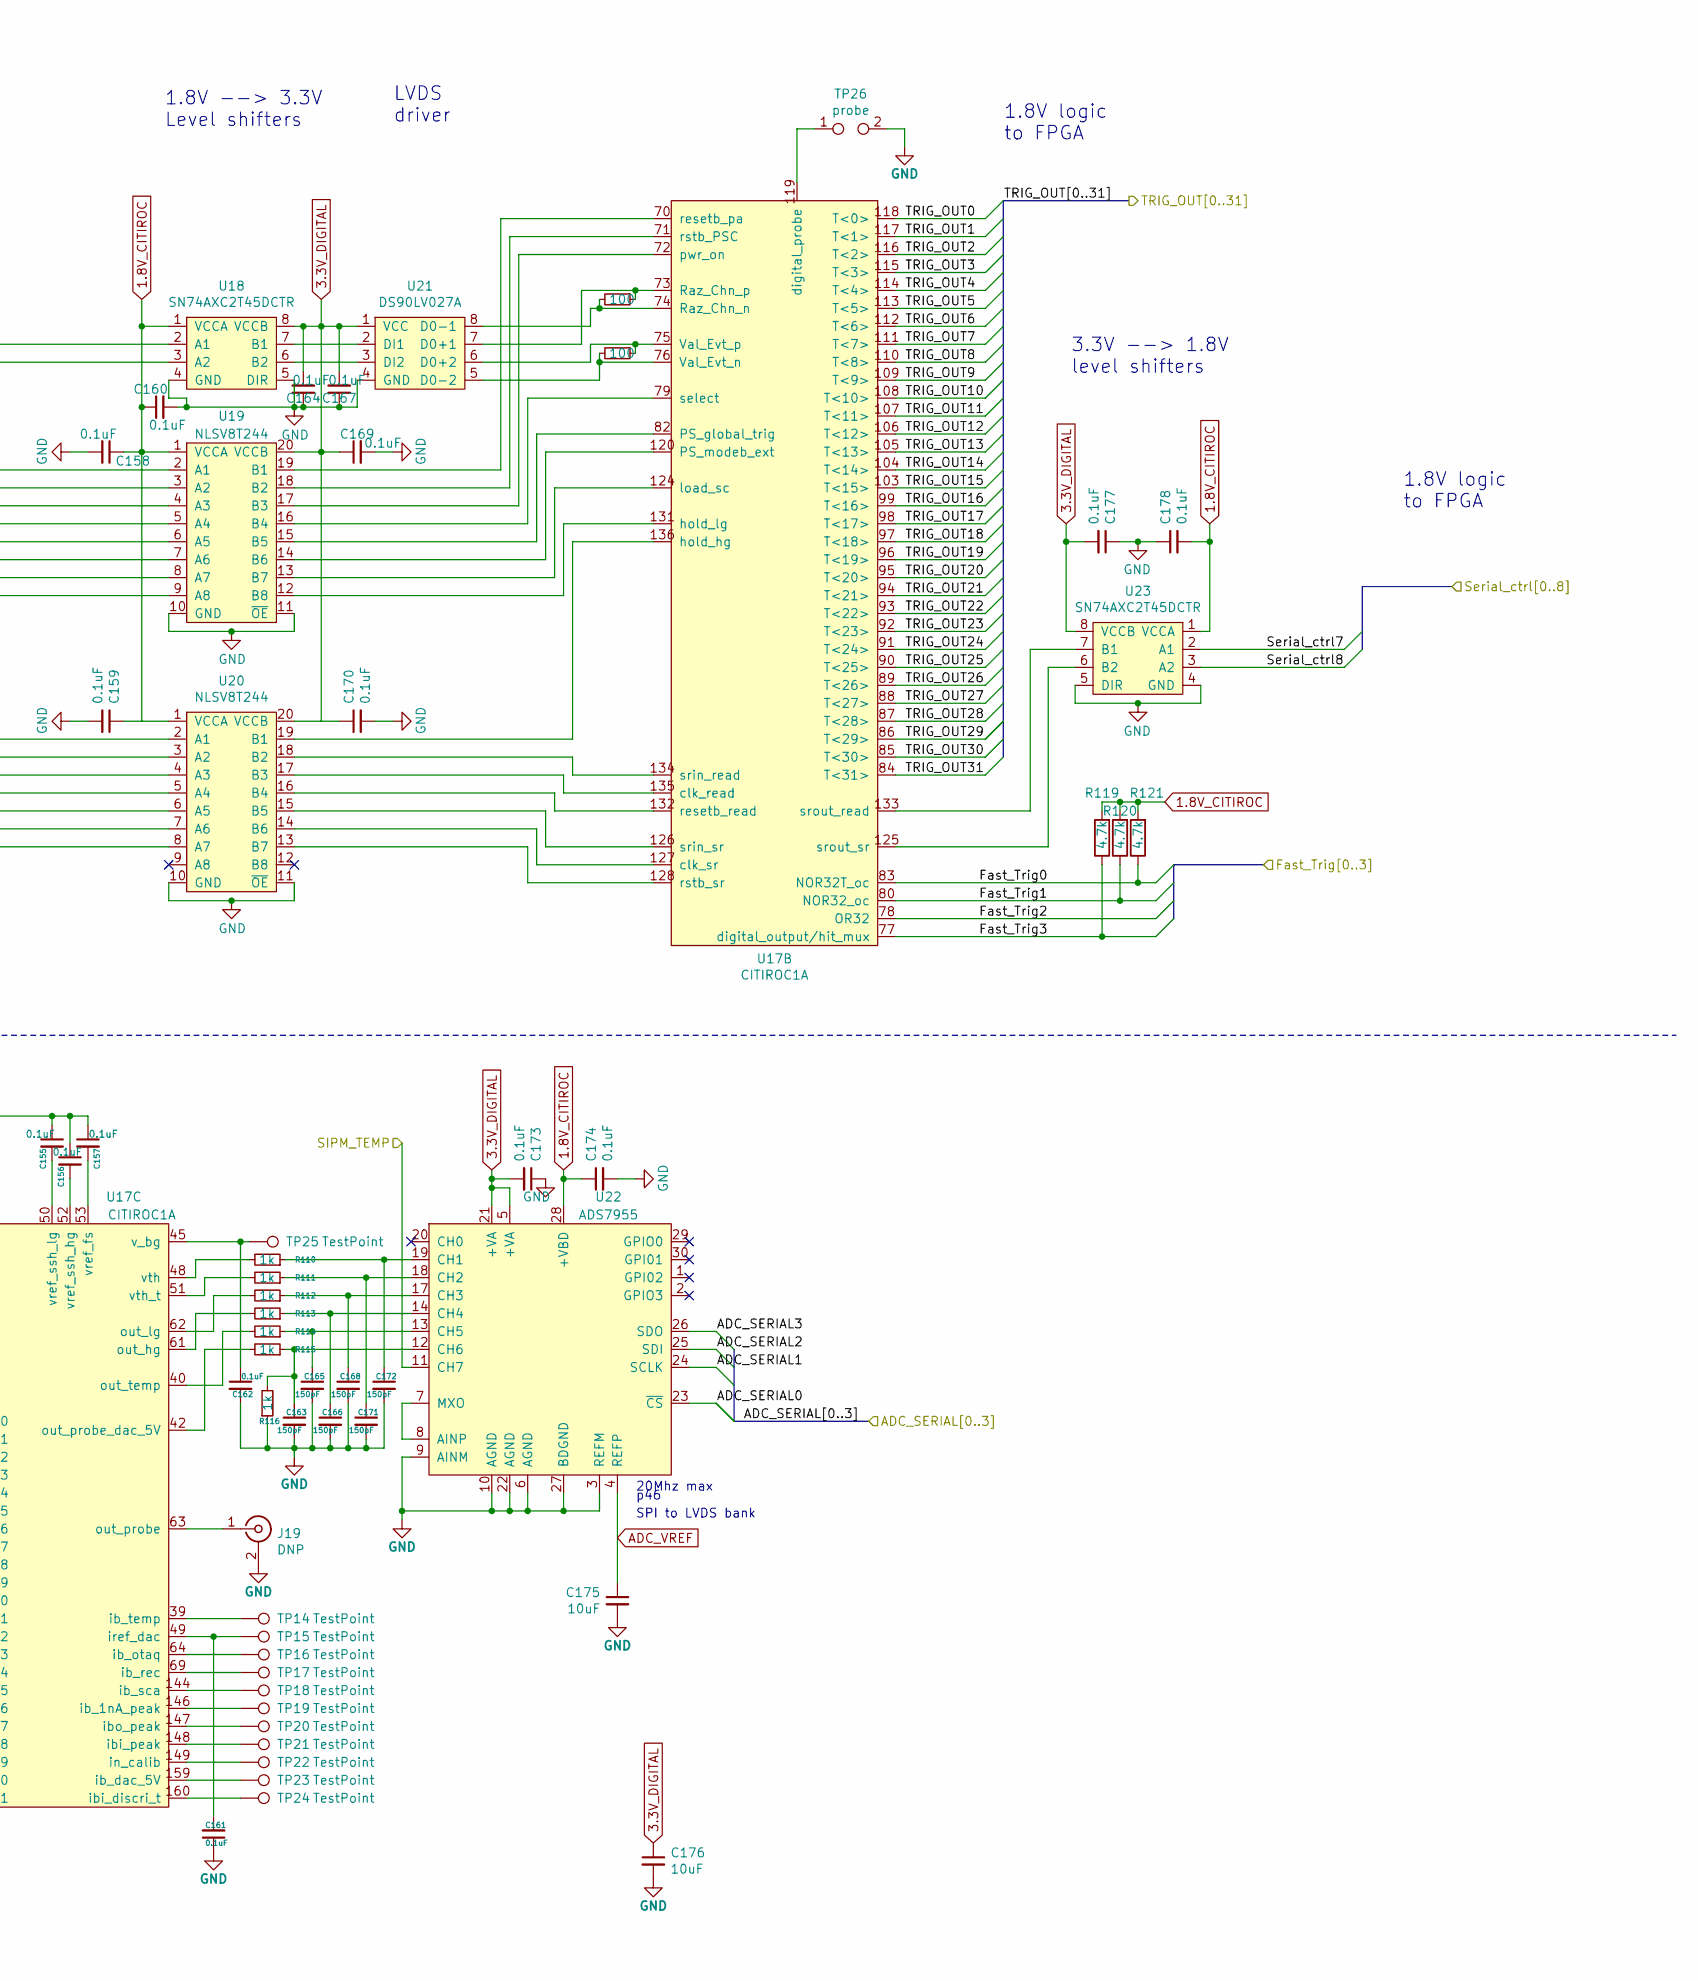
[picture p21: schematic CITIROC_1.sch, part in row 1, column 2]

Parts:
C20, C21, C22, C23, C24, C25, C26, C27, C28, C29, C30, C31, C32, C33, C34, C35, C36, C72, C73, C74, C78, C81, C83, C84, C87, C88, C91, C92, C155, C156, C157, C161, C162: 0.1uF; C_0603_1608Metric_Pad1.05x0.95mm_HandSolder
C103, C104, C105: 1uF; C_0603_1608Metric_Pad1.05x0.95mm_HandSolder
C123, C124, C125, C126, C127, C128, C129, C130, C131, C132, C133, C134, C135, C136, C137, C138, C139, C140, C141, C142, C143, C144, C145, C146, C147, C148, C149, C150, C151, C152, C153, C154: 0.1uF; C_0402_1005Metric
C163, C165, C166, C168, C171, C172: 150pF; C_0603_1608Metric_Pad1.05x0.95mm_HandSolder
C175, C176: 10uF; C_0805_2012Metric_Pad1.15x1.40mm_HandSolder
J19: DNP; lemo-EPB.00.250.NTN
R58, R59, R60: 4.7k; R_1206_3216Metric_Pad1.42x1.75mm_HandSolder
R78, R79, R80, R81, R82, R83, R84, R85, R86, R87, R88, R89, R90, R91, R92, R93, R94, R95, R96, R97, R98, R99, R100, R101, R102, R103, R104, R105, R106, R107, R108, R109: 49.9; R_0402_1005Metric
R110, R111, R112, R113, R114, R115, R116: 1k; R_0603_1608Metric_Pad1.05x0.95mm_HandSolder
R117, R118: 100; R_0603_1608Metric_Pad1.05x0.95mm_HandSolder
TP14, TP15, TP16, TP17, TP18, TP19, TP20, TP21, TP22, TP23, TP24, TP25: TestPoint; TestPoint_Pad_30x30mils
TP26: probe; TestPoint_2Pads_Pitch2.54mm_Drill0.8mm
U9, U17: CITIROC1A; QFP-160_26x26_Pitch0.65mm
U18, U23: SN74AXC2T45DCTR; SSOP-8_2.95x2.8mm_P0.65mm
U19, U20: NLSV8T244; TSSOP-20_4.4x6.5mm_P0.65mm
U21: DS90LV027A; SOIC-8_3.9x4.9mm_P1.27mm
U22: ADS7955; TSSOP-30_4.4x7.8mm_P0.5mm

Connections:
1.8V_CITIROC: C72.1, C73.1, C74.1, C88.1, C92.2, C105.1, R58.2, R59.2, R60.2, U18.1 (VCCA), U19.1 (VCCA), U20.1 (VCCA), U22.28 (+VBD), U23.1 (VCCA); also elsewhere on the board
1.8V_CITIROC_VHI: C36.1, U9.102 (vhl), U17.102 (vhl); also elsewhere on the board
3.3V_CITIROC: C23.1, C24.1, C27.1, C28.1, C29.1, C30.1, C31.1, C33.1, C34.1, C35.1, C103.1, C104.1, U9.12 (vdda_pa), U9.30 (vdda_pa), U9.43 (vdda_pa), U9.46 (vdd_dac), U9.54 (vdd_fs), U9.55 (vdd_sca), U9.137 (vdd_discri), U9.141 (vdd_ssh), U9.152 (vdd_pa), U9.153 (vdda_pa), U17.12 (vdda_pa), U17.30 (vdda_pa), U17.43 (vdda_pa), U17.46 (vdd_dac), U17.54 (vdd_fs), U17.55 (vdd_sca), U17.137 (vdd_discri), U17.141 (vdd_ssh), U17.152 (vdd_pa), U17.153 (vdda_pa); also elsewhere on the board
3.3V_DIGITAL: C25.1, C26.1, C32.1, C78.2, C81.2, C83.1, C84.1, C87.2, C91.2, C176.1, U9.68 (vndd), U9.123 (vddd), U9.142 (vdd_sc), U17.68 (vndd), U17.123 (vddd), U17.142 (vdd_sc), U18.8 (VCCB), U19.20 (VCCB), U20.20 (VCCB), U21.1 (VCC), U22.5 (+VA), U22.21 (+VA), U23.8 (VCCB); also elsewhere on the board
5V_DAC: C22.1, U9.158 (vdd_dac_5V), U17.158 (vdd_dac_5V); also elsewhere on the board
/CITIROC_1/ADC_SERIAL0: U22.23 (~CS); also elsewhere on the board
/CITIROC_1/ADC_SERIAL1: U22.24 (SCLK); also elsewhere on the board
/CITIROC_1/ADC_SERIAL2: U22.25 (SDI); also elsewhere on the board
/CITIROC_1/ADC_SERIAL3: U22.26 (SDO); also elsewhere on the board
/CITIROC_1/Fast_Trig2: U17.78 (OR32); also elsewhere on the board
/CITIROC_1/SH_Ctrl0: U18.2 (A1); also elsewhere on the board
/CITIROC_1/SH_Ctrl1: U18.3 (A2); also elsewhere on the board
/CITIROC_1/SH_Ctrl2: U19.2 (A1); also elsewhere on the board
/CITIROC_1/SH_Ctrl3: U19.3 (A2); also elsewhere on the board
/CITIROC_1/SH_Ctrl4: U19.4 (A3); also elsewhere on the board
/CITIROC_1/SH_Ctrl5: U19.5 (A4); also elsewhere on the board
/CITIROC_1/SH_Ctrl6: U19.6 (A5); also elsewhere on the board
/CITIROC_1/SH_Ctrl7: U19.7 (A6); also elsewhere on the board
/CITIROC_1/SH_Ctrl8: U19.8 (A7); also elsewhere on the board
/CITIROC_1/SH_Ctrl9: U19.9 (A8); also elsewhere on the board
/CITIROC_1/SIPM_IN0: R78.1, U17.4 (in0); also elsewhere on the board
/CITIROC_1/SIPM_IN1: R79.1, U17.5 (in1); also elsewhere on the board
/CITIROC_1/SIPM_IN2: R80.1, U17.6 (in2); also elsewhere on the board
/CITIROC_1/SIPM_IN3: R81.1, U17.7 (in3); also elsewhere on the board
/CITIROC_1/SIPM_IN4: R82.1, U17.8 (in4); also elsewhere on the board
/CITIROC_1/SIPM_IN5: R83.1, U17.9 (in5); also elsewhere on the board
/CITIROC_1/SIPM_IN6: R84.1, U17.10 (in6); also elsewhere on the board
/CITIROC_1/SIPM_IN7: R85.1, U17.11 (in7); also elsewhere on the board
/CITIROC_1/SIPM_IN8: R86.1, U17.13 (in8); also elsewhere on the board
/CITIROC_1/SIPM_IN9: R87.1, U17.14 (in9); also elsewhere on the board
/CITIROC_1/SIPM_IN10: R88.1, U17.15 (in10); also elsewhere on the board
/CITIROC_1/SIPM_IN11: R89.1, U17.16 (in11); also elsewhere on the board
/CITIROC_1/SIPM_IN12: R90.1, U17.17 (in12); also elsewhere on the board
/CITIROC_1/SIPM_IN13: R91.1, U17.18 (in13); also elsewhere on the board
/CITIROC_1/SIPM_IN14: R92.1, U17.19 (in14); also elsewhere on the board
/CITIROC_1/SIPM_IN15: R93.1, U17.20 (in15); also elsewhere on the board
/CITIROC_1/SIPM_IN16: R94.1, U17.22 (in16); also elsewhere on the board
/CITIROC_1/SIPM_IN17: R95.1, U17.23 (in17); also elsewhere on the board
/CITIROC_1/SIPM_IN18: R96.1, U17.24 (in18); also elsewhere on the board
/CITIROC_1/SIPM_IN19: R97.1, U17.25 (in19); also elsewhere on the board
/CITIROC_1/SIPM_IN20: R98.1, U17.26 (in20); also elsewhere on the board
/CITIROC_1/SIPM_IN21: R99.1, U17.27 (in21); also elsewhere on the board
/CITIROC_1/SIPM_IN22: R100.1, U17.28 (in22); also elsewhere on the board
/CITIROC_1/SIPM_IN23: R101.1, U17.29 (in23); also elsewhere on the board
/CITIROC_1/SIPM_IN24: R102.1, U17.31 (in24); also elsewhere on the board
/CITIROC_1/SIPM_IN25: R103.1, U17.32 (in25); also elsewhere on the board
/CITIROC_1/SIPM_IN26: R104.1, U17.33 (in26); also elsewhere on the board
/CITIROC_1/SIPM_IN27: R105.1, U17.34 (in27); also elsewhere on the board
/CITIROC_1/SIPM_IN28: R106.1, U17.35 (in28); also elsewhere on the board
/CITIROC_1/SIPM_IN29: R107.1, U17.36 (in29); also elsewhere on the board
/CITIROC_1/SIPM_IN30: R108.1, U17.37 (in30); also elsewhere on the board
/CITIROC_1/SIPM_IN31: R109.1, U17.38 (in31); also elsewhere on the board
/CITIROC_1/SIPM_TEMP: U22.11 (CH7)
/CITIROC_1/Serial_ctrl0: U20.2 (A1); also elsewhere on the board
/CITIROC_1/Serial_ctrl1: U20.3 (A2); also elsewhere on the board
/CITIROC_1/Serial_ctrl2: U20.4 (A3); also elsewhere on the board
/CITIROC_1/Serial_ctrl3: U20.5 (A4); also elsewhere on the board
/CITIROC_1/Serial_ctrl4: U20.6 (A5); also elsewhere on the board
/CITIROC_1/Serial_ctrl5: U20.7 (A6); also elsewhere on the board
/CITIROC_1/Serial_ctrl6: U20.8 (A7); also elsewhere on the board
/CITIROC_1/Serial_ctrl7: U23.2 (A1); also elsewhere on the board
/CITIROC_1/Serial_ctrl8: U23.3 (A2); also elsewhere on the board
/CITIROC_1/TRIG_OUT0: U17.118 (T<0>); also elsewhere on the board
/CITIROC_1/TRIG_OUT1: U17.117 (T<1>); also elsewhere on the board
/CITIROC_1/TRIG_OUT2: U17.116 (T<2>); also elsewhere on the board
/CITIROC_1/TRIG_OUT3: U17.115 (T<3>); also elsewhere on the board
/CITIROC_1/TRIG_OUT4: U17.114 (T<4>); also elsewhere on the board
/CITIROC_1/TRIG_OUT5: U17.113 (T<5>); also elsewhere on the board
/CITIROC_1/TRIG_OUT6: U17.112 (T<6>); also elsewhere on the board
/CITIROC_1/TRIG_OUT7: U17.111 (T<7>); also elsewhere on the board
/CITIROC_1/TRIG_OUT8: U17.110 (T<8>); also elsewhere on the board
/CITIROC_1/TRIG_OUT9: U17.109 (T<9>); also elsewhere on the board
/CITIROC_1/TRIG_OUT10: U17.108 (T<10>); also elsewhere on the board
/CITIROC_1/TRIG_OUT11: U17.107 (T<11>); also elsewhere on the board
/CITIROC_1/TRIG_OUT12: U17.106 (T<12>); also elsewhere on the board
/CITIROC_1/TRIG_OUT13: U17.105 (T<13>); also elsewhere on the board
/CITIROC_1/TRIG_OUT14: U17.104 (T<14>); also elsewhere on the board
/CITIROC_1/TRIG_OUT15: U17.103 (T<15>); also elsewhere on the board
/CITIROC_1/TRIG_OUT16: U17.99 (T<16>); also elsewhere on the board
/CITIROC_1/TRIG_OUT17: U17.98 (T<17>); also elsewhere on the board
/CITIROC_1/TRIG_OUT18: U17.97 (T<18>); also elsewhere on the board
/CITIROC_1/TRIG_OUT19: U17.96 (T<19>); also elsewhere on the board
/CITIROC_1/TRIG_OUT20: U17.95 (T<20>); also elsewhere on the board
/CITIROC_1/TRIG_OUT21: U17.94 (T<21>); also elsewhere on the board
/CITIROC_1/TRIG_OUT22: U17.93 (T<22>); also elsewhere on the board
/CITIROC_1/TRIG_OUT23: U17.92 (T<23>); also elsewhere on the board
/CITIROC_1/TRIG_OUT24: U17.91 (T<24>); also elsewhere on the board
/CITIROC_1/TRIG_OUT25: U17.90 (T<25>); also elsewhere on the board
/CITIROC_1/TRIG_OUT26: U17.89 (T<26>); also elsewhere on the board
/CITIROC_1/TRIG_OUT27: U17.88 (T<27>); also elsewhere on the board
/CITIROC_1/TRIG_OUT28: U17.87 (T<28>); also elsewhere on the board
/CITIROC_1/TRIG_OUT29: U17.86 (T<29>); also elsewhere on the board
/CITIROC_1/TRIG_OUT30: U17.85 (T<30>); also elsewhere on the board
/CITIROC_1/TRIG_OUT31: U17.84 (T<31>); also elsewhere on the board
/CITIROC_2/Fast_Trig2: U9.78 (OR32); also elsewhere on the board
/CITIROC_2/SIPM_IN0: U9.4 (in0); also elsewhere on the board
/CITIROC_2/SIPM_IN1: U9.5 (in1); also elsewhere on the board
/CITIROC_2/SIPM_IN2: U9.6 (in2); also elsewhere on the board
/CITIROC_2/SIPM_IN3: U9.7 (in3); also elsewhere on the board
/CITIROC_2/SIPM_IN4: U9.8 (in4); also elsewhere on the board
/CITIROC_2/SIPM_IN5: U9.9 (in5); also elsewhere on the board
/CITIROC_2/SIPM_IN6: U9.10 (in6); also elsewhere on the board
/CITIROC_2/SIPM_IN7: U9.11 (in7); also elsewhere on the board
/CITIROC_2/SIPM_IN8: U9.13 (in8); also elsewhere on the board
/CITIROC_2/SIPM_IN9: U9.14 (in9); also elsewhere on the board
/CITIROC_2/SIPM_IN10: U9.15 (in10); also elsewhere on the board
/CITIROC_2/SIPM_IN11: U9.16 (in11); also elsewhere on the board
/CITIROC_2/SIPM_IN12: U9.17 (in12); also elsewhere on the board
/CITIROC_2/SIPM_IN13: U9.18 (in13); also elsewhere on the board
/CITIROC_2/SIPM_IN14: U9.19 (in14); also elsewhere on the board
/CITIROC_2/SIPM_IN15: U9.20 (in15); also elsewhere on the board
/CITIROC_2/SIPM_IN16: U9.22 (in16); also elsewhere on the board
/CITIROC_2/SIPM_IN17: U9.23 (in17); also elsewhere on the board
/CITIROC_2/SIPM_IN18: U9.24 (in18); also elsewhere on the board
/CITIROC_2/SIPM_IN19: U9.25 (in19); also elsewhere on the board
/CITIROC_2/SIPM_IN20: U9.26 (in20); also elsewhere on the board
/CITIROC_2/SIPM_IN21: U9.27 (in21); also elsewhere on the board
/CITIROC_2/SIPM_IN22: U9.28 (in22); also elsewhere on the board
/CITIROC_2/SIPM_IN23: U9.29 (in23); also elsewhere on the board
/CITIROC_2/SIPM_IN24: U9.31 (in24); also elsewhere on the board
/CITIROC_2/SIPM_IN25: U9.32 (in25); also elsewhere on the board
/CITIROC_2/SIPM_IN26: U9.33 (in26); also elsewhere on the board
/CITIROC_2/SIPM_IN27: U9.34 (in27); also elsewhere on the board
/CITIROC_2/SIPM_IN28: U9.35 (in28); also elsewhere on the board
/CITIROC_2/SIPM_IN29: U9.36 (in29); also elsewhere on the board
/CITIROC_2/SIPM_IN30: U9.37 (in30); also elsewhere on the board
/CITIROC_2/SIPM_IN31: U9.38 (in31); also elsewhere on the board
/CITIROC_2/TRIG_OUT0: U9.118 (T<0>); also elsewhere on the board
/CITIROC_2/TRIG_OUT1: U9.117 (T<1>); also elsewhere on the board
/CITIROC_2/TRIG_OUT2: U9.116 (T<2>); also elsewhere on the board
/CITIROC_2/TRIG_OUT3: U9.115 (T<3>); also elsewhere on the board
/CITIROC_2/TRIG_OUT4: U9.114 (T<4>); also elsewhere on the board
/CITIROC_2/TRIG_OUT5: U9.113 (T<5>); also elsewhere on the board
/CITIROC_2/TRIG_OUT6: U9.112 (T<6>); also elsewhere on the board
/CITIROC_2/TRIG_OUT7: U9.111 (T<7>); also elsewhere on the board
/CITIROC_2/TRIG_OUT8: U9.110 (T<8>); also elsewhere on the board
/CITIROC_2/TRIG_OUT9: U9.109 (T<9>); also elsewhere on the board
/CITIROC_2/TRIG_OUT10: U9.108 (T<10>); also elsewhere on the board
/CITIROC_2/TRIG_OUT11: U9.107 (T<11>); also elsewhere on the board
/CITIROC_2/TRIG_OUT12: U9.106 (T<12>); also elsewhere on the board
/CITIROC_2/TRIG_OUT13: U9.105 (T<13>); also elsewhere on the board
/CITIROC_2/TRIG_OUT14: U9.104 (T<14>); also elsewhere on the board
/CITIROC_2/TRIG_OUT15: U9.103 (T<15>); also elsewhere on the board
/CITIROC_2/TRIG_OUT16: U9.99 (T<16>); also elsewhere on the board
/CITIROC_2/TRIG_OUT17: U9.98 (T<17>); also elsewhere on the board
/CITIROC_2/TRIG_OUT18: U9.97 (T<18>); also elsewhere on the board
/CITIROC_2/TRIG_OUT19: U9.96 (T<19>); also elsewhere on the board
/CITIROC_2/TRIG_OUT20: U9.95 (T<20>); also elsewhere on the board
/CITIROC_2/TRIG_OUT21: U9.94 (T<21>); also elsewhere on the board
/CITIROC_2/TRIG_OUT22: U9.93 (T<22>); also elsewhere on the board
/CITIROC_2/TRIG_OUT23: U9.92 (T<23>); also elsewhere on the board
/CITIROC_2/TRIG_OUT24: U9.91 (T<24>); also elsewhere on the board
/CITIROC_2/TRIG_OUT25: U9.90 (T<25>); also elsewhere on the board
/CITIROC_2/TRIG_OUT26: U9.89 (T<26>); also elsewhere on the board
/CITIROC_2/TRIG_OUT27: U9.88 (T<27>); also elsewhere on the board
/CITIROC_2/TRIG_OUT28: U9.87 (T<28>); also elsewhere on the board
/CITIROC_2/TRIG_OUT29: U9.86 (T<29>); also elsewhere on the board
/CITIROC_2/TRIG_OUT30: U9.85 (T<30>); also elsewhere on the board
/CITIROC_2/TRIG_OUT31: U9.84 (T<31>); also elsewhere on the board
ADC_VREF: C175.1, U22.4 (REFP); also elsewhere on the board
unnamed: C20.2, U9.157 (vref_dac_5V)
unnamed: C21.2, U9.2 (vref_iGen_dac_5V)
unnamed 249: U9.50 (vref_ssh_lg); also elsewhere on the board
unnamed 250: U9.52 (vref_ssh_hg); also elsewhere on the board
unnamed 251: U9.53 (vref_fs); also elsewhere on the board
unnamed 252: U9.49 (iref_dac); also elsewhere on the board
unnamed 253: U9.45 (v_bg); also elsewhere on the board
unnamed 265: U17.157 (vref_dac_5V); also elsewhere on the board
unnamed 266: U17.2 (vref_iGen_dac_5V); also elsewhere on the board
unnamed: C123.1, R78.2
unnamed: C124.1, R79.2
unnamed: C125.1, R80.2
unnamed: C126.1, R81.2
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

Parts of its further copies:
C17, C18, C19: 1uF; C_0603_1608Metric_Pad1.05x0.95mm_HandSolder
C37, C38, C39, C40, C41, C42, C43, C44, C45, C46, C47, C48, C49, C50, C51, C52, C53, C54, C55, C56, C57, C58, C59, C60, C61, C62, C63, C64, C65, C66, C67, C68: 0.1uF; C_0402_1005Metric
C69, C70, C71, C75, C76, C106, C107, C108, C109, C110, C111, C112, C113, C114, C115, C116, C117, C118, C119, C120, C121, C122, C158, C159, C160, C164, C167, C169, C170, C173, C174, C177, C178: 0.1uF; C_0603_1608Metric_Pad1.05x0.95mm_HandSolder
C77, C79, C80, C82, C85, C86: 150pF; C_0603_1608Metric_Pad1.05x0.95mm_HandSolder
C89, C90: 10uF; C_0805_2012Metric_Pad1.15x1.40mm_HandSolder
R17, R18, R19, R20, R21, R22, R23, R24, R25, R26, R27, R28, R29, R30, R31, R32, R33, R34, R35, R36, R37, R38, R39, R40, R41, R42, R43, R44, R45, R46, R47, R48: 49.9; R_0402_1005Metric
R49, R50, R51, R52, R53, R54, R55: 1k; R_0603_1608Metric_Pad1.05x0.95mm_HandSolder
R56, R57: 100; R_0603_1608Metric_Pad1.05x0.95mm_HandSolder
R119, R120, R121: 4.7k; R_1206_3216Metric_Pad1.42x1.75mm_HandSolder
TP1, TP2, TP3, TP4, TP5, TP6, TP7, TP8, TP9, TP10, TP11, TP12: TestPoint; TestPoint_Pad_30x30mils
TP13: probe; TestPoint_2Pads_Pitch2.54mm_Drill0.8mm
U10, U15: SN74AXC2T45DCTR; SSOP-8_2.95x2.8mm_P0.65mm
U11, U12: NLSV8T244; TSSOP-20_4.4x6.5mm_P0.65mm
U13: DS90LV027A; SOIC-8_3.9x4.9mm_P1.27mm
U14: ADS7955; TSSOP-30_4.4x7.8mm_P0.5mm

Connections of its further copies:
1.8V_CITIROC: C19.1, C158.1, C159.1, C160.1, C174.1, C178.2, R119.2, R120.2, R121.2, U10.1 (VCCA), U11.1 (VCCA), U12.1 (VCCA), U14.28 (+VBD), U15.1 (VCCA); also elsewhere on the board
1.8V_CITIROC_VHI: C122.1; also elsewhere on the board
3.3V_CITIROC: C17.1, C18.1, C109.1, C110.1, C113.1, C114.1, C115.1, C116.1, C117.1, C119.1, C120.1, C121.1; also elsewhere on the board
3.3V_DIGITAL: C90.1, C111.1, C112.1, C118.1, C164.2, C167.2, C169.1, C170.1, C173.2, C177.2, U10.8 (VCCB), U11.20 (VCCB), U12.20 (VCCB), U13.1 (VCC), U14.5 (+VA), U14.21 (+VA), U15.8 (VCCB); also elsewhere on the board
5V_DAC: C108.1; also elsewhere on the board
/Backplane/SIPM_TEMP: U14.11 (CH7); also elsewhere on the board
/CITIROC_2/ADC_SERIAL0: U14.23 (~CS); also elsewhere on the board
/CITIROC_2/ADC_SERIAL1: U14.24 (SCLK); also elsewhere on the board
/CITIROC_2/ADC_SERIAL2: U14.25 (SDI); also elsewhere on the board
/CITIROC_2/ADC_SERIAL3: U14.26 (SDO); also elsewhere on the board
/CITIROC_2/SH_Ctrl0: U10.2 (A1); also elsewhere on the board
/CITIROC_2/SH_Ctrl1: U10.3 (A2); also elsewhere on the board
/CITIROC_2/SH_Ctrl2: U11.2 (A1); also elsewhere on the board
/CITIROC_2/SH_Ctrl3: U11.3 (A2); also elsewhere on the board
/CITIROC_2/SH_Ctrl4: U11.4 (A3); also elsewhere on the board
/CITIROC_2/SH_Ctrl5: U11.5 (A4); also elsewhere on the board
/CITIROC_2/SH_Ctrl6: U11.6 (A5); also elsewhere on the board
/CITIROC_2/SH_Ctrl7: U11.7 (A6); also elsewhere on the board
/CITIROC_2/SH_Ctrl8: U11.8 (A7); also elsewhere on the board
/CITIROC_2/SH_Ctrl9: U11.9 (A8); also elsewhere on the board
/CITIROC_2/SIPM_IN0: R17.1; also elsewhere on the board
/CITIROC_2/SIPM_IN1: R18.1; also elsewhere on the board
/CITIROC_2/SIPM_IN2: R19.1; also elsewhere on the board
/CITIROC_2/SIPM_IN3: R20.1; also elsewhere on the board
/CITIROC_2/SIPM_IN4: R21.1; also elsewhere on the board
/CITIROC_2/SIPM_IN5: R22.1; also elsewhere on the board
/CITIROC_2/SIPM_IN6: R23.1; also elsewhere on the board
/CITIROC_2/SIPM_IN7: R24.1; also elsewhere on the board
/CITIROC_2/SIPM_IN8: R25.1; also elsewhere on the board
/CITIROC_2/SIPM_IN9: R26.1; also elsewhere on the board
/CITIROC_2/SIPM_IN10: R27.1; also elsewhere on the board
/CITIROC_2/SIPM_IN11: R28.1; also elsewhere on the board
/CITIROC_2/SIPM_IN12: R29.1; also elsewhere on the board
/CITIROC_2/SIPM_IN13: R30.1; also elsewhere on the board
/CITIROC_2/SIPM_IN14: R31.1; also elsewhere on the board
/CITIROC_2/SIPM_IN15: R32.1; also elsewhere on the board
/CITIROC_2/SIPM_IN16: R33.1; also elsewhere on the board
/CITIROC_2/SIPM_IN17: R34.1; also elsewhere on the board
/CITIROC_2/SIPM_IN18: R35.1; also elsewhere on the board
/CITIROC_2/SIPM_IN19: R36.1; also elsewhere on the board
/CITIROC_2/SIPM_IN20: R37.1; also elsewhere on the board
/CITIROC_2/SIPM_IN21: R38.1; also elsewhere on the board
/CITIROC_2/SIPM_IN22: R39.1; also elsewhere on the board
/CITIROC_2/SIPM_IN23: R40.1; also elsewhere on the board
/CITIROC_2/SIPM_IN24: R41.1; also elsewhere on the board
/CITIROC_2/SIPM_IN25: R42.1; also elsewhere on the board
/CITIROC_2/SIPM_IN26: R43.1; also elsewhere on the board
/CITIROC_2/SIPM_IN27: R44.1; also elsewhere on the board
/CITIROC_2/SIPM_IN28: R45.1; also elsewhere on the board
/CITIROC_2/SIPM_IN29: R46.1; also elsewhere on the board
/CITIROC_2/SIPM_IN30: R47.1; also elsewhere on the board
/CITIROC_2/SIPM_IN31: R48.1; also elsewhere on the board
/CITIROC_2/Serial_ctrl0: U12.2 (A1); also elsewhere on the board
/CITIROC_2/Serial_ctrl1: U12.3 (A2); also elsewhere on the board
/CITIROC_2/Serial_ctrl2: U12.4 (A3); also elsewhere on the board
/CITIROC_2/Serial_ctrl3: U12.5 (A4); also elsewhere on the board
/CITIROC_2/Serial_ctrl4: U12.6 (A5); also elsewhere on the board
/CITIROC_2/Serial_ctrl5: U12.7 (A6); also elsewhere on the board
/CITIROC_2/Serial_ctrl6: U12.8 (A7); also elsewhere on the board
/CITIROC_2/Serial_ctrl7: U15.2 (A1); also elsewhere on the board
/CITIROC_2/Serial_ctrl8: U15.3 (A2); also elsewhere on the board
ADC_VREF: C89.1, U14.4 (REFP); also elsewhere on the board
unnamed: C37.1, R17.2
unnamed: C38.1, R18.2
unnamed: C39.1, R19.2
unnamed: C40.1, R20.2
unnamed: C41.1, R21.2
unnamed: C42.1, R22.2
unnamed: C43.1, R23.2
unnamed: C44.1, R24.2
unnamed: C45.1, R25.2
unnamed: C46.1, R26.2
unnamed: C47.1, R27.2
unnamed: C48.1, R28.2
unnamed: C49.1, R29.2
unnamed: C50.1, R30.2
unnamed: C51.1, R31.2
unnamed: C52.1, R32.2
unnamed: C53.1, R33.2
unnamed: C54.1, R34.2
unnamed: C55.1, R35.2
unnamed: C56.1, R36.2
unnamed: C57.1, R37.2
unnamed: C58.1, R38.2
unnamed: C59.1, R39.2
unnamed: C60.1, R40.2
unnamed: C61.1, R41.2
unnamed: C62.1, R42.2
unnamed: C63.1, R43.2
unnamed: C64.1, R44.2
unnamed: C65.1, R45.2
unnamed: C66.1, R46.2
unnamed: C67.1, R47.2
unnamed: C68.1, R48.2
unnamed 249: C69.2; also elsewhere on the board
unnamed 250: C70.2; also elsewhere on the board
unnamed 251: C71.2; also elsewhere on the board
unnamed 252: C75.2, TP2.1; also elsewhere on the board
unnamed 253: C76.1, TP12.1; also elsewhere on the board
unnamed: C77.1, R54.1, R55.2, U14.12 (CH6)
unnamed: C79.1, R53.1, U14.13 (CH5)
unnamed: C80.1, R52.1, U14.14 (CH4)
unnamed: C82.1, R51.1, U14.17 (CH3)
unnamed: C85.1, R50.1, U14.18 (CH2)
unnamed: C86.1, R49.1, U14.19 (CH1)
unnamed 265: C106.2; also elsewhere on the board
unnamed 266: C107.2; also elsewhere on the board
unnamed 1045: R49.2; also elsewhere on the board
unnamed 1046: R50.2; also elsewhere on the board
unnamed 1047: R51.2; also elsewhere on the board
unnamed 1048: R52.2; also elsewhere on the board
unnamed 1049: R53.2; also elsewhere on the board
unnamed 1050: R54.2; also elsewhere on the board
unnamed 1051: R56.1, U13.7 (D0+1); also elsewhere on the board
unnamed 1052: R56.2, U13.8 (D0-1); also elsewhere on the board
unnamed 1053: R57.1, U13.6 (D0+2); also elsewhere on the board
unnamed 1054: R57.2, U13.5 (D0-2); also elsewhere on the board
unnamed 1067: TP1.1; also elsewhere on the board
unnamed 1068: TP3.1; also elsewhere on the board
unnamed 1069: TP4.1; also elsewhere on the board
unnamed 1070: TP5.1; also elsewhere on the board
unnamed 1071: TP6.1; also elsewhere on the board
unnamed 1072: TP7.1; also elsewhere on the board
unnamed 1073: TP8.1; also elsewhere on the board
unnamed 1074: TP9.1; also elsewhere on the board
unnamed 1075: TP10.1; also elsewhere on the board
unnamed 1076: TP11.1; also elsewhere on the board
unnamed 1077: TP13.1; also elsewhere on the board
unnamed: U10.6 (B2), U13.3 (DI2)
unnamed: U10.7 (B1), U13.2 (DI1)
unnamed 1099: U11.12 (B8); also elsewhere on the board
unnamed 1100: U11.13 (B7); also elsewhere on the board
unnamed 1101: U11.14 (B6); also elsewhere on the board
unnamed 1102: U11.15 (B5); also elsewhere on the board
unnamed 1103: U11.16 (B4); also elsewhere on the board
unnamed 1104: U11.17 (B3); also elsewhere on the board
unnamed 1105: U11.18 (B2); also elsewhere on the board
unnamed 1106: U11.19 (B1); also elsewhere on the board
unnamed 1109: U12.13 (B7); also elsewhere on the board
unnamed 1110: U12.14 (B6); also elsewhere on the board
unnamed 1111: U12.15 (B5); also elsewhere on the board
unnamed 1112: U12.16 (B4); also elsewhere on the board
unnamed 1113: U12.17 (B3); also elsewhere on the board
unnamed 1114: U12.18 (B2); also elsewhere on the board
unnamed 1115: U12.19 (B1); also elsewhere on the board
unnamed: U14.7 (MXO), U14.8 (AINP)
unnamed 1124: U15.6 (B2); also elsewhere on the board
unnamed 1125: U15.7 (B1); also elsewhere on the board

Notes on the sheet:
digital i/o supply
analog I/O supply
SPI to LVDS bank
p46
20Mhz max
SiPM anode inputs
1.8V logic from FPGA
1.8V --> 3.3V Level shifters
LVDS driver
1.8V logic to FPGA
3.3V --> 1.8V level shifters

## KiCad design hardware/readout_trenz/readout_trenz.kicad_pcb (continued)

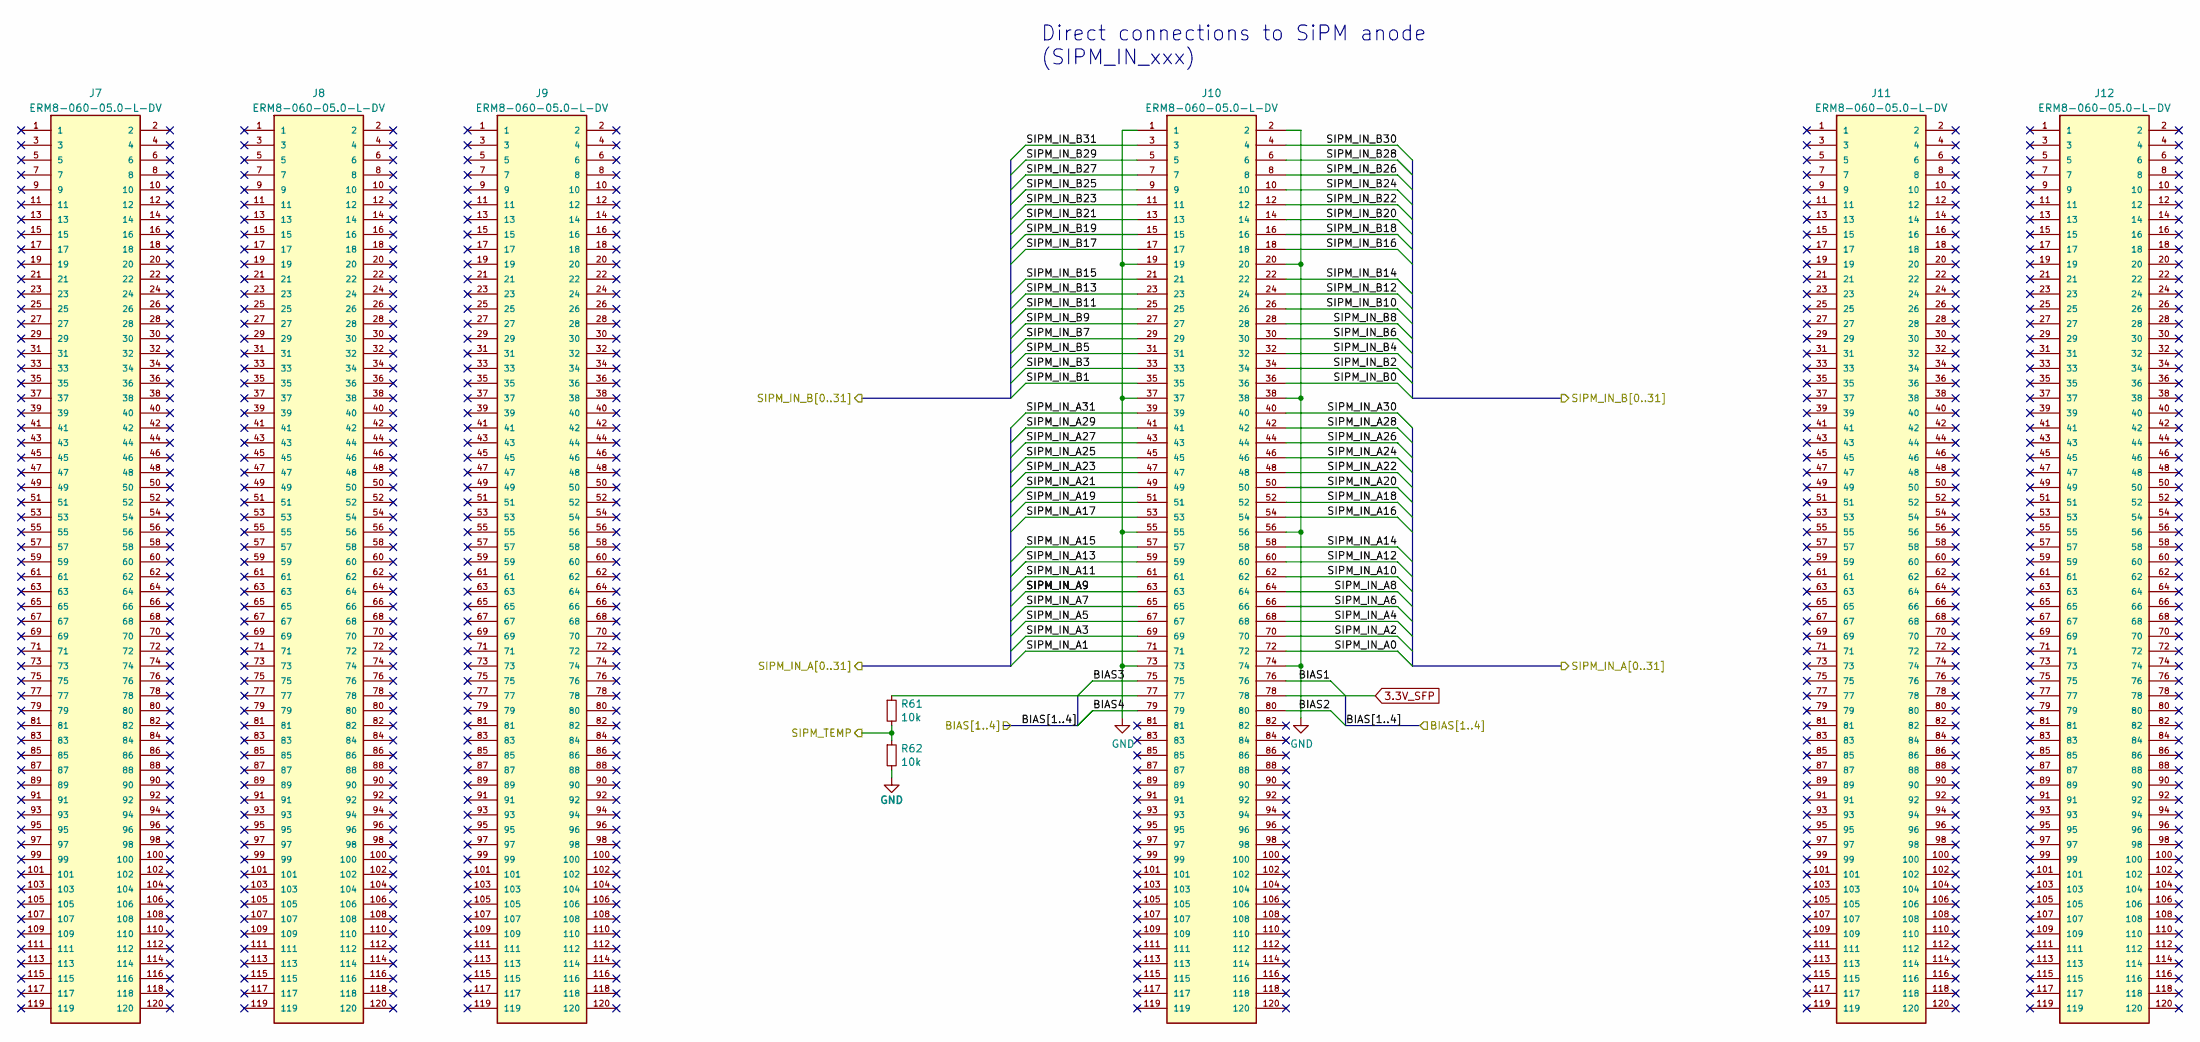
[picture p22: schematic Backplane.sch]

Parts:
J7, J8, J9, J10, J11, J12: ERM8-060-05.0-L-DV; ERM8-060-XX-X-D-RA
R61, R62: 10k; R_1206_3216Metric_Pad1.42x1.75mm_HandSolder

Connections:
3.3V_SFP: J10.78; also elsewhere on the board
/Backplane/BIAS1: J10.76; also elsewhere on the board
/Backplane/BIAS2: J10.80; also elsewhere on the board
/Backplane/BIAS3: J10.75; also elsewhere on the board
/Backplane/BIAS4: J10.79; also elsewhere on the board
/Backplane/SIPM_TEMP: R61.2, R62.1; also elsewhere on the board
/CITIROC_1/SIPM_IN0: J10.72; also elsewhere on the board
/CITIROC_1/SIPM_IN1: J10.71; also elsewhere on the board
/CITIROC_1/SIPM_IN2: J10.70; also elsewhere on the board
/CITIROC_1/SIPM_IN3: J10.69; also elsewhere on the board
/CITIROC_1/SIPM_IN4: J10.68; also elsewhere on the board
/CITIROC_1/SIPM_IN5: J10.67; also elsewhere on the board
/CITIROC_1/SIPM_IN6: J10.66; also elsewhere on the board
/CITIROC_1/SIPM_IN7: J10.65; also elsewhere on the board
/CITIROC_1/SIPM_IN8: J10.64; also elsewhere on the board
/CITIROC_1/SIPM_IN9: J10.63; also elsewhere on the board
/CITIROC_1/SIPM_IN10: J10.62; also elsewhere on the board
/CITIROC_1/SIPM_IN11: J10.61; also elsewhere on the board
/CITIROC_1/SIPM_IN12: J10.60; also elsewhere on the board
/CITIROC_1/SIPM_IN13: J10.59; also elsewhere on the board
/CITIROC_1/SIPM_IN14: J10.58; also elsewhere on the board
/CITIROC_1/SIPM_IN15: J10.57; also elsewhere on the board
/CITIROC_1/SIPM_IN16: J10.54; also elsewhere on the board
/CITIROC_1/SIPM_IN17: J10.53; also elsewhere on the board
/CITIROC_1/SIPM_IN18: J10.52; also elsewhere on the board
/CITIROC_1/SIPM_IN19: J10.51; also elsewhere on the board
/CITIROC_1/SIPM_IN20: J10.50; also elsewhere on the board
/CITIROC_1/SIPM_IN21: J10.49; also elsewhere on the board
/CITIROC_1/SIPM_IN22: J10.48; also elsewhere on the board
/CITIROC_1/SIPM_IN23: J10.47; also elsewhere on the board
/CITIROC_1/SIPM_IN24: J10.46; also elsewhere on the board
/CITIROC_1/SIPM_IN25: J10.45; also elsewhere on the board
/CITIROC_1/SIPM_IN26: J10.44; also elsewhere on the board
/CITIROC_1/SIPM_IN27: J10.43; also elsewhere on the board
/CITIROC_1/SIPM_IN28: J10.42; also elsewhere on the board
/CITIROC_1/SIPM_IN29: J10.41; also elsewhere on the board
/CITIROC_1/SIPM_IN30: J10.40; also elsewhere on the board
/CITIROC_1/SIPM_IN31: J10.39; also elsewhere on the board
/CITIROC_2/SIPM_IN0: J10.36; also elsewhere on the board
/CITIROC_2/SIPM_IN1: J10.35; also elsewhere on the board
/CITIROC_2/SIPM_IN2: J10.34; also elsewhere on the board
/CITIROC_2/SIPM_IN3: J10.33; also elsewhere on the board
/CITIROC_2/SIPM_IN4: J10.32; also elsewhere on the board
/CITIROC_2/SIPM_IN5: J10.31; also elsewhere on the board
/CITIROC_2/SIPM_IN6: J10.30; also elsewhere on the board
/CITIROC_2/SIPM_IN7: J10.29; also elsewhere on the board
/CITIROC_2/SIPM_IN8: J10.28; also elsewhere on the board
/CITIROC_2/SIPM_IN9: J10.27; also elsewhere on the board
/CITIROC_2/SIPM_IN10: J10.26; also elsewhere on the board
/CITIROC_2/SIPM_IN11: J10.25; also elsewhere on the board
/CITIROC_2/SIPM_IN12: J10.24; also elsewhere on the board
/CITIROC_2/SIPM_IN13: J10.23; also elsewhere on the board
/CITIROC_2/SIPM_IN14: J10.22; also elsewhere on the board
/CITIROC_2/SIPM_IN15: J10.21; also elsewhere on the board
/CITIROC_2/SIPM_IN16: J10.18; also elsewhere on the board
/CITIROC_2/SIPM_IN17: J10.17; also elsewhere on the board
/CITIROC_2/SIPM_IN18: J10.16; also elsewhere on the board
/CITIROC_2/SIPM_IN19: J10.15; also elsewhere on the board
/CITIROC_2/SIPM_IN20: J10.14; also elsewhere on the board
/CITIROC_2/SIPM_IN21: J10.13; also elsewhere on the board
/CITIROC_2/SIPM_IN22: J10.12; also elsewhere on the board
/CITIROC_2/SIPM_IN23: J10.11; also elsewhere on the board
/CITIROC_2/SIPM_IN24: J10.10; also elsewhere on the board
/CITIROC_2/SIPM_IN25: J10.9; also elsewhere on the board
/CITIROC_2/SIPM_IN26: J10.8; also elsewhere on the board
/CITIROC_2/SIPM_IN27: J10.7; also elsewhere on the board
/CITIROC_2/SIPM_IN28: J10.6; also elsewhere on the board
/CITIROC_2/SIPM_IN29: J10.5; also elsewhere on the board
/CITIROC_2/SIPM_IN30: J10.4; also elsewhere on the board
/CITIROC_2/SIPM_IN31: J10.3; also elsewhere on the board
unnamed: J10.77, R61.1

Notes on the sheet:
Direct connections to SiPM anode (SIPM_IN_xxx)

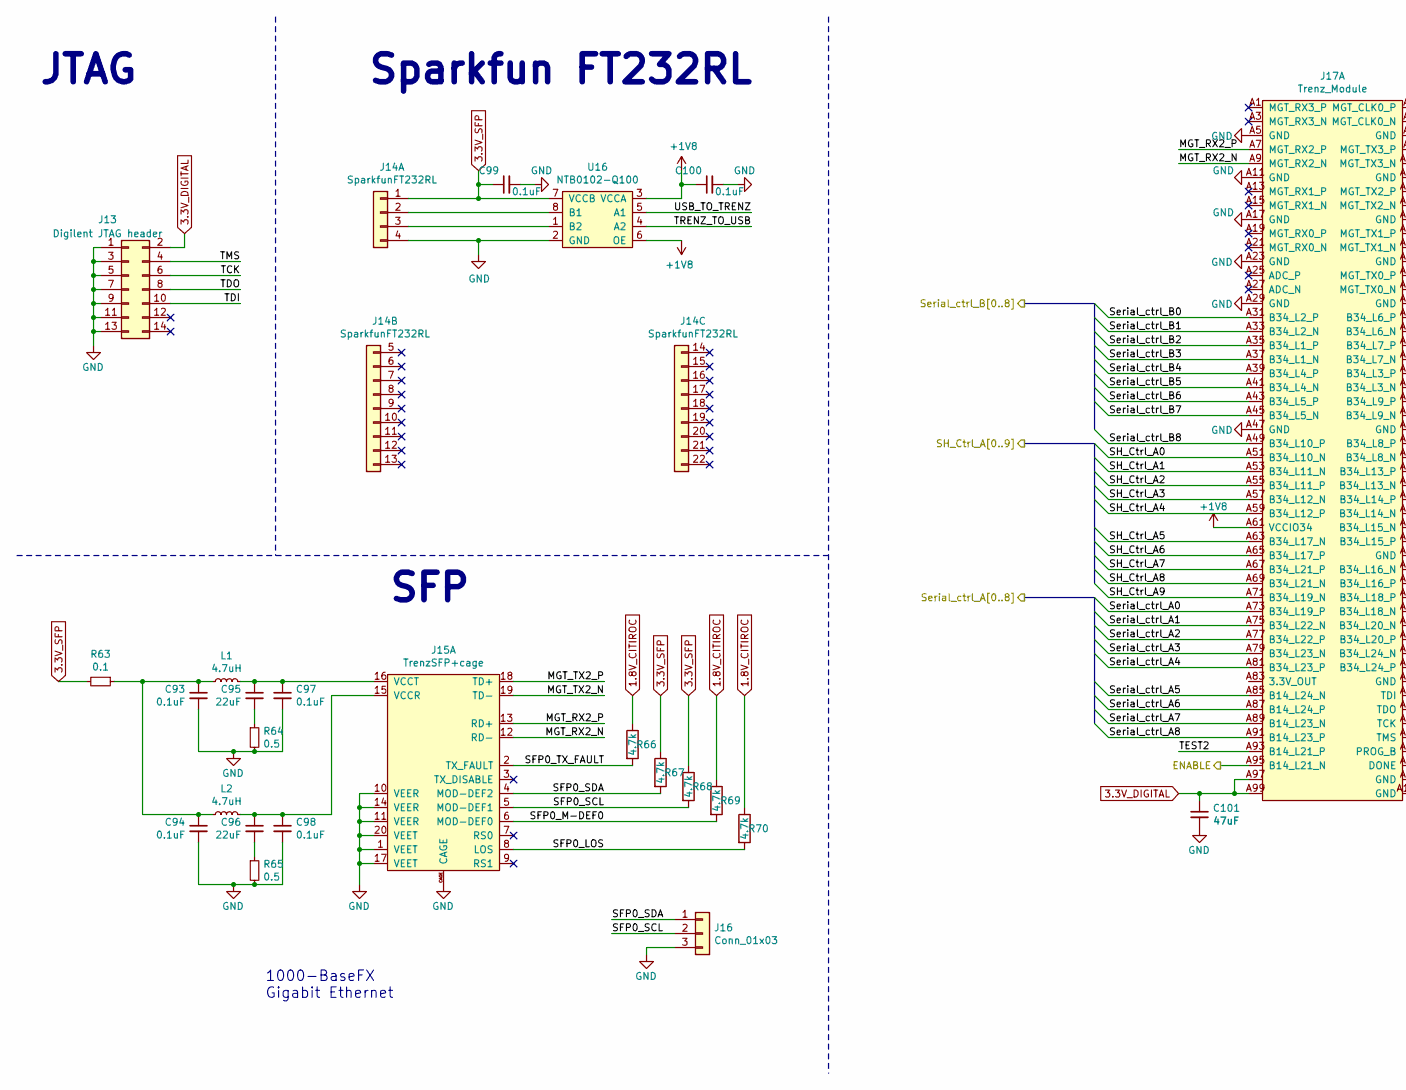
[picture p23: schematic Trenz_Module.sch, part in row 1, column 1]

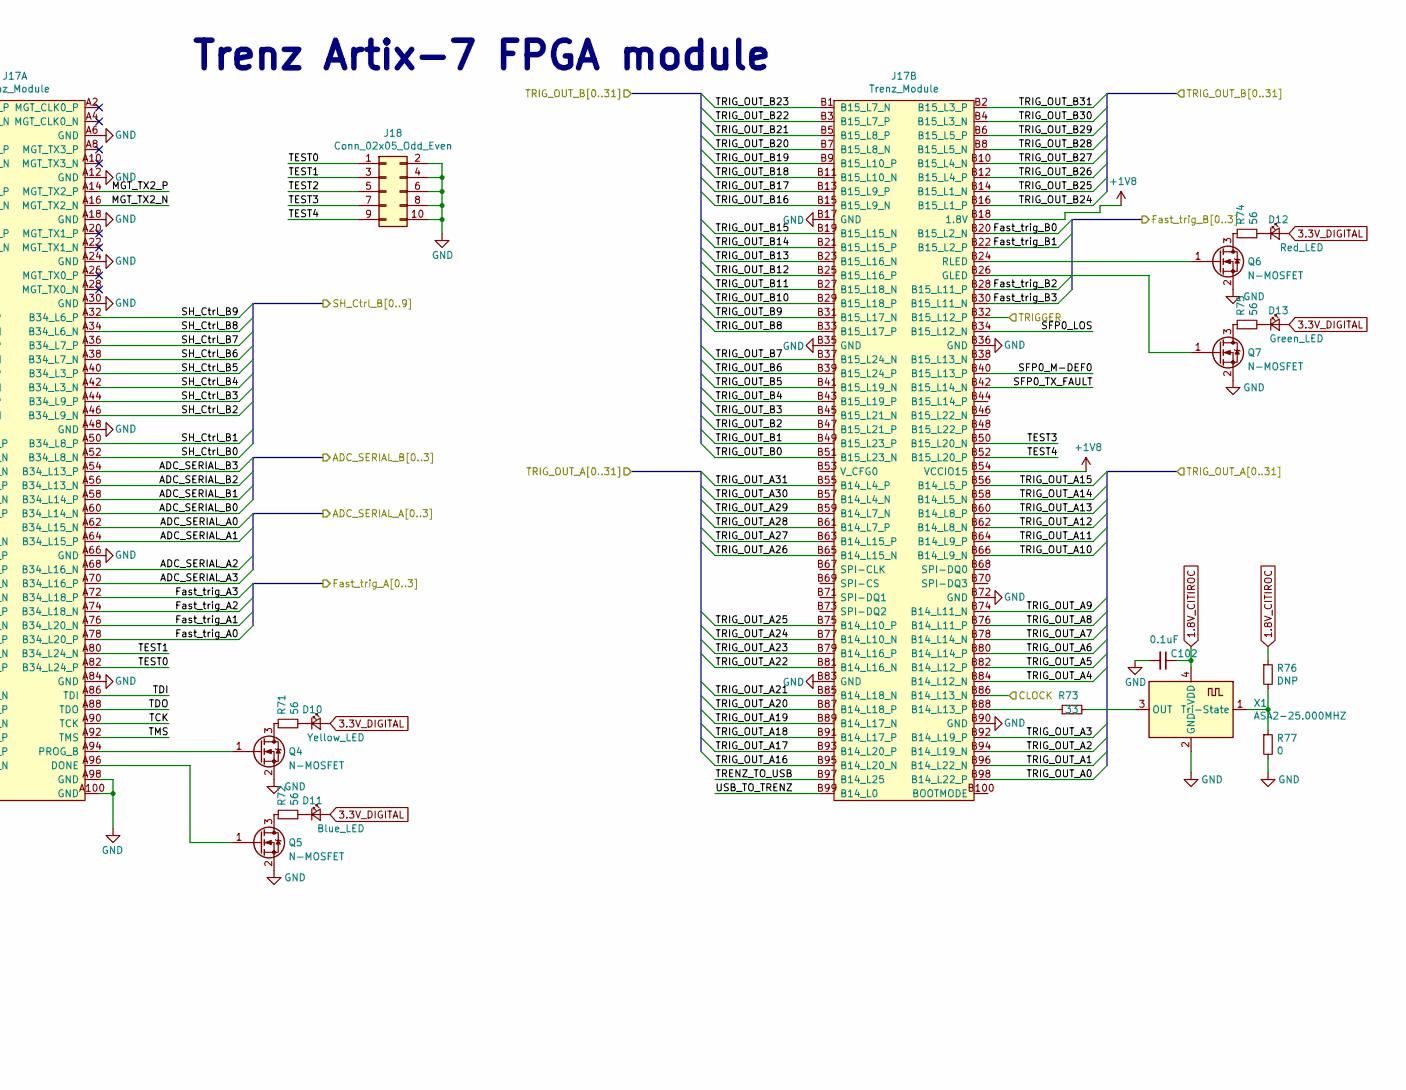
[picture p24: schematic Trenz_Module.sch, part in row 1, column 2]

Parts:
C93, C94, C97, C98, C99, C100, C102: 0.1uF; C_0603_1608Metric_Pad1.05x0.95mm_HandSolder
C95, C96: 22uF; C_0805_2012Metric_Pad1.15x1.40mm_HandSolder
C101: 47uF; C_0805_2012Metric_Pad1.15x1.40mm_HandSolder
D10: Yellow_LED; LED_D3.0mm
D11: Blue_LED; LED_D3.0mm
D12: Red_LED; LED_D3.0mm
D13: Green_LED; LED_D3.0mm
J13: Digilent JTAG header; 87832-1420
J14: SparkfunFT232RL; Sparkfun-FT232RL
J15: TrenzSFP+cage; Connector_SFP_and_Cage
J16: Conn_01x03; PinHeader_1x03_P2.54mm_Vertical
J17: Trenz_Module
J18: Conn_02x05_Odd_Even; 10129383-910002ALF
L1, L2: 4.7uH; A914BYW-4R7M=P3
Q4, Q5, Q6, Q7: N-MOSFET; SOT-416
R63: 0.1; R_0603_1608Metric_Pad1.05x0.95mm_HandSolder
R64, R65: 0.5; R_0603_1608Metric_Pad1.05x0.95mm_HandSolder
R66, R67, R68, R69, R70: 4.7k; R_1206_3216Metric_Pad1.42x1.75mm_HandSolder
R71, R72, R74, R75: 56; R_0603_1608Metric_Pad1.05x0.95mm_HandSolder
R73: 33; R_0603_1608Metric_Pad1.05x0.95mm_HandSolder
R76: DNP; R_0603_1608Metric_Pad1.05x0.95mm_HandSolder
R77: 0; R_0603_1608Metric_Pad1.05x0.95mm_HandSolder
U16: NTB0102-Q100; TSSOP-8_3x3mm_P0.65mm
X1: ASA2-25.000MHZ

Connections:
1.8V_CITIROC: C102.1, R66.1, R69.1, R70.1, R76.1, X1.4 (VDD); also elsewhere on the board
3.3V_DIGITAL: C101.1, D10.2 (A), D11.2 (A), D12.2 (A), D13.2 (A), J13.2, J17.A97, J17.A99; also elsewhere on the board
3.3V_SFP: C99.1, J14.1, R63.2, R67.1, R68.1, U16.7 (VCCB); also elsewhere on the board
+1V8: C100.1, J17.A61 (VCCIO34), J17.B18 (1.8V), J17.B54 (VCCIO15), U16.3 (VCCA), U16.6 (OE)
/CITIROC_1/ADC_SERIAL0: J17.A62 (B34_L15_N); also elsewhere on the board
/CITIROC_1/ADC_SERIAL1: J17.A64 (B34_L15_P); also elsewhere on the board
/CITIROC_1/ADC_SERIAL2: J17.A68 (B34_L16_N); also elsewhere on the board
/CITIROC_1/ADC_SERIAL3: J17.A70 (B34_L16_P); also elsewhere on the board
/CITIROC_1/Fast_Trig2: J17.A74 (B34_L18_N); also elsewhere on the board
/CITIROC_1/SH_Ctrl0: J17.A51 (B34_L10_N); also elsewhere on the board
/CITIROC_1/SH_Ctrl1: J17.A53 (B34_L11_N); also elsewhere on the board
/CITIROC_1/SH_Ctrl2: J17.A55 (B34_L11_P); also elsewhere on the board
/CITIROC_1/SH_Ctrl3: J17.A57 (B34_L12_N); also elsewhere on the board
/CITIROC_1/SH_Ctrl4: J17.A59 (B34_L12_P); also elsewhere on the board
/CITIROC_1/SH_Ctrl5: J17.A63 (B34_L17_N); also elsewhere on the board
/CITIROC_1/SH_Ctrl6: J17.A65 (B34_L17_P); also elsewhere on the board
/CITIROC_1/SH_Ctrl7: J17.A67 (B34_L21_P); also elsewhere on the board
/CITIROC_1/SH_Ctrl8: J17.A69 (B34_L21_N); also elsewhere on the board
/CITIROC_1/SH_Ctrl9: J17.A71 (B34_L19_N); also elsewhere on the board
/CITIROC_1/Serial_ctrl0: J17.A73 (B34_L19_P); also elsewhere on the board
/CITIROC_1/Serial_ctrl1: J17.A75 (B34_L22_N); also elsewhere on the board
/CITIROC_1/Serial_ctrl2: J17.A77 (B34_L22_P); also elsewhere on the board
/CITIROC_1/Serial_ctrl3: J17.A79 (B34_L23_N); also elsewhere on the board
/CITIROC_1/Serial_ctrl4: J17.A81 (B34_L23_P); also elsewhere on the board
/CITIROC_1/Serial_ctrl5: J17.A85 (B14_L24_N); also elsewhere on the board
/CITIROC_1/Serial_ctrl6: J17.A87 (B14_L24_P); also elsewhere on the board
/CITIROC_1/Serial_ctrl7: J17.A89 (B14_L23_N); also elsewhere on the board
/CITIROC_1/Serial_ctrl8: J17.A91 (B14_L23_P); also elsewhere on the board
/CITIROC_1/TRIG_OUT0: J17.B98 (B14_L22_P); also elsewhere on the board
/CITIROC_1/TRIG_OUT1: J17.B96 (B14_L22_N); also elsewhere on the board
/CITIROC_1/TRIG_OUT2: J17.B94 (B14_L19_N); also elsewhere on the board
/CITIROC_1/TRIG_OUT3: J17.B92 (B14_L19_P); also elsewhere on the board
/CITIROC_1/TRIG_OUT4: J17.B84 (B14_L12_N); also elsewhere on the board
/CITIROC_1/TRIG_OUT5: J17.B82 (B14_L12_P); also elsewhere on the board
/CITIROC_1/TRIG_OUT6: J17.B80 (B14_L14_P); also elsewhere on the board
/CITIROC_1/TRIG_OUT7: J17.B78 (B14_L14_N); also elsewhere on the board
/CITIROC_1/TRIG_OUT8: J17.B76 (B14_L11_P); also elsewhere on the board
/CITIROC_1/TRIG_OUT9: J17.B74 (B14_L11_N); also elsewhere on the board
/CITIROC_1/TRIG_OUT10: J17.B66 (B14_L9_N); also elsewhere on the board
/CITIROC_1/TRIG_OUT11: J17.B64 (B14_L9_P); also elsewhere on the board
/CITIROC_1/TRIG_OUT12: J17.B62 (B14_L8_N); also elsewhere on the board
/CITIROC_1/TRIG_OUT13: J17.B60 (B14_L8_P); also elsewhere on the board
/CITIROC_1/TRIG_OUT14: J17.B58 (B14_L5_N); also elsewhere on the board
/CITIROC_1/TRIG_OUT15: J17.B56 (B14_L5_P); also elsewhere on the board
/CITIROC_1/TRIG_OUT16: J17.B95 (B14_L20_N); also elsewhere on the board
/CITIROC_1/TRIG_OUT17: J17.B93 (B14_L20_P); also elsewhere on the board
/CITIROC_1/TRIG_OUT18: J17.B91 (B14_L17_P); also elsewhere on the board
/CITIROC_1/TRIG_OUT19: J17.B89 (B14_L17_N); also elsewhere on the board
/CITIROC_1/TRIG_OUT20: J17.B87 (B14_L18_P); also elsewhere on the board
/CITIROC_1/TRIG_OUT21: J17.B85 (B14_L18_N); also elsewhere on the board
/CITIROC_1/TRIG_OUT22: J17.B81 (B14_L16_N); also elsewhere on the board
/CITIROC_1/TRIG_OUT23: J17.B79 (B14_L16_P); also elsewhere on the board
/CITIROC_1/TRIG_OUT24: J17.B77 (B14_L10_N); also elsewhere on the board
/CITIROC_1/TRIG_OUT25: J17.B75 (B14_L10_P); also elsewhere on the board
/CITIROC_1/TRIG_OUT26: J17.B65 (B14_L15_N); also elsewhere on the board
/CITIROC_1/TRIG_OUT27: J17.B63 (B14_L15_P); also elsewhere on the board
/CITIROC_1/TRIG_OUT28: J17.B61 (B14_L7_P); also elsewhere on the board
/CITIROC_1/TRIG_OUT29: J17.B59 (B14_L7_N); also elsewhere on the board
/CITIROC_1/TRIG_OUT30: J17.B57 (B14_L4_N); also elsewhere on the board
/CITIROC_1/TRIG_OUT31: J17.B55 (B14_L4_P); also elsewhere on the board
/CITIROC_2/ADC_SERIAL0: J17.A60 (B34_L14_N); also elsewhere on the board
/CITIROC_2/ADC_SERIAL1: J17.A58 (B34_L14_P); also elsewhere on the board
/CITIROC_2/ADC_SERIAL2: J17.A56 (B34_L13_N); also elsewhere on the board
/CITIROC_2/ADC_SERIAL3: J17.A54 (B34_L13_P); also elsewhere on the board
/CITIROC_2/Fast_Trig2: J17.B28 (B15_L11_P); also elsewhere on the board
/CITIROC_2/SH_Ctrl0: J17.A52 (B34_L8_N); also elsewhere on the board
/CITIROC_2/SH_Ctrl1: J17.A50 (B34_L8_P); also elsewhere on the board
/CITIROC_2/SH_Ctrl2: J17.A46 (B34_L9_N); also elsewhere on the board
/CITIROC_2/SH_Ctrl3: J17.A44 (B34_L9_P); also elsewhere on the board
/CITIROC_2/SH_Ctrl4: J17.A42 (B34_L3_N); also elsewhere on the board
/CITIROC_2/SH_Ctrl5: J17.A40 (B34_L3_P); also elsewhere on the board
/CITIROC_2/SH_Ctrl6: J17.A38 (B34_L7_N); also elsewhere on the board
/CITIROC_2/SH_Ctrl7: J17.A36 (B34_L7_P); also elsewhere on the board
/CITIROC_2/SH_Ctrl8: J17.A34 (B34_L6_N); also elsewhere on the board
/CITIROC_2/SH_Ctrl9: J17.A32 (B34_L6_P); also elsewhere on the board
/CITIROC_2/Serial_ctrl0: J17.A31 (B34_L2_P); also elsewhere on the board
/CITIROC_2/Serial_ctrl1: J17.A33 (B34_L2_N); also elsewhere on the board
/CITIROC_2/Serial_ctrl2: J17.A35 (B34_L1_P); also elsewhere on the board
/CITIROC_2/Serial_ctrl3: J17.A37 (B34_L1_N); also elsewhere on the board
/CITIROC_2/Serial_ctrl4: J17.A39 (B34_L4_P); also elsewhere on the board
/CITIROC_2/Serial_ctrl5: J17.A41 (B34_L4_N); also elsewhere on the board
/CITIROC_2/Serial_ctrl6: J17.A43 (B34_L5_P); also elsewhere on the board
/CITIROC_2/Serial_ctrl7: J17.A45 (B34_L5_N); also elsewhere on the board
/CITIROC_2/Serial_ctrl8: J17.A49 (B34_L10_P); also elsewhere on the board
/CITIROC_2/TRIG_OUT0: J17.B51 (B15_L23_N); also elsewhere on the board
/CITIROC_2/TRIG_OUT1: J17.B49 (B15_L23_P); also elsewhere on the board
/CITIROC_2/TRIG_OUT2: J17.B47 (B15_L21_P); also elsewhere on the board
/CITIROC_2/TRIG_OUT3: J17.B45 (B15_L21_N); also elsewhere on the board
/CITIROC_2/TRIG_OUT4: J17.B43 (B15_L19_P); also elsewhere on the board
/CITIROC_2/TRIG_OUT5: J17.B41 (B15_L19_N); also elsewhere on the board
/CITIROC_2/TRIG_OUT6: J17.B39 (B15_L24_P); also elsewhere on the board
/CITIROC_2/TRIG_OUT7: J17.B37 (B15_L24_N); also elsewhere on the board
/CITIROC_2/TRIG_OUT8: J17.B33 (B15_L17_P); also elsewhere on the board
/CITIROC_2/TRIG_OUT9: J17.B31 (B15_L17_N); also elsewhere on the board
/CITIROC_2/TRIG_OUT10: J17.B29 (B15_L18_P); also elsewhere on the board
/CITIROC_2/TRIG_OUT11: J17.B27 (B15_L18_N); also elsewhere on the board
/CITIROC_2/TRIG_OUT12: J17.B25 (B15_L16_P); also elsewhere on the board
/CITIROC_2/TRIG_OUT13: J17.B23 (B15_L16_N); also elsewhere on the board
/CITIROC_2/TRIG_OUT14: J17.B21 (B15_L15_P); also elsewhere on the board
/CITIROC_2/TRIG_OUT15: J17.B19 (B15_L15_N); also elsewhere on the board
/CITIROC_2/TRIG_OUT16: J17.B15 (B15_L9_N); also elsewhere on the board
/CITIROC_2/TRIG_OUT17: J17.B13 (B15_L9_P); also elsewhere on the board
/CITIROC_2/TRIG_OUT18: J17.B11 (B15_L10_N); also elsewhere on the board
/CITIROC_2/TRIG_OUT19: J17.B9 (B15_L10_P); also elsewhere on the board
/CITIROC_2/TRIG_OUT20: J17.B7 (B15_L8_N); also elsewhere on the board
/CITIROC_2/TRIG_OUT21: J17.B5 (B15_L8_P); also elsewhere on the board
/CITIROC_2/TRIG_OUT22: J17.B3 (B15_L7_P); also elsewhere on the board
/CITIROC_2/TRIG_OUT23: J17.B1 (B15_L7_N); also elsewhere on the board
/CITIROC_2/TRIG_OUT24: J17.B16 (B15_L1_P); also elsewhere on the board
/CITIROC_2/TRIG_OUT25: J17.B14 (B15_L1_N); also elsewhere on the board
/CITIROC_2/TRIG_OUT26: J17.B12 (B15_L4_P); also elsewhere on the board
/CITIROC_2/TRIG_OUT27: J17.B10 (B15_L4_N); also elsewhere on the board
/CITIROC_2/TRIG_OUT28: J17.B8 (B15_L5_N); also elsewhere on the board
/CITIROC_2/TRIG_OUT29: J17.B6 (B15_L5_P); also elsewhere on the board
/CITIROC_2/TRIG_OUT30: J17.B4 (B15_L3_N); also elsewhere on the board
/CITIROC_2/TRIG_OUT31: J17.B2 (B15_L3_P); also elsewhere on the board
/CLK_TRIG/CLOCK: J17.B86 (B14_L13_N); also elsewhere on the board
/CLK_TRIG/TRIGGER: J17.B32 (B15_L12_P); also elsewhere on the board
/POWER/ENABLE: J17.A95 (B14_L21_N); also elsewhere on the board
/Trenz_Module/MGT_RX2_N: J15.12 (RD-), J17.A9 (MGT_RX2_N)
/Trenz_Module/MGT_RX2_P: J15.13 (RD+), J17.A7 (MGT_RX2_P)
/Trenz_Module/MGT_TX2_N: J15.19 (TD-), J17.A16 (MGT_TX2_N)
/Trenz_Module/MGT_TX2_P: J15.18 (TD+), J17.A14 (MGT_TX2_P)
/Trenz_Module/SFP0_LOS: J15.8 (LOS), J17.B34 (B15_L12_N), R70.2
/Trenz_Module/SFP0_M-DEF0: J15.6 (MOD-DEF0), J17.B40 (B15_L13_P), R69.2
/Trenz_Module/SFP0_SCL: J15.5 (MOD-DEF1), J16.2, R68.2
/Trenz_Module/SFP0_SDA: J15.4 (MOD-DEF2), J16.1, R67.2
/Trenz_Module/SFP0_TX_FAULT: J15.2 (TX_FAULT), J17.B42 (B15_L14_N), R66.2
/Trenz_Module/TCK: J13.6, J17.A90 (TCK)
/Trenz_Module/TDI: J13.10, J17.A86 (TDI)
/Trenz_Module/TDO: J13.8, J17.A88 (TDO)
/Trenz_Module/TEST0: J17.A82 (B34_L24_P), J18.1
/Trenz_Module/TEST1: J17.A80 (B34_L24_N), J18.3
/Trenz_Module/TEST2: J17.A93 (B14_L21_P), J18.5
/Trenz_Module/TEST3: J17.B50 (B15_L20_N), J18.7
/Trenz_Module/TEST4: J17.B52 (B15_L20_P), J18.9
/Trenz_Module/TMS: J13.4, J17.A92 (TMS)
/Trenz_Module/TRENZ_TO_USB: J17.B97 (B14_L25), U16.4 (A2)
/Trenz_Module/USB_TO_TRENZ: J17.B99 (B14_L0), U16.5 (A1)
unnamed: C93.1, C94.1, L1.1, L2.1, R63.1
unnamed: C95.1, C97.1, J15.16 (VCCT), L1.2
unnamed: C95.2, R64.1
unnamed: C96.1, C98.1, J15.15 (VCCR), L2.2
unnamed: C96.2, R65.1
unnamed: D10.1 (K), R71.2
unnamed: D11.1 (K), R72.2
unnamed: D12.1 (K), R74.2
unnamed: D13.1 (K), R75.2
unnamed: J14.2, U16.8 (B1)
unnamed: J14.3, U16.1 (B2)
unnamed: J17.A94 (PROG_B), Q4.1 (G)
unnamed: J17.A96 (DONE), Q5.1 (G)
unnamed: J17.B24 (RLED), Q6.1 (G)
unnamed: J17.B26 (GLED), Q7.1 (G)
unnamed: J17.B88 (B14_L13_P), R73.1
unnamed: Q4.3 (D), R71.1
unnamed: Q5.3 (D), R72.1
unnamed: Q6.3 (D), R74.1
unnamed: Q7.3 (D), R75.1
unnamed: R73.2, X1.3 (OUT)
unnamed: R76.2, R77.1, X1.1 (Tri-State)

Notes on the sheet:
JTAG
SFP
Trenz Artix-7 FPGA module
1000-BaseFX Gigabit Ethernet
Sparkfun FT232RL

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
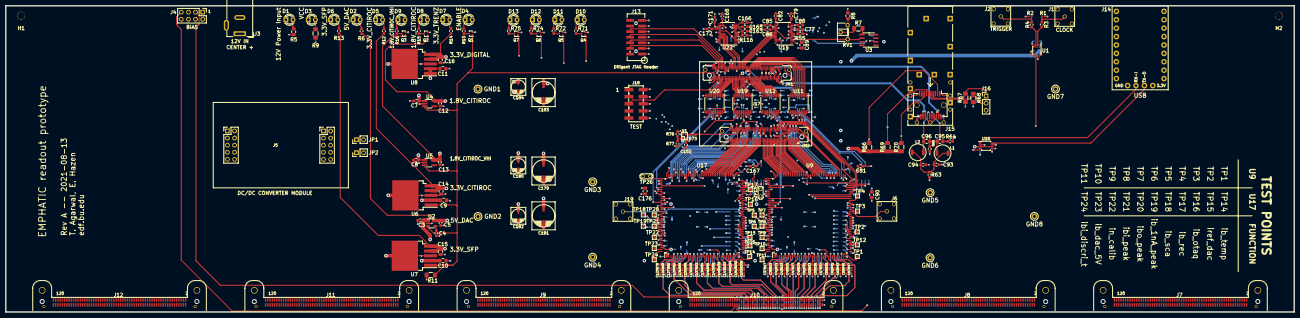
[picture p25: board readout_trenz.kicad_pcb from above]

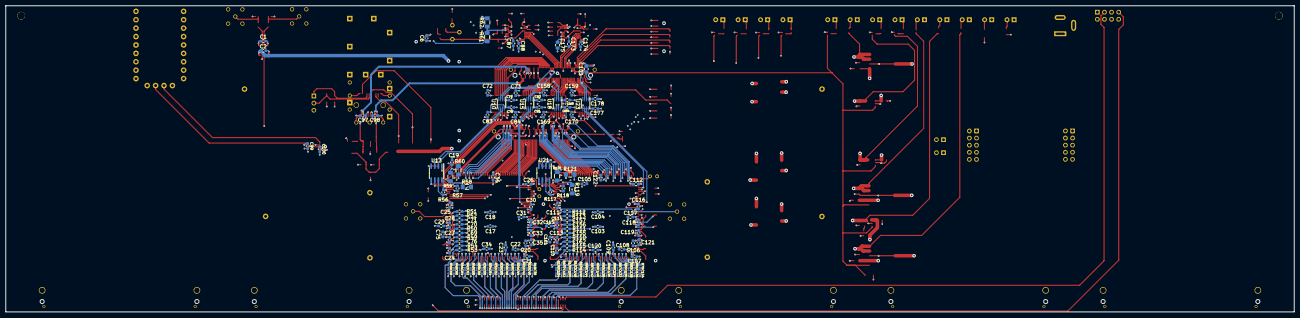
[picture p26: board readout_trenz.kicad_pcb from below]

Board: 6 copper layers, 460.0 x 109.3 mm, 409 parts (173 on the bottom side), 440 nets.

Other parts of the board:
J6: BNC; lemo-EPB.00.250.NTN

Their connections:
unnamed 331: J6.1; also elsewhere on the board

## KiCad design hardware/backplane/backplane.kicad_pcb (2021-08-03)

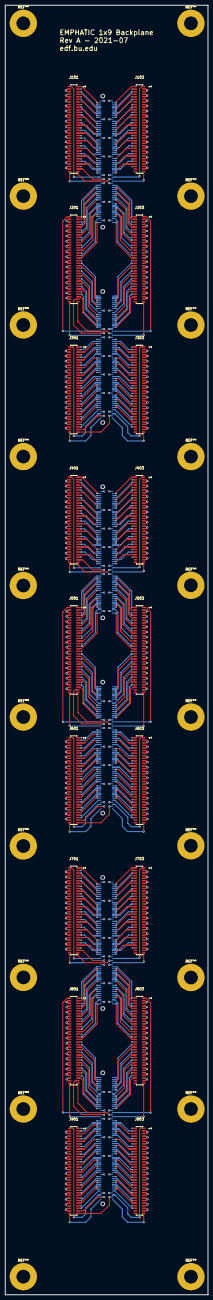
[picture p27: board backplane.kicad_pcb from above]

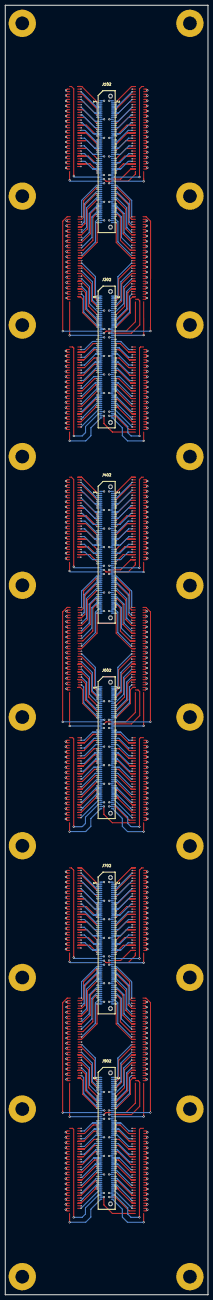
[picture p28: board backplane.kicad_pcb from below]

Board: 4 copper layers, 78.6 x 500.0 mm, 24 parts (6 on the bottom side), 619 nets.

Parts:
J101, J103, J401, J403, J701, J703: Conn_02x34_Odd_Even; SAMTEC_CLM-134-02-F-D
J102, J302, J402, J602, J702, J902: ERF8-060-05.0-L-DV
J201, J203, J301, J303, J501, J503, J601, J603, J801, J803, J901, J903: Conn_02x34_Odd_Even-Connector_Generic; SAMTEC_CLM-134-02-F-D

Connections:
/SiPM_Connector(1-3)/BCH0: J102.3, J103.2
/SiPM_Connector(1-3)/BCH1: J102.5, J103.4
/SiPM_Connector(1-3)/BCH2: J102.7, J103.6
/SiPM_Connector(1-3)/BCH3: J102.9, J103.8
/SiPM_Connector(1-3)/BCH4: J102.11, J103.10
/SiPM_Connector(1-3)/BCH5: J102.13, J103.12
/SiPM_Connector(1-3)/BCH6: J102.15, J103.14
/SiPM_Connector(1-3)/BCH7: J102.17, J103.16
/SiPM_Connector(1-3)/BCH8: J102.21, J103.18
/SiPM_Connector(1-3)/BCH9: J102.23, J103.20
/SiPM_Connector(1-3)/BCH10: J102.25, J103.22
/SiPM_Connector(1-3)/BCH11: J102.27, J103.24
/SiPM_Connector(1-3)/BCH12: J102.29, J103.26
/SiPM_Connector(1-3)/BCH13: J102.31, J103.28
/SiPM_Connector(1-3)/BCH14: J102.33, J103.30
/SiPM_Connector(1-3)/BCH15: J102.35, J103.32
/SiPM_Connector(1-3)/BCH16: J102.39, J103.34
/SiPM_Connector(1-3)/BCH17: J102.41, J103.36
/SiPM_Connector(1-3)/BCH18: J102.43, J103.38
/SiPM_Connector(1-3)/BCH19: J102.45, J103.40
/SiPM_Connector(1-3)/BCH20: J102.47, J103.42
/SiPM_Connector(1-3)/BCH21: J102.49, J103.44
/SiPM_Connector(1-3)/BCH22: J102.51, J103.46
/SiPM_Connector(1-3)/BCH23: J102.53, J103.48
/SiPM_Connector(1-3)/BCH24: J102.57, J103.50
/SiPM_Connector(1-3)/BCH25: J102.59, J103.52
/SiPM_Connector(1-3)/BCH26: J102.61, J103.54
/SiPM_Connector(1-3)/BCH27: J102.63, J103.56
/SiPM_Connector(1-3)/BCH28: J102.65, J103.58
/SiPM_Connector(1-3)/BCH29: J102.67, J103.60
/SiPM_Connector(1-3)/BCH30: J102.69, J103.62
/SiPM_Connector(1-3)/BCH31: J102.71, J103.64
/SiPM_Connector(1-3)/BCH32: J102.83, J203.2
/SiPM_Connector(1-3)/BCH33: J102.85, J203.4
/SiPM_Connector(1-3)/BCH34: J102.87, J203.6
/SiPM_Connector(1-3)/BCH35: J102.89, J203.8
/SiPM_Connector(1-3)/BCH36: J102.91, J203.10
/SiPM_Connector(1-3)/BCH37: J102.93, J203.12
/SiPM_Connector(1-3)/BCH38: J102.95, J203.14
/SiPM_Connector(1-3)/BCH39: J102.97, J203.16
/SiPM_Connector(1-3)/BCH40: J102.101, J203.18
/SiPM_Connector(1-3)/BCH41: J102.103, J203.20
/SiPM_Connector(1-3)/BCH42: J102.105, J203.22
/SiPM_Connector(1-3)/BCH43: J102.107, J203.24
/SiPM_Connector(1-3)/BCH44: J102.109, J203.26
/SiPM_Connector(1-3)/BCH45: J102.111, J203.28
/SiPM_Connector(1-3)/BCH46: J102.113, J203.30
/SiPM_Connector(1-3)/BCH47: J102.115, J203.32
/SiPM_Connector(1-3)/BCH48: J102.119, J203.34
/SiPM_Connector(1-3)/BCH49: J203.36, J302.1
/SiPM_Connector(1-3)/BCH50: J203.38, J302.3
/SiPM_Connector(1-3)/BCH51: J203.40, J302.5
/SiPM_Connector(1-3)/BCH52: J203.42, J302.7
/SiPM_Connector(1-3)/BCH53: J203.44, J302.9
/SiPM_Connector(1-3)/BCH54: J203.46, J302.11
/SiPM_Connector(1-3)/BCH55: J203.48, J302.13
/SiPM_Connector(1-3)/BCH56: J203.50, J302.17
/SiPM_Connector(1-3)/BCH57: J203.52, J302.19
/SiPM_Connector(1-3)/BCH58: J203.54, J302.21
/SiPM_Connector(1-3)/BCH59: J203.56, J302.23
/SiPM_Connector(1-3)/BCH60: J203.58, J302.25
/SiPM_Connector(1-3)/BCH61: J203.60, J302.27
/SiPM_Connector(1-3)/BCH62: J203.62, J302.29
/SiPM_Connector(1-3)/BCH63: J203.64, J302.31
/SiPM_Connector(1-3)/BCH64: J302.43, J303.2
/SiPM_Connector(1-3)/BCH65: J302.45, J303.4
/SiPM_Connector(1-3)/BCH66: J302.47, J303.6
/SiPM_Connector(1-3)/BCH67: J302.49, J303.8
/SiPM_Connector(1-3)/BCH68: J302.51, J303.10
/SiPM_Connector(1-3)/BCH69: J302.53, J303.12
/SiPM_Connector(1-3)/BCH70: J302.55, J303.14
/SiPM_Connector(1-3)/BCH71: J302.57, J303.16
/SiPM_Connector(1-3)/BCH72: J302.61, J303.18
/SiPM_Connector(1-3)/BCH73: J302.63, J303.20
/SiPM_Connector(1-3)/BCH74: J302.65, J303.22
/SiPM_Connector(1-3)/BCH75: J302.67, J303.24
/SiPM_Connector(1-3)/BCH76: J302.69, J303.26
/SiPM_Connector(1-3)/BCH77: J302.71, J303.28
/SiPM_Connector(1-3)/BCH78: J302.73, J303.30
/SiPM_Connector(1-3)/BCH79: J302.75, J303.32
/SiPM_Connector(1-3)/BCH80: J302.79, J303.34
/SiPM_Connector(1-3)/BCH81: J302.81, J303.36
/SiPM_Connector(1-3)/BCH82: J302.83, J303.38
/SiPM_Connector(1-3)/BCH83: J302.85, J303.40
/SiPM_Connector(1-3)/BCH84: J302.87, J303.42
/SiPM_Connector(1-3)/BCH85: J302.89, J303.44
/SiPM_Connector(1-3)/BCH86: J302.91, J303.46
/SiPM_Connector(1-3)/BCH87: J302.93, J303.48
/SiPM_Connector(1-3)/BCH88: J302.97, J303.50
/SiPM_Connector(1-3)/BCH89: J302.99, J303.52
/SiPM_Connector(1-3)/BCH90: J302.101, J303.54
/SiPM_Connector(1-3)/BCH91: J302.103, J303.56
/SiPM_Connector(1-3)/BCH92: J302.105, J303.58
/SiPM_Connector(1-3)/BCH93: J302.107, J303.60
/SiPM_Connector(1-3)/BCH94: J302.109, J303.62
/SiPM_Connector(1-3)/BCH95: J302.111, J303.64
/SiPM_Connector(1-3)/BIAS1: J101.2, J102.76
/SiPM_Connector(1-3)/BIAS2: J101.68, J102.80
/SiPM_Connector(1-3)/BIAS3: J102.75, J103.1
/SiPM_Connector(1-3)/BIAS4: J102.79, J103.67
/SiPM_Connector(1-3)/BIAS5: J201.2, J302.36
/SiPM_Connector(1-3)/BIAS6: J201.68, J302.40
/SiPM_Connector(1-3)/BIAS7: J203.1, J302.35
/SiPM_Connector(1-3)/BIAS8: J203.67, J302.39
/SiPM_Connector(1-3)/BIAS9: J301.2, J302.116
/SiPM_Connector(1-3)/BIAS10: J301.68, J302.120
/SiPM_Connector(1-3)/BIAS11: J302.115, J303.1
/SiPM_Connector(1-3)/BIAS12: J302.119, J303.67
/SiPM_Connector(1-3)/CH0: J101.1, J102.4
/SiPM_Connector(1-3)/CH1: J101.3, J102.6
/SiPM_Connector(1-3)/CH2: J101.5, J102.8
/SiPM_Connector(1-3)/CH3: J101.7, J102.10
/SiPM_Connector(1-3)/CH4: J101.9, J102.12
/SiPM_Connector(1-3)/CH5: J101.11, J102.14
/SiPM_Connector(1-3)/CH6: J101.13, J102.16
/SiPM_Connector(1-3)/CH7: J101.15, J102.18
/SiPM_Connector(1-3)/CH8: J101.17, J102.22
/SiPM_Connector(1-3)/CH9: J101.19, J102.24
/SiPM_Connector(1-3)/CH10: J101.21, J102.26
/SiPM_Connector(1-3)/CH11: J101.23, J102.28
/SiPM_Connector(1-3)/CH12: J101.25, J102.30
/SiPM_Connector(1-3)/CH13: J101.27, J102.32
/SiPM_Connector(1-3)/CH14: J101.29, J102.34
/SiPM_Connector(1-3)/CH15: J101.31, J102.36
/SiPM_Connector(1-3)/CH16: J101.33, J102.40
/SiPM_Connector(1-3)/CH17: J101.35, J102.42
/SiPM_Connector(1-3)/CH18: J101.37, J102.44
/SiPM_Connector(1-3)/CH19: J101.39, J102.46
/SiPM_Connector(1-3)/CH20: J101.41, J102.48
/SiPM_Connector(1-3)/CH21: J101.43, J102.50
/SiPM_Connector(1-3)/CH22: J101.45, J102.52
/SiPM_Connector(1-3)/CH23: J101.47, J102.54
/SiPM_Connector(1-3)/CH24: J101.49, J102.58
/SiPM_Connector(1-3)/CH25: J101.51, J102.60
/SiPM_Connector(1-3)/CH26: J101.53, J102.62
/SiPM_Connector(1-3)/CH27: J101.55, J102.64
/SiPM_Connector(1-3)/CH28: J101.57, J102.66
/SiPM_Connector(1-3)/CH29: J101.59, J102.68
/SiPM_Connector(1-3)/CH30: J101.61, J102.70
/SiPM_Connector(1-3)/CH31: J101.63, J102.72
/SiPM_Connector(1-3)/CH32: J102.84, J201.1
/SiPM_Connector(1-3)/CH33: J102.86, J201.3
/SiPM_Connector(1-3)/CH34: J102.88, J201.5
/SiPM_Connector(1-3)/CH35: J102.90, J201.7
/SiPM_Connector(1-3)/CH36: J102.92, J201.9
/SiPM_Connector(1-3)/CH37: J102.94, J201.11
/SiPM_Connector(1-3)/CH38: J102.96, J201.13
/SiPM_Connector(1-3)/CH39: J102.98, J201.15
/SiPM_Connector(1-3)/CH40: J102.102, J201.17
/SiPM_Connector(1-3)/CH41: J102.104, J201.19
/SiPM_Connector(1-3)/CH42: J102.106, J201.21
/SiPM_Connector(1-3)/CH43: J102.108, J201.23
/SiPM_Connector(1-3)/CH44: J102.110, J201.25
/SiPM_Connector(1-3)/CH45: J102.112, J201.27
/SiPM_Connector(1-3)/CH46: J102.114, J201.29
/SiPM_Connector(1-3)/CH47: J102.116, J201.31
/SiPM_Connector(1-3)/CH48: J102.120, J201.33
/SiPM_Connector(1-3)/CH49: J201.35, J302.2
/SiPM_Connector(1-3)/CH50: J201.37, J302.4
/SiPM_Connector(1-3)/CH51: J201.39, J302.6
/SiPM_Connector(1-3)/CH52: J201.41, J302.8
/SiPM_Connector(1-3)/CH53: J201.43, J302.10
/SiPM_Connector(1-3)/CH54: J201.45, J302.12
/SiPM_Connector(1-3)/CH55: J201.47, J302.14
/SiPM_Connector(1-3)/CH56: J201.49, J302.18
/SiPM_Connector(1-3)/CH57: J201.51, J302.20
/SiPM_Connector(1-3)/CH58: J201.53, J302.22
/SiPM_Connector(1-3)/CH59: J201.55, J302.24
/SiPM_Connector(1-3)/CH60: J201.57, J302.26
/SiPM_Connector(1-3)/CH61: J201.59, J302.28
/SiPM_Connector(1-3)/CH62: J201.61, J302.30
/SiPM_Connector(1-3)/CH63: J201.63, J302.32
/SiPM_Connector(1-3)/CH64: J301.1, J302.44
/SiPM_Connector(1-3)/CH65: J301.3, J302.46
/SiPM_Connector(1-3)/CH66: J301.5, J302.48
/SiPM_Connector(1-3)/CH67: J301.7, J302.50
/SiPM_Connector(1-3)/CH68: J301.9, J302.52
/SiPM_Connector(1-3)/CH69: J301.11, J302.54
/SiPM_Connector(1-3)/CH70: J301.13, J302.56
/SiPM_Connector(1-3)/CH71: J301.15, J302.58
/SiPM_Connector(1-3)/CH72: J301.17, J302.62
/SiPM_Connector(1-3)/CH73: J301.19, J302.64
/SiPM_Connector(1-3)/CH74: J301.21, J302.66
/SiPM_Connector(1-3)/CH75: J301.23, J302.68
/SiPM_Connector(1-3)/CH76: J301.25, J302.70
/SiPM_Connector(1-3)/CH77: J301.27, J302.72
/SiPM_Connector(1-3)/CH78: J301.29, J302.74
/SiPM_Connector(1-3)/CH79: J301.31, J302.76
/SiPM_Connector(1-3)/CH80: J301.33, J302.80
/SiPM_Connector(1-3)/CH81: J301.35, J302.82
/SiPM_Connector(1-3)/CH82: J301.37, J302.84
/SiPM_Connector(1-3)/CH83: J301.39, J302.86
/SiPM_Connector(1-3)/CH84: J301.41, J302.88
/SiPM_Connector(1-3)/CH85: J301.43, J302.90
/SiPM_Connector(1-3)/CH86: J301.45, J302.92
/SiPM_Connector(1-3)/CH87: J301.47, J302.94
/SiPM_Connector(1-3)/CH88: J301.49, J302.98
/SiPM_Connector(1-3)/CH89: J301.51, J302.100
/SiPM_Connector(1-3)/CH90: J301.53, J302.102
/SiPM_Connector(1-3)/CH91: J301.55, J302.104
/SiPM_Connector(1-3)/CH92: J301.57, J302.106
/SiPM_Connector(1-3)/CH93: J301.59, J302.108
/SiPM_Connector(1-3)/CH94: J301.61, J302.110
/SiPM_Connector(1-3)/CH95: J301.63, J302.112
/SiPM_Connector(1-3)/OUT: J101.67, J102.77, J201.67, J301.67, J302.37, J302.117
/SiPM_Connector(1-3)/VDD: J101.65, J102.78, J201.65, J301.65, J302.38, J302.118
/SiPM_Connector(4-6)/BCH0: J402.3, J403.2
/SiPM_Connector(4-6)/BCH1: J402.5, J403.4
/SiPM_Connector(4-6)/BCH2: J402.7, J403.6
/SiPM_Connector(4-6)/BCH3: J402.9, J403.8
/SiPM_Connector(4-6)/BCH4: J402.11, J403.10
/SiPM_Connector(4-6)/BCH5: J402.13, J403.12
/SiPM_Connector(4-6)/BCH6: J402.15, J403.14
/SiPM_Connector(4-6)/BCH7: J402.17, J403.16
/SiPM_Connector(4-6)/BCH8: J402.21, J403.18
/SiPM_Connector(4-6)/BCH9: J402.23, J403.20
/SiPM_Connector(4-6)/BCH10: J402.25, J403.22
/SiPM_Connector(4-6)/BCH11: J402.27, J403.24
/SiPM_Connector(4-6)/BCH12: J402.29, J403.26
/SiPM_Connector(4-6)/BCH13: J402.31, J403.28
/SiPM_Connector(4-6)/BCH14: J402.33, J403.30
/SiPM_Connector(4-6)/BCH15: J402.35, J403.32
/SiPM_Connector(4-6)/BCH16: J402.39, J403.34
/SiPM_Connector(4-6)/BCH17: J402.41, J403.36
/SiPM_Connector(4-6)/BCH18: J402.43, J403.38
/SiPM_Connector(4-6)/BCH19: J402.45, J403.40
/SiPM_Connector(4-6)/BCH20: J402.47, J403.42
/SiPM_Connector(4-6)/BCH21: J402.49, J403.44
/SiPM_Connector(4-6)/BCH22: J402.51, J403.46
/SiPM_Connector(4-6)/BCH23: J402.53, J403.48
/SiPM_Connector(4-6)/BCH24: J402.57, J403.50
/SiPM_Connector(4-6)/BCH25: J402.59, J403.52
/SiPM_Connector(4-6)/BCH26: J402.61, J403.54
/SiPM_Connector(4-6)/BCH27: J402.63, J403.56
/SiPM_Connector(4-6)/BCH28: J402.65, J403.58
/SiPM_Connector(4-6)/BCH29: J402.67, J403.60
/SiPM_Connector(4-6)/BCH30: J402.69, J403.62
/SiPM_Connector(4-6)/BCH31: J402.71, J403.64
/SiPM_Connector(4-6)/BCH32: J402.83, J503.2
/SiPM_Connector(4-6)/BCH33: J402.85, J503.4
/SiPM_Connector(4-6)/BCH34: J402.87, J503.6
/SiPM_Connector(4-6)/BCH35: J402.89, J503.8
/SiPM_Connector(4-6)/BCH36: J402.91, J503.10
/SiPM_Connector(4-6)/BCH37: J402.93, J503.12
/SiPM_Connector(4-6)/BCH38: J402.95, J503.14
/SiPM_Connector(4-6)/BCH39: J402.97, J503.16
/SiPM_Connector(4-6)/BCH40: J402.101, J503.18
/SiPM_Connector(4-6)/BCH41: J402.103, J503.20
/SiPM_Connector(4-6)/BCH42: J402.105, J503.22
/SiPM_Connector(4-6)/BCH43: J402.107, J503.24
/SiPM_Connector(4-6)/BCH44: J402.109, J503.26
/SiPM_Connector(4-6)/BCH45: J402.111, J503.28
/SiPM_Connector(4-6)/BCH46: J402.113, J503.30
/SiPM_Connector(4-6)/BCH47: J402.115, J503.32
/SiPM_Connector(4-6)/BCH48: J402.119, J503.34
/SiPM_Connector(4-6)/BCH49: J503.36, J602.1
/SiPM_Connector(4-6)/BCH50: J503.38, J602.3
/SiPM_Connector(4-6)/BCH51: J503.40, J602.5
/SiPM_Connector(4-6)/BCH52: J503.42, J602.7
/SiPM_Connector(4-6)/BCH53: J503.44, J602.9
/SiPM_Connector(4-6)/BCH54: J503.46, J602.11
/SiPM_Connector(4-6)/BCH55: J503.48, J602.13
/SiPM_Connector(4-6)/BCH56: J503.50, J602.17
/SiPM_Connector(4-6)/BCH57: J503.52, J602.19
/SiPM_Connector(4-6)/BCH58: J503.54, J602.21
/SiPM_Connector(4-6)/BCH59: J503.56, J602.23
/SiPM_Connector(4-6)/BCH60: J503.58, J602.25
/SiPM_Connector(4-6)/BCH61: J503.60, J602.27
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

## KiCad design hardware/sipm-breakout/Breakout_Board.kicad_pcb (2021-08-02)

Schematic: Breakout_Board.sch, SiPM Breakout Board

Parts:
H1, H2, H3, H4: MountingHole_Pad; MountingHole_4.3mm_M4_Pad
J1, J2: Conn_02x34_Odd_Even; SAMTEC_CLM-134-02-F-D
J3, J4: Conn_02x32_Odd_Even; PinHeader_2x32_P2.00mm_Vertical_SMD
J5: Conn_02x04_Odd_Even; PinSocket_2x04_P2.54mm_Vertical
J6: Conn_01x04; PinHeader_1x04_P2.54mm_Vertical
J7, J8, J9, J10, J11, J12, J13, J14, J17, J18, J19, J20, J21, J22, J23, J24: Conn_Coaxial; lemo-EPB.00.250.NTN
J15, J16: Conn_01x01_Female; Banana_Pomona_73099
RN1, RN2, RN3, RN4, RN5, RN6, RN7, RN8: R_Network08_US; RPKG-9

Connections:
/BCH0: J2.2, J4.1, J14.1 (In), RN5.2
/BCH1: J2.4, J4.3, J13.1 (In), RN5.3
/BCH2: J2.6, J4.5, J12.1 (In), RN5.4
/BCH3: J2.8, J4.7, J11.1 (In), RN5.5
/BCH4: J2.10, J4.9, RN5.6
/BCH5: J2.12, J4.11, RN5.7
/BCH6: J2.14, J4.13, RN5.8
/BCH7: J2.16, J4.15, RN5.9
/BCH8: J2.18, J4.17, RN6.2
/BCH9: J2.20, J4.19, RN6.3
/BCH10: J2.22, J4.21, RN6.4
/BCH11: J2.24, J4.23, RN6.5
/BCH12: J2.26, J4.25, RN6.6
/BCH13: J2.28, J4.27, RN6.7
/BCH14: J2.30, J4.29, RN6.8
/BCH15: J2.32, J4.31, RN6.9
/BCH16: J2.34, J4.33, J24.1 (In), RN7.2
/BCH17: J2.36, J4.35, J23.1 (In), RN7.3
/BCH18: J2.38, J4.37, J22.1 (In), RN7.4
/BCH19: J2.40, J4.39, J21.1 (In), RN7.5
/BCH20: J2.42, J4.41, RN7.6
/BCH21: J2.44, J4.43, RN7.7
/BCH22: J2.46, J4.45, RN7.8
/BCH23: J2.48, J4.47, RN7.9
/BCH24: J2.50, J4.49, RN8.2
/BCH25: J2.52, J4.51, RN8.3
/BCH26: J2.54, J4.53, RN8.4
/BCH27: J2.56, J4.55, RN8.5
/BCH28: J2.58, J4.57, RN8.6
/BCH29: J2.60, J4.59, RN8.7
/BCH30: J2.62, J4.61, RN8.8
/BCH31: J2.64, J4.63, RN8.9
/BIAS1: J1.2, J5.1
/BIAS2: J1.68, J5.3
/BIAS3: J2.1, J5.5
/BIAS4: J2.67, J5.7
/CH0: J1.1, J3.1, J10.1 (In), RN1.2
/CH1: J1.3, J3.3, J9.1 (In), RN1.3
/CH2: J1.5, J3.5, J8.1 (In), RN1.4
/CH3: J1.7, J3.7, J7.1 (In), RN1.5
/CH4: J1.9, J3.9, RN1.6
/CH5: J1.11, J3.11, RN1.7
/CH6: J1.13, J3.13, RN1.8
/CH7: J1.15, J3.15, RN1.9
/CH8: J1.17, J3.17, RN2.2
/CH9: J1.19, J3.19, RN2.3
/CH10: J1.21, J3.21, RN2.4
/CH11: J1.23, J3.23, RN2.5
/CH12: J1.25, J3.25, RN2.6
/CH13: J1.27, J3.27, RN2.7
/CH14: J1.29, J3.29, RN2.8
/CH15: J1.31, J3.31, RN2.9
/CH16: J1.33, J3.33, J17.1 (In), RN3.2
/CH17: J1.35, J3.35, J18.1 (In), RN3.3
/CH18: J1.37, J3.37, J19.1 (In), RN3.4
/CH19: J1.39, J3.39, J20.1 (In), RN3.5
/CH20: J1.41, J3.41, RN3.6
/CH21: J1.43, J3.43, RN3.7
/CH22: J1.45, J3.45, RN3.8
/CH23: J1.47, J3.47, RN3.9
/CH24: J1.49, J3.49, RN4.2
/CH25: J1.51, J3.51, RN4.3
/CH26: J1.53, J3.53, RN4.4
/CH27: J1.55, J3.55, RN4.5
/CH28: J1.57, J3.57, RN4.6
/CH29: J1.59, J3.59, RN4.7
/CH30: J1.61, J3.61, RN4.8
/CH31: J1.63, J3.63, RN4.9
/OUT: J1.67, J6.3
/VDD: J1.65, J6.1
GND: H1.1, H2.1, H3.1, H4.1, J1.4, J1.6, J1.8, J1.10, J1.12, J1.14, J1.16, J1.18, J1.20, J1.22, J1.24, J1.26, J1.28, J1.30, J1.32, J1.34, J1.36, J1.38, J1.40, J1.42, J1.44, J1.46, J1.48, J1.50, J1.52, J1.54, J1.56, J1.58, J1.60, J1.62, J1.64, J1.66, J2.3, J2.5, J2.7, J2.9, J2.11, J2.13, J2.15, J2.17, J2.19, J2.21, J2.23, J2.25, J2.27, J2.29, J2.31, J2.33, J2.35, J2.37, J2.39, J2.41, J2.43, J2.45, J2.47, J2.49, J2.51, J2.53, J2.55, J2.57, J2.59, J2.61, J2.63, J2.65, J3.2, J3.4, J3.6, J3.8, J3.10, J3.12, J3.14, J3.16, J3.18, J3.20, J3.22, J3.24, J3.26, J3.28, J3.30, J3.32, J3.34, J3.36, J3.38, J3.40, J3.42, J3.44, J3.46, J3.48, J3.50, J3.52, J3.54, J3.56, J3.58, J3.60, J3.62, J3.64, J4.2, J4.4, J4.6, J4.8, J4.10, J4.12, J4.14, J4.16, J4.18, J4.20, J4.22, J4.24, J4.26, J4.28, J4.30, J4.32, J4.34, J4.36, J4.38, J4.40, J4.42, J4.44, J4.46, J4.48, J4.50, J4.52, J4.54, J4.56, J4.58, J4.60, J4.62, J4.64, J6.2, J6.4, J7.2 (Ext), J8.2 (Ext), J9.2 (Ext), J10.2 (Ext), J11.2 (Ext), J12.2 (Ext), J13.2 (Ext), J14.2 (Ext), J16.1, J17.2 (Ext), J18.2 (Ext), J19.2 (Ext), J20.2 (Ext), J21.2 (Ext), J22.2 (Ext), J23.2 (Ext), J24.2 (Ext), RN1.1, RN2.1, RN3.1, RN4.1, RN5.1, RN6.1, RN7.1, RN8.1
unnamed: J5.2, J5.4, J5.6, J5.8, J15.1

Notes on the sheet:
Rev B: Flip J2 L/R Modify J5 pinout to make Ed happy
Banana for Bias input
Jumper select bias voltages

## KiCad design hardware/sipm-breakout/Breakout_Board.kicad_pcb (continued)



Board: 2 copper layers, 100.0 x 100.0 mm, 36 parts (10 on the bottom side), 72 nets.

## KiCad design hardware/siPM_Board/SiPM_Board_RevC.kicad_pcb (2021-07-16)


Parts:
C1, C2, C3, C4, C5, C6, C7, C8, C9, C10, C11, C12, C13, C14, C15, C16, C17: 100nF; C_0603_1608Metric_Pad1.08x0.95mm_HandSolder
H1, H2, H3, H4: MountingHole; SMTSO-nut-0-80
J1, J2: Conn_02x34_Odd_Even; MW-34-03-G-D-245-065-ES
U1: LM94021; Texas_R-PDSO-G6
U2, U3, U4, U5: S14161-6050HS-04

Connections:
/BIAS1: C1.1, C3.1, C5.1, C7.1, J1.2, U2.B1 (A1K), U2.B3 (A2K), U2.B5 (A3K), U2.B7 (A4K), U2.D1 (B1K), U2.D3 (B2K), U2.D5 (B3K), U2.D7 (B4K), U2.F2 (C1K), U2.F4 (C2K), U2.F6 (C3K), U2.F8 (C4K), U2.H2 (D1K), U2.H4 (D2K), U2.H6 (D3K), U2.H8 (D4K)
/BIAS2: C2.1, C4.1, C6.1, C8.1, J1.68, U3.B1 (A1K), U3.B3 (A2K), U3.B5 (A3K), U3.B7 (A4K), U3.D1 (B1K), U3.D3 (B2K), U3.D5 (B3K), U3.D7 (B4K), U3.F2 (C1K), U3.F4 (C2K), U3.F6 (C3K), U3.F8 (C4K), U3.H2 (D1K), U3.H4 (D2K), U3.H6 (D3K), U3.H8 (D4K)
/BIAS3: C10.1, C12.1, C14.1, C16.1, J2.1, U4.B1 (A1K), U4.B3 (A2K), U4.B5 (A3K), U4.B7 (A4K), U4.D1 (B1K), U4.D3 (B2K), U4.D5 (B3K), U4.D7 (B4K), U4.F2 (C1K), U4.F4 (C2K), U4.F6 (C3K), U4.F8 (C4K), U4.H2 (D1K), U4.H4 (D2K), U4.H6 (D3K), U4.H8 (D4K)
/BIAS4: C11.1, C13.1, C15.1, C17.1, J2.67, U5.B1 (A1K), U5.B3 (A2K), U5.B5 (A3K), U5.B7 (A4K), U5.D1 (B1K), U5.D3 (B2K), U5.D5 (B3K), U5.D7 (B4K), U5.F2 (C1K), U5.F4 (C2K), U5.F6 (C3K), U5.F8 (C4K), U5.H2 (D1K), U5.H4 (D2K), U5.H6 (D3K), U5.H8 (D4K)
/OUT: J1.67, U1.3 (OUT)
/VDD: C9.1, J1.65, U1.4 (VDD)
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

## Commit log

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2021-02-06 Fixed the bias wiring
    [SiPM_Board.sch]
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2021-02-09 All footprints are made
    [SiPM_Board.kicad_pcb, SiPM_Board.sch]
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2021-02-16 Capacitor Grounding Fixed
    [SiPM_Board.kicad_pcb]
2021-02-17 Is the placement of extra capacitors correct?
    [SiPM_Board.kicad_pcb]
2021-02-19 Added Extra Capacitor Footprints and Fixed Tracing
    [SiPM_Board.kicad_pcb]
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2021-02-22 Fixed reference designators
    [SiPM_Board.kicad_pcb]
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2021-02-24 Added P/N and Supplier
    [SiPM_Board.sch]
2021-02-24 fixing file layout
    [readout_slice.kicad_pcb, readout_slice.sch]
2021-02-24 auto push run at Wed Feb 24 11:18:27 EST 2021
    [readout_slice.sch]
2021-02-24 Modified Temp. Sensor Footprint
    [SiPM_Board.kicad_pcb]
2021-02-24 working more on readout slice
    [power.sch]
2021-02-26 auto push run at Fri Feb 26 15:29:40 EST 2021
    [power.sch, readout_slice.sch]
2021-02-28 auto push run at Sat Feb 27 19:08:26 EST 2021
    [power.sch, readout_slice.sch]
2021-03-01 Update gerbers, add BOM as CSV file
    [SiPM_Board-B_Cu.gbr, SiPM_Board-B_Mask.gbr, SiPM_Board-B_Paste.gbr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]
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2021-03-01 Made Breakout Board Schematic
    [Breakout_Board.sch]
2021-03-01 Initial footprint mapping, add coax connectors
    [Breakout_Board.kicad_pcb, Breakout_Board.sch]
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2021-03-03 add resistor packs, fix netlist
    [Breakout_Board.kicad_pcb, Breakout_Board.sch]
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2021-03-04 Possibly final break board
    [Breakout_Board.kicad_pcb]
2021-03-09 auto push run at Tue Mar 9 10:08:09 EST 2021
    [Sheet_connectivity.sch, power.sch, readout_slice.sch]
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2021-03-09 more work on moving FPGA components around
    [FPGA.sch, connectivity.sch, power.sch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]
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2021-03-10 more work on readout connectivity
    [FPGA.sch, connectivity.sch, power.sch]
2021-03-10 added schematics for refrence for readout_slice
    [connectivity.sch]
2021-03-10 added position file for sipm_board
    [power.sch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]
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2021-03-12 more work on readout_slice
    [FPGA.sch, connectivity.sch, power.sch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]
2021-03-15 working more on readout_slice schematic
    [FPGA.sch, connectivity.sch, power.sch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]
2021-03-15 starting to layout readout board more
    [readout_slice.sch]
2021-03-15 auto push run at Mon Mar 15 12:11:48 EDT 2021
    [Citiroc-FPGA.sch, FPGA-Connectivity.sch, FPGA.sch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]
2021-03-17 Rev A breakout board gerbers
    [Breakout_Board-job.gbrjob]
2021-03-17 readout_slice is more ordered now
    [Citiroc-FPGA.sch, Citiroc-power.sch, FPGA-Connectivity.sch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]
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2021-03-17 added notes to schematics for readout_slice
    [FPGA-Connectivity.sch, ZX2-connectivity.sch, ZX2-power.sch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]
2021-03-22 need to fix one rescure in readout_slice
    [ADC_LVDS.sch, AXI-C2C.sch, Breakout_Board.sch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]
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2021-03-22 getting rid of readout_slice rescue
    [Citiroc-FPGA-2.sch, Citiroc-in-1.sch, Citiroc-in-2.sch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]
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2021-04-02 more progress on readout_slice
    [ADC_LVDS.sch, AXI-C2C.sch, Citiroc-FPGA-2.sch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]
2021-04-02 moving some things on readout slice
    [ADC_LVDS.sch, AXI-C2C.sch, FPGA.sch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]
2021-04-08 Signal tracing on Backplane Prototype
    [backplane-prototype.kicad_pcb]
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2021-04-09 auto push run at Fri Apr 9 14:02:10 EDT 2021
    [ADC_LVDS.sch, AXI-C2C.sch, Citiroc-FPGA-2.sch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]
2021-04-09 auto push run at Fri Apr 9 14:13:27 EDT 2021
    [ADC_LVDS.sch, FPGA-3V3-Bank.sch, readout_slice.sch]
2021-04-09 auto push run at Fri Apr 9 16:59:37 EDT 2021
    [AXI-C2C.sch, Citiroc-in-1.sch, FPGA-Connectivity.sch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]
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2021-04-14 auto push run at Wed Apr 14 09:17:01 EDT 2021
    [ADC_LVDS.sch, Citiroc-FPGA-2.sch, Citiroc-in-1.sch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]
2021-04-14 auto push run at Wed Apr 14 11:00:44 EDT 2021
    [Citiroc-FPGA-2.sch, FPGA-LVDS.sch, FPGA-power.sch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]
2021-04-14 auto push run at Wed Apr 14 11:08:32 EDT 2021
    [Citiroc-FPGA-2.sch, FPGA-3V3-Bank.sch, Misc.sch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]
2021-04-14 Backplane Prototype Layour Made
    [backplane-prototype.kicad_pcb]
2021-04-19 Backplane Prototype (Rev A) Completed
    [backplane-prototype-B_Cu.gbr, backplane-prototype-B_Mask.gbr, backplane-prototype-B_Paste.gbr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]
2021-04-20 auto push run at Tue Apr 20 18:13:16 EDT 2021
    [Citiroc-in-1.sch, FPGA-LVDS.sch, FPGA-power.sch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]
2021-04-21 auto push run at Wed Apr 21 10:59:57 EDT 2021
    [Citiroc-FPGA-2.sch, Citiroc-in-1.sch, Citiroc-in-2.sch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]
2021-04-21 auto push run at Wed Apr 21 11:14:23 EDT 2021
    [Citiroc-FPGA-2.sch, Citiroc-power.sch, FPGA-3V3-Bank.sch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]
2021-04-21 auto push run at Wed Apr 21 11:17:43 EDT 2021
    [Citiroc-in-1.sch, FPGA-power.sch]
2021-04-21 auto push run at Wed Apr 21 11:22:25 EDT 2021
    [FPGA-power.sch, power.sch]
2021-04-28 removed zx2, added sfp for serdes from dan's vice board
    [Citiroc-FPGA-2.sch, Citiroc-in-1.sch, Citiroc-in-2.sch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]
2021-04-28 auto push run at Wed Apr 28 10:36:58 EDT 2021
    [Citiroc-FPGA-2.sch, Citiroc-in-1.sch, Citiroc-in-2.sch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]
2021-04-28 auto push run at Wed Apr 28 10:51:45 EDT 2021
    [FPGA-Connectivity.sch, FPGA_SERDES.sch]
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2021-05-10 Rectifying The SiPM Board
    [SiPM_Connector(1).sch, SiPM_Connector(2).sch, SiPM_Connector(3).sch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]
2021-05-10 SiPM Board RevB Completed
    [SiPM_Board_RevB.kicad_pcb]
2021-05-12 notes from meeting with tejava
    [FPGA-Connectivity.sch, power.sch, readout_slice.sch]
2021-05-13 Backplane Prototype BOM added
    [backplane-prototype.csv]
2021-05-13 SiPM Board RevC Layout Completed
    [SiPM_Board_RevC.kicad_pcb, SiPM_Board_RevC.sch]
2021-05-14 Backplane (9 SiPM Array) Schematic Complete
    [SiPM_Board_RevB-B_Cu.gbr, SiPM_Board_RevB-B_Mask.gbr, SiPM_Board_RevB-B_SilkS.gbr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]
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2021-06-30 Fixing SiPM Libraries
    [SiPM_Board_RevC.sch]
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2021-07-01 Branch to add PEM nuts to SiPM board
    [9x9backplane-Edge_Cuts.dxf, 9x9backplane-F_Mask.dxf, SiPM_Board.sch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]
2021-07-01 Netlist errors fixed
    [Backplane.sch, CITIROC_1.sch, CLK_TRIG.sch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]
2021-07-01 Netlist issues fixed
    [Backplane.sch, Trenz_Module.sch, readout_trenz.kicad_pcb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]
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2021-07-29 before rework
    [backplane_conn.sch]
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
